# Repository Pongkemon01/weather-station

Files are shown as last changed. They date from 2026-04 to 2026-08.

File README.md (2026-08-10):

# Robin Weather Station

An STM32L476RG-based weather station with cellular data upload, field-O.T.A. firmware updates, a FastAPI ingest + administration server, and a USB-connected Qt desktop configuration utility.

Three distinct codebases live in this repository and share one data story:

1. **Firmware** — bare-metal-ish FreeRTOS application + a separate bootloader for the STM32L476RG.
2. **Server** — FastAPI service that ingests weather records over mTLS, serves firmware images over OTA, and hosts an HTMX admin UI.
3. **Host application** — "Robin WSC", a Qt 6 Widgets desktop tool for connecting to a station over USB CDC and configuring/reading it locally.

Documentation, implementation plans, and as-built test results are in the repo root (see [Documentation](#documentation)).

---

## Hardware & System Context

| Component | Part / Tool |
|---|---|
| MCU | STM32L476RG (Cortex-M4F, 1 MB Flash, 128 KB SRAM) |
| FRAM | CY15B116QN 2 MB (SPI1) — persistent sensor ring DB + OTA staging |
| Modem | SIMCom A7670E LTE (USART3, `AT+HTTP*` only — no CCH/CHTTPS) |
| Sensors | BMP390 (I2C2), SHT45 (I2C2); RS-485 Modbus light (0x01) + rain (0x02) via USART1 |
| UI | LCD + LEDs + buttons through MCP23017 I/O expander (I2C1) |
| Storage | SD card (SDMMC1, FatFs) beside FRAM |
| RTOS | FreeRTOS (CMSIS-RTOS V2) |
| Peripherals | USART1 RS-485 Modbus, USART2 debug console, USART3 A7670 AT, USB OTG FS TinyUSB CDC |

**Sensor → storage → upload pipeline:** `maintask` reads sensors every second, packs readings (Q9.7 fixed-point), stores them in the SPI FRAM ring database and on SD; `ssluploadtask` POSTs a snapshot to the server at noon and midnight over the A7670 LTE modem.

**OTA:** an 8-state OTA manager task downloads firmware images over the modem in 512-byte chunks, verifies SHA-256/CRC-32, and writes them to the FRAM image buffer; the bootloader applies the update to the application flash on next reset. OTA campaigns are controlled from the server admin UI and gated by rollout version strings (`W.<sec>`).

**Local access (USB):** the station enumerates as a USB CDC device (TinyUSB on OTG FS). This USB port serves two purposes: it carries the binary configuration/readout protocol that the Robin WSC desktop app uses to connect to a station (via `QSerialPort`), and it acts as a secondary debug/console channel alongside USART2.

### Internal Flash Layout

```
0x08000000  Bootloader  (32 KB, pages 0–15, Bank 1)   RDP1 + write-protected
0x08008000  Application (480 KB, pages 16–255, Bank 1) ldscript_app.ld
0x08080000  Bank 2      (512 KB — reserved)
```

### Memory Constraints

| Region | Limit |
|---|---|
| App code (`.text` + `.rodata`) | ≤ 480 KB (linker `ASSERT`) |
| App data (`.data` + `.bss`) | ≤ 96 KB (SRAM1) |
| Bootloader flash | 32 KB |
| OTA static chunk buffer | ≤ 512 B |

Current build budget: app ~9.3 % flash / ~22.7 % RAM; bootloader ~0.7 % / ~2.8 % (see `IMPLEMENTATION_STATUS.md`).

---

## Repository Layout

| Path | What it is |
|---|---|
| `Src/` | Application source (CubeMX-generated + `USER CODE` guards). `freertos.c` creates all tasks. |
| `Inc/` | Application headers |
| `lib/` | Libraries: `sensors/` (BMP390, SHT45, Modbus, rain/light), `A7670/` (AT channel, HTTPS upload, SSL OTA download), `SPI_FRAM/` (raw SPI + ring DB), `user_interface/` (MCP23017, LCD), `usart_subsystem/`, `time/`, `utils/` (weather_data, fixed-point), `tinyusb/` (vendored) |
| `shared/` | Compiled into **both** firmware and bootloader: `fram_addresses.h` (single FRAM source of truth), dual-copy `ota_control_block`, CRC-32, SHA-256 |
| `bootloader/` | Separate PlatformIO env, bare-metal (no FreeRTOS): image apply, OCB read/write, FRAM bounce |
| `html/` | FastAPI server (mTLS ingest, OTA endpoints, admin JWT + RBAC, HTMX UI, Prometheus metrics) |
| `server_deployment/`| One-shot shell setup scripts for the Debian host (DB, nginx, systemd, PKI, monitoring) |
| `server_test/` | Python black-box verifiers against the deployed server |
| `host/` | "Robin WSC" — Qt 6.8 Widgets + QSerialPort desktop app (C++17, CMake, ctest tests) |
| `test/` | Extra host-side suites (e.g. OTA size guard — `test_ota_size_guard/`) |
| `Altium Schematics/`| Hardware schematic source |

### FreeRTOS Tasks (firmware)

| Task | File | Period | Priority | Role |
|---|---|---|---|---|
| `UsbLoopTask`  | `freertos.c` | event | High | TinyUSB device loop |
| `cdc_task` | `Src/cdctask.c` | event | High | USB CDC binary protocol (used by the host app) |
| `maintask` | `Src/maintask.c` | 1 s | Normal | Sensor → FRAM + SD |
| `uitask` | `Src/uitask.c` | 20 ms | Normal | LCD refresh, LEDs, button debounce |
| `ucctask` | `Src/ucctask.c` | 100 ms| Normal | LCD menu |
| `ssluploadtask`| `Src/ssluploadtask.c`  | noon+midnight | Normal | HTTPS upload; notifies OTA manager |
| `OtaManagerTask`| `Src/ota_manager_task.c` | after upload | Normal | OTA state machine |
| `WatchdogTask` | `Src/watchdog_task.c`  | 500 ms| High | Per-task heartbeat + IWDG refresh |

---

## Building

Built with **PlatformIO** (`nucleo_l476rg` env, STM32Cube framework). On Windows use `platformio`; on Linux/macOS the WSL helpers below also target WSL2 gcc.

| Action | Command |
|---|---|
| Build application | `platformio run` |
| Build bootloader  | `pio run -e bootloader` |
| Flash application | `platformio run -t upload` |
| Flash bootloader  | `pio run -e bootloader -t upload` |
| Lint | `scripts/lint.sh` (clang-format + cpplint) |
| Unit tests (host, mocked HAL) | `wsl bash //scripts/run_native_tests.sh` |
| RAM usage report  | `scripts/monitor_ram.sh` (budget ≤ 96 KB) |
| Size check | `pio run -t size` |
| Serial monitor | `pio device monitor -b 115200` (USART2 console) |

**Host app (`host/`):** CMake + `ctest`; tests pass cleanly (frame parser, Q9.7 conversion, device controller). Portable Windows build via windeployqt is packaged under `host/packaging/`.

**Server:** deployed by `bash html/scripts/deploy.sh` (scp to the host; the server has no git repo). Environment setup is scripted in `server_deployment/` (`01_setup_server.sh` … `full_setup.sh`) for a Debian host with PostgreSQL 17 + TimescaleDB, nginx mTLS termination, and systemd unit.

---

## Documentation

| Doc | Covers |
|-----|---|
| `CLAUDE.md` | Project conventions, directory map, peripheral allocation, task map, coding standards, "must never do" rules. **Read this first.** |
| `IMPLEMENTATION_STATUS.md` | Single source of truth for phase completion and build budgets |
| `OTA_Firmware_Architecture.md` | Firmware OTA: FRAM layout, state machine, bootloader, A7670 modem flow |
| `Server_Architecture.md` | Server: mTLS ingest, OTA endpoints, slot algorithm, DB schema |
| `Server_Implementation_Plan.md` / `User_Management_Implementation_Plan.md` | Server phase plans |
| `Server_Test_Plan.md` / `User_Management_Test_Plan.md` | Black-box verifier coverage |
| `USART_Subsystem_Migration_Plan.md` | UART subsystem plan |
| `https_manual.md`, `ntp_manual.md` | A7670E AT command references (vendor) |
| `host/host_implementation_plan.md`, `host/CLAUDE.md` | Host app plan & conventions |

---

## Status (as of `IMPLEMENTATION_STATUS.md`)

- **Firmware:** OTA phases P0–P3.2 implemented; remaining work is hardware integration/field testing (P1/P2/P3/P4 items). Open risk **R-12**: verify embedded cert arrays in `*_der.c` are DER (not PEM) bytes before the next fleet build.
- **Server:** all phases complete (S0–S11), including mTLS ingestion, OTA campaigns, admin RBAC, and monitoring.
- **User management:** complete (UM1–UM5).
- **Host app:** complete (Ph0–Ph9), all ctest suites pass.

Security-sensitive components use mTLS (device ingest), JWT + RBAC (admin), RDP1 + write-protection on the bootloader, and Ed25519-signed firmware images.

---

## License

See `LICENSE` in the repository root.

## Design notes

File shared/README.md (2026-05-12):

# shared/ - Robin Weather Station wire protocol

This directory holds the **single source of truth** for the wire protocol
spoken between the Robin Weather Station (STM32L476RG + TinyUSB + FreeRTOS)
and the host configurator application (Qt 6 on Windows / Linux / macOS).

The same `.h` files compile cleanly under:

- `arm-none-eabi-gcc` (firmware target)
- MinGW-w64 GCC (Windows host)
- System GCC (Linux host)
- Apple Clang (macOS host)

## Files

| File | Purpose |
|---|---|
| `protocol_compat.h` | Portability shims: `PACKED`, `STATIC_ASSERT`, endianness guard |
| `protocol_version.h` | Protocol version macros (`ROBIN_PROTOCOL_VERSION_U16`, etc.) |
| `protocol.h` | Authoritative wire-format spec: framing constants, opcodes, error codes, wire structs |

## What's NOT here

- **No CRC.** The protocol relies on USB-CDC's own packet CRC and the
  magic/footer framing for integrity. The firmware's `cdctask.c` does not
  compute a payload CRC; the host must not either.
- **No length field on the wire.** Payload length is implied by the command
  opcode. The receiving side knows how many bytes to read.

## Frame format

```
+---------+---------+---------+----------------------------+---------+---------+
| MAGIC_H | MAGIC_L |   CMD   |         PAYLOAD            | FOOT_H  | FOOT_L  |
|  1 byte |  1 byte |  1 byte |     0..216 bytes           |  1 byte |  1 byte |
+---------+---------+---------+----------------------------+---------+---------+

Host -> Device:   MAGIC = 0xDC 0xB1   FOOTER = 0x23 0x4E   (~MAGIC byte-wise)
Device -> Host:   MAGIC = 0x55 0xAA   FOOTER = 0xAA 0x55
```

All multi-byte numeric fields are **little-endian** (matches STM32 native
order; no byte-swapping needed on x86_64 or ARM64 desktop hosts). The
`__BYTE_ORDER__` check in `protocol_compat.h` enforces this at compile time.

## Commands

| Code | Name | H->D payload | D->H response |
|---|---|---|---|
| `0x01` | `REQ_WEATHER` | (empty) | `Weather_Data_Packed_t` (18B) |
| `0x02` | `REQ_META` | (empty) | `Meta_Data_t` (216B) |
| `0x03` | `SET_META` | `Meta_Data_t` (216B) | ACK echoing `0x03` or NAK + err |
| `0x04` | `SET_RTC` | `RTC_DateTime_t` (6B) | ACK echoing `0x04` or NAK + err |
| `0x05` | `REQ_STATUS` | (empty) | `System_Ready_Status_t` (12B) |
| `0x06` | `DB_FLUSH` | (empty) | ACK echoing `0x06` or NAK + err |
| `0x07` | `SYS_RESET` | (empty) | ACK echoing `0x07`, link then drops |
| `0xFE` | `ACK` | (device only) | 1 byte echoed command code |
| `0xFF` | `NAK` | (device only) | 1 byte error code |

## NAK error codes

| Code | Name | Meaning |
|---|---|---|
| `0x01` | `UNKNOWN_CMD` | CMD byte was not a recognized opcode |
| `0x02` | `INVALID_FOOTER` | One or both footer bytes did not match `~MAGIC` |
| `0x03` | `WRITE_FAILED` | Device-side persistence failed (FRAM, RTC, etc.) |
| `0x04` | `INVALID_DATA` | Payload contents were rejected |

## Wire data types

| Type | Size | Notes |
|---|---|---|
| `RTC_DateTime_t` | 6 B | year/month/day/hours/minutes/seconds, all `uint8_t` |
| `Weather_Data_Packed_t` | 18 B | `time_stamp` is Y2K epoch; sensor fields are Q9.7 fixed-point (`int16_t` / 128.0) |
| `Meta_Data_t` | 216 B | Station configuration; treat as opaque round-trip from host |
| `System_Ready_Status_t` | 12 B | 12 × `uint8_t` boolean readiness flags |

The sizes above are enforced at compile time by `STATIC_ASSERT` in
`protocol.h`. **If any of those static asserts ever fires, the protocol
is broken and host and firmware will not interoperate.** Treat a failing
assert as a release blocker.

## Adding new commands or fields

- **MINOR version bump** is appropriate for: new opcode that older firmware/
  host can safely ignore; new field appended (never inserted) to an existing
  struct.
- **MAJOR version bump** is required for: field reorder, field removal,
  opcode renumbering, magic/footer change, type change.

Either way: update `protocol_version.h` and bump the appropriate macro.

## Why no CRC?

The firmware author chose to rely on the USB-CDC transport's own data
integrity (USB CRC on every bulk packet, automatic retransmission on
errors) plus the start/end magic framing. For a wired full-speed USB
link at 12 Mbit/s this is reasonable. If the protocol is ever extended
to run over a less-reliable transport (wireless, RS-485, etc.) a CRC
would need to be added in a MAJOR version bump.

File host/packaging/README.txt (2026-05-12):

Robin Weather Station Configurator
==================================

Version:      1.0.0
Manufacturer: RobinLab-KU

About
-----

This application is the configuration and monitoring utility for the
Robin Weather Station. It communicates with the device over USB.

Installation
------------

No installation is required.

   1. Extract this folder to any location you like (your Desktop, a USB
      stick, or a network share all work).
   2. Connect the Robin Weather Station to your computer via USB.
   3. Double-click "robin_wsc.exe".

To remove the application, simply delete this folder. No registry entries
or system files are created.

Supported operating systems
---------------------------

   * Windows 10 (build 1809 or later)
   * Windows 11

USB device identification
-------------------------

The Robin Weather Station identifies itself with the following USB IDs:

   Vendor ID:  0x1209  (pid.codes open hardware allocation)
   Product ID: 0xDCB1

The application searches for any connected device with this VID/PID pair.

Open source acknowledgements
----------------------------

This application is built with the Qt framework (https://www.qt.io/),
used under the terms of the GNU Lesser General Public License v3 (LGPLv3).
See COPYING.LGPLv3.txt in this folder for the full Qt license text.

Qt source code is available from https://www.qt.io/download-open-source

The Qt libraries distributed with this application (Qt6Core.dll,
Qt6Gui.dll, Qt6Widgets.dll, Qt6SerialPort.dll, and the qwindows.dll
platform plugin) are unmodified copies of the official Qt 6 release.

Support
-------

For support, please contact RobinLab-KU.

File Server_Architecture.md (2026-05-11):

# IoT Data Server — Architecture

Fleet: 300–1000 STM32L476RG + A7670E LTE devices · 2× daily sensor uploads + pull-model OTA.
Production host: `akp@robin-gpu.cpe.ku.ac.th` (Ubuntu, PG 17 + TimescaleDB 2.27.0-dev from source).
Phase status: `IMPLEMENTATION_STATUS.md`. Implementation plan: `Server_Implementation_Plan.md`. Test plan: `Server_Test_Plan.md`.

---

## 1. Stack

| Component | Choice | Why |
|---|---|-----|
| Language | Python 3.13 | Binary protocol parsing, async I/O |
| Web framework | FastAPI | Async, OpenAPI |
| Reverse proxy | Nginx | mTLS termination at scale |
| DB | PostgreSQL 17 + TimescaleDB | Hypertable + compression for `weather_records` |
| Admin UI | FastAPI + HTMX + Jinja2 | Server-rendered, no SPA build |
| Metrics / logs  | Prometheus + Loki + Promtail + Grafana | `/metrics` bound to 127.0.0.1 |

---

## 2. Authentication

Two distinct models. Devices use mTLS; admins use username/password → JWT. Never mix.

### 2.1 Devices (mTLS, private CA)

| Aspect | Setting |
|---|---|
| Trust anchor | Private intermediate CA (`{html_dir}/pki/private_ca_chain.pem`) |
| Cert scope | One shared **fleet** client cert (CN `iot-fleet`). No per-device CN. |
| Device identity | Payload `(region_id, station_id)` for ingest; `?id=rrrsss` query param for OTA |
| Modem cert format | **DER binary** (no PEM headers). Convert via `openssl x509/rsa -outform DER`. |
| TLS | 1.3 preferred; 1.2 fallback |
| CRL | `{html_dir}/pki/ca.crl`, refreshed weekly by `scripts/refresh_crl.sh`. **Must contain intermediate + root CRLs** (nginx `ssl_crl` validates every chain level). |
| Cert rotation | Fleet client cert: 365 days. Server TLS cert: 365 days. Intermediate CA: annual audit. Root CA: offline, 5-year rotation. |

Embedded cert arrays (`lib/A7670/*_der.c`) loaded onto the modem via `AT+CCERTDOWN` on each cold boot:

| File | Array | Contents |
|---|---|---|
| `server_der.c` | `server_der[]` | Intermediate CA DER (trust anchor for server TLS) |
| `client_der.c` | `client_der[]` | Fleet client cert DER |
| `client_key_der.c` | `client_key_der[]` | Fleet private key DER |

**Revocation = fleet-wide.** Revoking the fleet cert blocks every device. To rotate: re-issue cert, regenerate DER + C arrays, rebuild, reflash all units.

### 2.2 Admins (JWT)

| Aspect | Setting |
|---|---|
| Trust anchor | Let's Encrypt (server cert only — `ssl_verify_client off`) |
| Login | `POST /admin/login` → bcrypt verify → HS256 JWT (24 h) in `access_token` cookie (HttpOnly, SameSite=strict) |
| Auth header | UI: cookie. API: `Authorization: Bearer`. |
| RBAC | viewer (0) < operator (1) < admin (2). Enforced via `require_role` dependency. |
| CSRF | HMAC double-submit on every form mutation (`app/auth/csrf.py`). |
| Password reset | Out-of-band (admin updates DB row directly). |

---

## 3. Data Protocols

### 3.1 Ingest — binary packed struct

```
Header (5 B):  uint16 region_id, uint16 station_id, uint8 chunk_count
Body  (18 B × chunk_count):  Weather_Data_Packed_t
  - uint32 ts                (Y2K epoch — seconds since 2000-01-01 UTC)
  - int16  temperature       (S9.7 fixed-point — see lib/utils/fixedptc.h)
  - int16  humidity          (S9.7)
  - int16  pressure          (S9.7)
  - uint16 light_par         (µmol/s·m², 0–2500, no scaling)
  - int16  rainfall          (S9.7)
  - int16  dew_point         (S9.7)
  - int16  bus_value         (S9.7)
```

S9.7: sign bit + 9-bit whole + 7-bit fraction → float = `int_value / 128.0`.

**Idempotency key:** `"{region:03d}{station:03d}:{first_sample_ts.isoformat()}"` stored in `ingest_log`. Same payload twice → `{"status": "duplicate"}` returned, no second insert.

**Schema (full):**

```sql
CREATE TABLE devices (
  id          SERIAL       PRIMARY KEY,
  region_id   SMALLINT     NOT NULL,
  station_id  SMALLINT     NOT NULL,
  last_seen   TIMESTAMPTZ,
  created_at  TIMESTAMPTZ  DEFAULT now(),
  UNIQUE (region_id, station_id)
);

CREATE TABLE weather_records (
  time        TIMESTAMPTZ  NOT NULL,
  device_id   INT          NOT NULL REFERENCES devices(id),
  temperature REAL, humidity REAL, pressure REAL,
  light_par   SMALLINT,
  rainfall    REAL, dew_point REAL, bus_value REAL
);
SELECT create_hypertable('weather_records', 'time');
ALTER TABLE weather_records SET (
  timescaledb.compress,
  timescaledb.compress_segmentby = 'device_id'
);
SELECT add_compression_policy('weather_records', INTERVAL '7 days');

CREATE TABLE ingest_log (
  idempotency_key VARCHAR(320) PRIMARY KEY,
  recorded_at     TIMESTAMPTZ DEFAULT now()
);
```

### 3.2 OTA — three-phase pull model

Device builds URLs from `UPDATE_PATH + "/"`. All device traffic shares `/api/v1/weather/` (Q-S1 Option B): one Nginx location, one rate-limit zone.

| Phase | URL | Behavior |
|---|-----|---|
| 1. Version + size | `GET <update_path>/?id=rrrsss` | HTML body containing `V.#####:L.$$$$$$$:H.<sha256hex>:W.<seconds>`. `W.0` = download now; `W>0` = skip cycle. Missing `:W.` = `W.0` (back-compat). |
| 2. Chunk download | `GET <update_path>/get_firmware?offset=X&length=Y&id=rrrsss` | Returns `Y` bytes + 4-byte little-endian CRC-32/MPEG-2 trailer. Length clamped to `[1, 512]`; `offset + length > size` → 416. Out-of-slot device → `429 Retry-After: <sec>`. |
| 3. Install | (Device-side) | OCB written; reboot; bootloader programs Flash; `ota_confirm_success()` within 60 s or rollback. |

### 3.3 Rollout slot algorithm

Problem: 1000 devices × 512 KB unthrottled ≈ 4.5 Gbit burst, exceeds VPS cap. A7670E firmware does not follow HTTP 302 → no object-storage offload. Solution: deterministic 20-slot schedule over 10 days, flatten to ~90 KB/s peak.

```python
def compute_wait(device_id: str, campaign) -> int:
    """Returns seconds the device must wait. 0 = download now."""
    slot_len  = campaign.slot_len_sec           # frozen at creation; default 43200 = 12 h
    num_slots = campaign.rollout_window_days * 2  # default 20
    elapsed   = (now_utc - campaign.rollout_start).total_seconds()
    now_slot  = min(num_slots - 1, max(0, int(elapsed // slot_len)))
    dev_slot  = zlib.crc32(device_id.encode("ascii")) % num_slots
    return 0 if dev_slot <= now_slot else (dev_slot - now_slot) * slot_len
```

**Properties:**

- Monotone in time — once eligible, always eligible (failed devices retry next cycle).
- Even distribution — ~50 ± 10 devices/slot at N=1000.
- Stateless per request — no device-progress table needed for slot computation.
- Drift-tolerant — server time end-to-end; device RTC drift irrelevant.
- Slot gate re-checked on every `/get_firmware` request → 429 (defends against clients that ignore `W.`).

**`zlib.crc32` is CRC-32 IEEE (reflected, poly `0xEDB88320`)** — **different** from the CRC-32/MPEG-2 used for chunk trailers. The device does not hash its own id; it reads `W` from the token.

**Schema:**

```sql
CREATE TABLE ota_campaigns (
  id SERIAL PRIMARY KEY,
  version INT NOT NULL UNIQUE,
  description TEXT,
  firmware_sha256 VARCHAR(64) NOT NULL,
  firmware_size   INT          NOT NULL,
  firmware_file_path TEXT NOT NULL,           -- {FIRMWARE_DIR}/v{version}.bin
  rollout_start TIMESTAMPTZ,
  rollout_window_days INT DEFAULT 10,
  slot_len_sec INT NOT NULL DEFAULT 43200,    -- frozen at campaign creation
  target_cohort_ids TEXT[],                   -- NULL or empty = whole fleet (Q-S10)
  status VARCHAR(32) DEFAULT 'draft',
                                              -- draft | scheduled | in_progress | paused
                                              -- | completed | cancelled (Q-S8)
  success_rate NUMERIC,                       -- written on terminal transition (Q-S5)
  created_at TIMESTAMPTZ DEFAULT now(),
  updated_at TIMESTAMPTZ DEFAULT now()
);

CREATE TABLE download_completions (
  campaign_id INT          NOT NULL REFERENCES ota_campaigns(id),
  device_id   VARCHAR(6)   NOT NULL,          -- "{region:03d}{station:03d}"
  chunk_index INT          NOT NULL,          -- offset // 512
  recorded_at TIMESTAMPTZ  DEFAULT now(),
  PRIMARY KEY (campaign_id, device_id, chunk_index)
);

CREATE TABLE admin_users (
  id SERIAL PRIMARY KEY,
  username VARCHAR(64) NOT NULL UNIQUE,
  password_hash VARCHAR(128) NOT NULL,        -- bcrypt cost ≥ 12
  role VARCHAR(16) NOT NULL,                  -- viewer | operator | admin
  created_at TIMESTAMPTZ DEFAULT now()
);
```

**Active-campaign selection (per device):** highest `version` among rows where `status='in_progress'` and (`target_cohort_ids IS NULL OR cardinality(target_cohort_ids)=0 OR device_id = ANY(target_cohort_ids)`). Empty arrays normalised to `NULL` on insert.

**No per-device firmware version tracking on the server.** Device compares `V` vs `FW_VERSION` itself.

**Campaign workflow:** draft → start (sets `rollout_start`, freezes `slot_len_sec`) → in_progress → pause/resume (rollout_start preserved) or cancel/complete (terminal: `success_rate` computed). Field rollback = upload old binary as a new higher-version campaign.

**Live progress** during the rollout window: query `download_completions` for `(campaign_id, device_id)` with `count(chunk_index) >= (firmware_size + 511) // 512` (ceiling). Surfaced via `GET /admin/campaign/{id}` aggregates. **Terminal `success_rate`** is written once at transition.

**Egress envelope (1000 dev, 512 KB, 10 days, device-side 30 min jitter):** ~50 ± 10 dev/slot, ~26 MB/slot, peak ~90 KB/s, average ~14 KB/s, total ~512 MB.

### 3.4 Firmware storage

```
{FIRMWARE_DIR}/v{version}.bin     ← raw binary; filename is canonical key
```

- `FIRMWARE_DIR` must be **absolute** (resolved at startup; app refuses to start otherwise — Q-S11). Mode `0750`; owned by `iotsrv` in prod, `akp` in dev. Excluded from git.
- Atomic write: write `.tmp`, then `os.replace()` only after DB commit succeeds.
- Nginx denies `/firmware/` → 404. Files reach devices only via `/get_firmware`.

**Version assignment:** `new_version = MAX(ota_campaigns.version) + 1` (starts at 1). Admin uploads **only the binary**; size + SHA-256 computed by the server.

**Size ceiling:** `MAX_FIRMWARE_SIZE_BYTES = 480 * 1024` (matches STM32L476RG app Flash partition — `OTA_Firmware_Architecture.md §2`). Upload >480 KB → `413 Request Entity Too Large` **before** writing to disk.

**Integrity on start:** `POST /admin/campaign/{id}/start` recomputes SHA-256 from disk; mismatch with stored value → `409`.

**Retention (Q-S4):** `FIRMWARE_KEEP_N = 3` (configurable). Sweep runs after each upload and after any transition into a terminal state.

- Never delete `.bin` for draft / in_progress / paused campaigns.
- Among terminal (completed / cancelled) campaigns, keep the `N` most recent by `version DESC`; delete the older ones.

**Optional Ed25519 signing (S10-4):** when `SIGNING_PRIVATE_KEY_PATH` is set, the server writes `v{n}.sig` alongside the binary and returns `firmware_ed25519_sig` in the upload response. Bootloader verification is deferred.

---

## 4. Performance Envelope

| Metric | Estimate | Note |
|---|---|---|
| Ingest req/day | 2000 | 1000 dev × 2 uploads — trivial |
| Ingest payload | ~200 B / req  | Binary packed struct |
| TimescaleDB write rate | ~50 rows/s | Fits single vCPU |
| OTA peak egress | ~90 KB/s | With 20-slot rollout + device jitter |
| OTA total egress | ~512 MB / 10 d | 1000 dev × 512 KB |
| asyncpg pool | min 2 / max 20 | Handles 100 concurrent uploads |

---

## 5. Nginx (two listeners, two trust stores — Q-S9)

Devices and browsers terminate on separate `server{}` blocks, selected by SNI. Device vhost = private CA + mTLS required. Admin vhost = Let's Encrypt + no client cert. Eliminates any risk of provisioning the wrong trust anchor to the modem.

`limit_req_zone` keys on `$arg_id` (Q-S3) — `$ssl_client_s_dn` would collapse to a single fleet-wide key.

```nginx
# /etc/nginx/conf.d/iot_server.conf — included inside http{} so http-level directives are valid here
limit_req_zone $arg_id zone=device_api:10m rate=10r/s;

upstream fastapi_backend { server 127.0.0.1:8000; keepalive 32; }

# Device listener
server {
    listen 443 ssl; http2 on;
    server_name robin-gpu.cpe.ku.ac.th;

    ssl_certificate     /etc/ssl/certs/robin-gpu.cpe.ku.ac.th.crt;
    ssl_certificate_key /etc/ssl/private/robin-gpu.cpe.ku.ac.th.key;
    ssl_client_certificate {html_dir}/pki/private_ca_chain.pem;
    ssl_crl               {html_dir}/pki/ca.crl;
    ssl_verify_client     on;
    ssl_verify_depth      2;
    ssl_protocols         TLSv1.3 TLSv1.2;

    location /api/v1/weather/ {
        if ($ssl_client_verify != SUCCESS) { return 403; }
        proxy_set_header X-SSL-Client-Verify $ssl_client_verify;
        proxy_pass http://fastapi_backend;
        proxy_http_version 1.1;
        proxy_set_header Connection "";
        limit_req zone=device_api burst=20;
    }

    location /firmware/ { deny all; return 404; }
    location /          { return 404; }
}

# Admin listener
server {
    listen 443 ssl; http2 on;
    server_name adm.robinlab.cc;

    ssl_certificate     /etc/letsencrypt/live/adm.robinlab.cc/fullchain.pem;
    ssl_certificate_key /etc/letsencrypt/live/adm.robinlab.cc/privkey.pem;
    ssl_verify_client   off;
    ssl_protocols       TLSv1.3 TLSv1.2;

    location /admin/ {
        proxy_pass http://fastapi_backend;
        proxy_http_version 1.1;
        proxy_set_header Connection "";
    }
    location / { return 404; }
}
```

The admin vhost forwards **no** `X-SSL-Client-*` headers (verified by T4-8).

---

## 6. FastAPI Endpoint Map

### Device (mTLS via Nginx; FastAPI verifies `X-SSL-Client-Verify == SUCCESS`)

| Endpoint | Purpose |
|---|---|
| `POST /api/v1/weather/upload` | Ingest binary packed struct |
| `GET  /api/v1/weather/?id=<rrrsss>` | OTA version + wait token |
| `GET  /api/v1/weather/get_firmware?offset=&length=&id=`| OTA chunk + CRC trailer; inserts `download_completions` row |

### Admin (JWT; cookie-based for UI, Bearer for API)

| Endpoint | Min role | Purpose |
|---|---|---|
| `POST /admin/login`, `POST /admin/logout`, `GET /admin/me` | — / viewer | Auth |
| `GET /admin/users` | admin | List users (extended JSON) |
| `POST /admin/users`, `PUT /admin/users/{id}`, `PUT /admin/users/{id}/password`, `DELETE /admin/users/{id}` | (see User_Management_Implementation_Plan.md §UM2) | CRUD (with self-protection guards) |
| `POST /admin/firmware/upload` | admin | Binary upload — auto version + SHA-256 + size; 413 if > 480 KB; retention sweep |
| `POST /admin/campaign/{id}/start | admin | Set `in_progress`; freeze `slot_len_sec`; recompute SHA-256 from disk (409 mismatch) |
| `POST /admin/campaign/{id}/pause | resume | cancel` | operator+ | Lifecycle. `cancel` is terminal; computes `success_rate` and runs retention sweep |
| `GET /admin/campaign/{id}` | viewer+ | Full row + `completed_device_count`, `eligible_device_count`, `current_slot`, `num_slots` |
| UI routes under `/admin/*` | viewer+ | Login, dashboard, campaigns, sensor-data, users, profile |
| `GET /metrics` | — (loopback only) | Prometheus scrape; IP guard rejects non-127.0.0.1 |

---

## 7. Device-Side Requirements

| Requirement | Firmware component |
|---|---|
| TLS 1.2+ mTLS with fleet client cert | A7670E `AT+CSSLCFG` + `AT+CCERTDOWN` (DER format) |
| NTP sync before TLS | `at_channel_send_cntp(12000)` blocks until `+CNTP: 0` |
| Binary ingest | `maintask.c` packs → `ssluploadtask.c` POSTs |
| OTA metadata polling | `OtaManagerTask` GET `<update_path>/?id=rrrsss` |
| OTA rollout gate | On `W>0` return to IDLE (no download) |
| OTA chunk download | `a7670_ssl_downloader.c`; per-chunk CRC; 429 → back off & retry |
| Device identity bounds | `region_id`, `station_id` ∈ `0–999`; URL builder applies `% 1000` (Q-S7) |
| Size guard (defence-in-depth) | Reject `L > FLASH_APP_SIZE_MAX (480 KB)` in `POLLING_VERSION` |
| Whole-image SHA-256 verify | `OtaManagerTask` accumulates during download; bootloader re-verifies pre-program |
| 60 s confirm + IWDG rollback | `ota_confirm_success()`; bootloader retains old app on timeout / SP sanity fail |

See `OTA_Firmware_Architecture.md` for full device-side detail.

---

## 8. Deploy & Ops

**Deploy:** `bash html/scripts/deploy.sh` — scp + extract + `systemctl restart`. Server has **no** git repo. SSH key `~/.ssh/akrapong.key`.

**Blue/green (S10-2):** two units (`iot-server-blue` on :8000, `iot-server-green` on :8001). `scripts/blue_green_deploy.sh` health-checks the inactive slot, swaps `nginx/iot_upstream.conf`, reloads nginx, tracks active slot in `etc/active_slot`.

**Backups (S10-3):** daily `pg_dump → gzip → html/backups/` (14-day retention) via `backup-db.timer`; weekly `restore-test.timer` validates by restoring to a temp DB.

**Alerts (S9-5):**

- Ingest lag > 5 min → page ops
- Cert-verify error rate > 1/min → check CRL freshness
- OTA campaign `success_rate < 0.8` (post-rollout) on cohort ≥ 10 %

---

## 9. Decision Summary

All cross-document open questions are resolved. Body of this doc reflects accepted decisions.

| ID | Decision |
|----|---|
| Q-S1  | All device traffic mounted under `/api/v1/weather/`. One Nginx location, one rate-limit zone. |
| Q-S2  | Firmware sends `?id=` on every OTA request and parses `:W.<seconds>` (missing → `W.0`). |
| Q-S3  | `limit_req_zone` keys on `$arg_id` for per-device throttling (fleet shares one cert). |
| Q-S4  | `FIRMWARE_KEEP_N = 3` retention sweep; non-terminal campaigns never deleted. |
| Q-S5  | `success_rate` written once on terminal status transition; live progress derived from `download_completions`. |
| Q-S6  | Ceiling division `(firmware_size + 511) // 512` everywhere chunk totals matter. |
| Q-S7  | `region_id`, `station_id` ∈ `0–999`; firmware crops `% 1000` at URL-build time. |
| Q-S8  | Terminal abort = `cancelled` (was `rolled_back`). Field rollback = re-upload as new higher version. |
| Q-S9  | Two `server{}` blocks: device vhost (private CA + mTLS) and admin vhost (Let's Encrypt). |
| Q-S10 | `target_cohort_ids` NULL or empty array both mean "whole fleet"; admin write path normalises empty → NULL. |
| Q-S11 | `FIRMWARE_DIR` must be absolute (`Path.resolve()` at startup; refuse to start otherwise). |
| Q-S12 | PG 17 + TimescaleDB from source on production host. No `timescaledb` apt package. |
| Q-S13 | `download_completions` is the sole source for live progress AND terminal `success_rate`. No log-parsing. |

---

## 10. References

- Device firmware: `OTA_Firmware_Architecture.md`
- Binary schema: `lib/utils/weather_data.h`, `lib/utils/fixedptc.h`
- CRC-32/MPEG-2: `shared/crc32.c`
- OTA protocol: `shared/ota_control_block.h`, `lib/A7670/a7670_ssl_downloader.h`
- NTP: `ntp_manual.md`
- HTTPS AT commands: `https_manual.md` (Chapter 16)

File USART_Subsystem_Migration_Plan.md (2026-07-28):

# USART Subsystem Migration: DMA → Interrupt-Based

## Context

The current USART subsystem uses DMA for all RX (circular) and TX transfers. For a system with only two active USART consumers — USART1 at 4800 baud (Modbus RTU) and USART3 at 115200 baud (A7670 LTE modem) — DMA adds unnecessary complexity (circular buffer bookkeeping, ReceiveToIdle coordination, pool-block bookkeeping per half-transfer) that an 80 MHz MCU handles trivially via per-byte interrupts. The new subsystem must be API-compatible — same public functions, same `UART_Ctx_t` consumers, same consumer code unchanged.

**Scope**: Only USART1 (Modbus, 4800 baud) and USART3 (Modem, 115200 baud) are registered via the subsystem. USART2 is the debug console using blocking `HAL_UART_Transmit` — completely outside the subsystem.

---

## Files Modified

| File | Change |
|---|---|
| `lib/usart_subsystem/uart_subsystem.h` | Swap DMA-specific struct fields for interrupt equivalents |
| `lib/usart_subsystem/uart_subsystem.c` | Replace DMA API calls with interrupt equivalents |

**Not modified** (left exactly as-is):
- `Src/stm32l4xx_it.c` — DMA IRQ handlers stay (dormant but harmless)
- `Src/usart.c` — CubeMX DMA config stays (handles allocated but unused)
- `Src/dma.c` — DMA clocks and NVIC stay
- All consumer files (`modbus.c`, `a7670.c`, `a7670_at_channel.c`, etc.)

---

## Step 1: Backup

Copy `lib/usart_subsystem/` → `lib/usart_subsystem_dma_backup/`.

---

## Step 2: Header Changes (`uart_subsystem.h`)

**Only `UART_Ctx_t` struct fields change**. All constants (`MAX_UARTS`, `UART_DMA_BUF_SIZE`, `UART_BLOCK_SIZE`, `UART_POOL_BLOCKS`, `UART_RX_SIZE`), `UART_Packet_t`, and all public API signatures stay identical.

### Replace in `UART_Ctx_t`:

```c
// REMOVE these two fields:
uint8_t  dma_rx_buf[UART_DMA_BUF_SIZE];
uint16_t last_read_ptr;

// ADD these two fields:
uint8_t  rx_ring_buf[UART_DMA_BUF_SIZE];   // software ring buffer (same 256 B)
uint16_t rx_ring_wp;                         // next write position (0..255)
```

### Add TX tracking fields:

```c
const uint8_t *tx_buf_ptr;    // points into caller's buffer during TX
uint16_t       tx_remaining;  // bytes still to transmit
```

---

## Step 3: Source Changes (`uart_subsystem.c`)

### 3a. `UART_Sys_Register()` — replace DMA start with IT start

```c
// REPLACE:
if (HAL_UARTEx_ReceiveToIdle_DMA(huart, ctx->dma_rx_buf,
                                 UART_DMA_BUF_SIZE) != HAL_OK)
// WITH:
ctx->rx_ring_wp = 0;
ctx->tx_buf_ptr = NULL;
ctx->tx_remaining = 0;
if (HAL_UART_Receive_IT(huart, ctx->rx_ring_buf, 1u) != HAL_OK)
```

### 3b. `UART_Sys_Send()` — replace DMA TX with interrupt TX

```c
// REPLACE:
if (HAL_UART_Transmit_DMA(ctx->huart, pData, len) != HAL_OK)
// WITH:
ctx->tx_buf_ptr  = pData;       // const-cast: we only read from it
ctx->tx_remaining = len;
if (HAL_UART_Transmit_IT(ctx->huart, (uint8_t *)pData, 1u) != HAL_OK)
```

```c
// REPLACE timeout cleanup:
HAL_UART_DMAStop(ctx->huart);
// WITH:
HAL_UART_AbortTransmit(ctx->huart);
ctx->tx_remaining = 0;
```

### 3c. `UART_Sys_UnRegister()` — replace DMA stop with abort

```c
// REPLACE:
HAL_UART_DMAStop(ctx->huart);
// WITH:
HAL_UART_Abort(ctx->huart);
```

### 3d. ISR Callbacks

**`HAL_UART_TxCpltCallback`** — fires after each 1-byte TX chunk. Re-arms until all bytes sent, then signals semaphore:

```c
void HAL_UART_TxCpltCallback(UART_HandleTypeDef *huart)
{
    if (xFreeQueue == NULL)
        return;

    UART_Ctx_t *ctx = NULL;
    for (int i = 0; i < registered_count; i++)
    {
        if (uart_ctx_array[i].huart->Instance == huart->Instance)
        {
            ctx = &uart_ctx_array[i];
            break;
        }
    }
    if (!ctx)
        return;

    BaseType_t xWoken = pdFALSE;

    if (ctx->tx_remaining > 1u)          // more bytes to send
    {
        ctx->tx_remaining--;
        ctx->tx_buf_ptr++;
        HAL_UART_Transmit_IT(huart, (uint8_t *)ctx->tx_buf_ptr, 1u);
    }
    else                                  // last byte just completed
    {
        ctx->tx_remaining = 0u;
        xSemaphoreGiveFromISR(ctx->tx_done_sem, &xWoken);
    }

    portYIELD_FROM_ISR(xWoken);
}
```

**`HAL_UART_RxCpltCallback`** — fires on every single received byte. Ring-buffered, flushes when full:

```c
void HAL_UART_RxCpltCallback(UART_HandleTypeDef *huart)
{
    UART_Ctx_t *ctx = NULL;
    for (int i = 0; i < registered_count; i++)
    {
        if (uart_ctx_array[i].huart->Instance == huart->Instance)
        {
            ctx = &uart_ctx_array[i];
            break;
        }
    }
    if (!ctx || xFreeQueue == NULL)
        return;

    /* Store received byte into ring buffer */
    uint16_t wp = ctx->rx_ring_wp;
    ctx->rx_ring_buf[wp] = ctx->rx_ring_buf[0];  // HAL wrote byte to [0]
    wp = (wp + 1u) % UART_DMA_BUF_SIZE;
    ctx->rx_ring_wp = wp;

    /* Re-arm for next byte (HAL state is READY after callback) */
    HAL_UART_Receive_IT(huart, ctx->rx_ring_buf, 1u);

    /* If ring is full, flush now — can't wait for IDLE */
    if (ctx->rx_ring_wp == 0u)
        rx_ring_flush(ctx);
}
```

**`HAL_UARTEx_RxEventCallback`** — fires on IDLE line detection. Flushes accumulated ring data to the RX queue:

```c
void HAL_UARTEx_RxEventCallback(UART_HandleTypeDef *huart, uint16_t Size)
{
    UART_Ctx_t *ctx = NULL;
    for (int i = 0; i < registered_count; i++)
    {
        if (uart_ctx_array[i].huart->Instance == huart->Instance)
        {
            ctx = &uart_ctx_array[i];
            break;
        }
    }
    if (!ctx || xFreeQueue == NULL)
        return;

    (void)Size;  /* unused — we track position via rx_ring_wp */

    if (ctx->rx_ring_wp > 0u)
    {
        rx_ring_flush(ctx);
        ctx->rx_ring_wp = 0u;
    }

    /* Re-arm for next bytes */
    HAL_UART_Receive_IT(huart, ctx->rx_ring_buf, 1u);
}
```

**`rx_ring_flush`** — static helper replacing the inline memcpy logic:

```c
static void rx_ring_flush(UART_Ctx_t *ctx)
{
    uint16_t len = ctx->rx_ring_wp;
    if (len == 0u)
        return;

    /* BUG-2: clamp to UART_BLOCK_SIZE */
    if (len > UART_BLOCK_SIZE)
        len = UART_BLOCK_SIZE;

    BaseType_t xWoken = pdFALSE;
    uint8_t *pBuf = NULL;

    if (xQueueReceiveFromISR(xFreeQueue, &pBuf, &xWoken) != pdPASS)
    {
        /* Pool exhausted — drop data */
        portYIELD_FROM_ISR(xWoken);
        return;
    }

    memcpy(pBuf, ctx->rx_ring_buf, len);

    UART_Packet_t pkt = {.payload = pBuf, .length = len, .huart = ctx->huart};
    if (xQueueSendFromISR(ctx->rx_queue, &pkt, &xWoken) != pdPASS)
    {
        /* Queue full — return buffer to pool */
        xQueueSendFromISR(xFreeQueue, &pBuf, &xWoken);
    }

    portYIELD_FROM_ISR(xWoken);
}
```

**`HAL_UART_ErrorCallback`** — restart RX receive on error:

```c
void HAL_UART_ErrorCallback(UART_HandleTypeDef *huart)
{
    UART_Ctx_t *ctx = NULL;
    for (int i = 0; i < registered_count; i++)
    {
        if (uart_ctx_array[i].huart->Instance == huart->Instance)
        {
            ctx = &uart_ctx_array[i];
            break;
        }
    }
    if (!ctx || xFreeQueue == NULL)
        return;

    ctx->rx_ring_wp = 0u;
    HAL_UART_Receive_IT(ctx->huart, ctx->rx_ring_buf, 1u);
}
```

---

## Step 4: Verification

### Build
```bash
platformio run
```
Expected: 0 errors, 0 warnings.

### Functional test (flash + serial monitor)
1. `platformio run -t upload`
2. `pio device monitor -b 115200` — verify console output
3. Modbus reads succeed — light/rain sensor data appears in logs
4. Modem init succeeds — A7670 AT OK, NTP sync, cert injection
5. Sensor data written to FRAM
6. HTTPS upload succeeds at noon/midnight

### Memory
```bash
scripts/monitor_ram.sh
```
Expected: SRAM usage unchanged or slightly lower (DMA buffers dormant, ring buffers same size).

### Rollback
Copy `lib/usart_subsystem_dma_backup/` → `lib/usart_subsystem/`, rebuild.

---

## Design Decisions

1. **1-byte-at-a-time RX** (`HAL_UART_Receive_IT`, len=1): HAL state machine allows re-arm from `RxCpltCallback`. At 115200 baud, one interrupt every 87 μs — negligible on 80 MHz Cortex-M4.

2. **Software ring buffer** (256 B): Same capacity as old DMA buffer. Full-ring triggers immediate flush (matches old BUG-2 overflow behavior). IDLE detection triggers normal flush.

3. **1-byte-at-a-time TX** with re-arm from `TxCpltCallback`: Safe because `UART_Sys_Send` blocks on `tx_done_sem` — caller's buffer is alive for the entire transfer.

4. **CubeMX config untouched**: DMA handles allocated but no transfer is initiated. Rollback is a simple file copy.

5. **USART2 not in scope**: Debug console uses blocking `HAL_UART_Transmit` — never touches the subsystem.

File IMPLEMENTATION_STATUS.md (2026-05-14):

# Implementation Status

Single source of truth for phase completion. One line per phase.
Detail per phase lives in the relevant architecture / implementation-plan doc.

---

## Firmware (OTA)

Architecture: `OTA_Firmware_Architecture.md`

| Phase | Description | Code | Hardware test |
|---|---|---|---|
| P0 | Prerequisite hardening (mutex, snapshot DB, watchdog, FRAM layout) | ✓ 2026-04-16 | — |
| P1 | Bootloader (dual-copy OCB, boot_flash, boot_fram, cache mgmt) | ✓ 2026-04-16 | ⏳ P1-9..P1-12 pending |
| P2 | Download infra (CRC-32/MPEG-2, SSL downloader, image writer, SHA-256) | ✓ 2026-04-17 | ⏳ P2-5, P2-6 pending |
| P2.1  | Upload migration to `AT+HTTP*` (CCH eliminated; 512 B blob, 28 rec) | ✓ 2026-04-18 | ⏳ P2.1-10..12 pending |
| P3 | OTA manager task (8-state machine, version parse, NTP fix R-11) | ✓ 2026-04-19 | ⏳ P3-7, P3-8 pending |
| P3.1  | Rollout gate (`W.<sec>`) + device identity (`?id=rrrsss`) | ✓ 2026-04-21 | ⏳ P3.1-8..10 pending |
| P3.2  | Image size guard (`FLASH_APP_SIZE_MAX = 480 KB`) | ✓ 2026-05-11 (host 6/6) | ⏳ P3.2-6, P3.2-7 pending |
| P4 | Integration & field testing (end-to-end, power-loss, RDP1) | — | ⏳ P4-1..P4-7 pending |

Build budget (current): app 22.7 % RAM / 9.3 % Flash; bootloader 2.8 % RAM / 0.7 % Flash.

---

## Server

Plan: `Server_Implementation_Plan.md` · Test plan: `Server_Test_Plan.md` · Host: `akp@robin-gpu.cpe.ku.ac.th`

| Phase | Description | Status |
|---|---|---|
| S0  | Host provisioning (Debian 13, PG 17 + TimescaleDB 2.27.0-dev, UFW) | ✓ 2026-04-26 |
| S1  | FastAPI scaffold, gunicorn, systemd | ✓ 2026-04-26 |
| S2  | DB schema (devices, weather_records hypertable, ota_campaigns, download_completions, admin_users, ingest_log), migrations, asyncpg pool | ✓ 2026-04-26 |
| S3  | mTLS ingestion `/api/v1/weather/upload` | ✓ 2026-04-26 |
| S4  | Nginx mTLS termination, PKI (private CA + fleet client cert), CRL, Let's Encrypt admin vhost | ✓ 2026-05-06 |
| S5  | OTA device endpoints (`/`, `/get_firmware`) — slot algo, 429, CRC trailer | ✓ 2026-05-06 |
| S6  | Admin JWT auth + RBAC (admin / operator / viewer) | ✓ 2026-05-06 |
| S7  | Admin OTA campaign management REST API (upload, start, pause, cancel) | ✓ 2026-05-07 |
| S8  | Admin UI (HTMX + Jinja2 — login, dashboard, campaigns) | ✓ 2026-05-07 |
| S9  | Observability (Prometheus + Loki + Promtail + Grafana, custom metrics, alerts) | ✓ 2026-05-07 |
| S10 | CI/CD (GH Actions), blue/green deploy, daily PG backups, Ed25519 signing | ✓ 2026-05-07 |
| S11 | Sensor data browse UI (filters: region, station, date range, BUS) | ✓ 2026-05-07 |

---

## User Management

Plan: `User_Management_Implementation_Plan.md` · Test plan: `User_Management_Test_Plan.md`

| Phase | Description | Status |
|---|---|---|
| UM1 | DB query layer (7 functions in `html/app/db/queries.py`) | ✓ 2026-05-08 |
| UM2 | JSON API endpoints (4 new + list extension in `html/app/routers/admin.py`) | ✓ 2026-05-08 |
| UM3 | HTML UI routes (6 routes in `html/app/routers/ui.py`) | ✓ 2026-05-08 |
| UM4 | Templates (`users.html`, `profile.html`, partials, nav) | ✓ 2026-05-08 |
| UM5 | Modal routes (`new-modal`, `edit-modal` + `user_form_modal.html` partial)  | ✓ 2026-05-08 |

---

## Host Application (Robin WSC)

Constraints: `host/CLAUDE.md` · Stack: Qt 6.8 Widgets + QSerialPort, C++17, MinGW-w64

Backend (completed before new UI plan):

| Phase | Description | Status |
|---|---|---|
| H0 | Project scaffold (CMake, Qt, warning flags, app_info.h, resource file, smoke-test MainWindow) | ✓ 2026-05-13 |
| H1 | Wire protocol layer — `FrameParser` (6-state D→H state machine, opcode-length table, resync) + 13 Qt Test cases | ✓ 2026-05-14 |
| H2 | Device communication — `DeviceIO` (IO thread, `QSerialPort`, H→D frame build, parser feed) + `DeviceController` (UI-thread owner, `QThread` lifecycle, all cross-thread signals `Qt::QueuedConnection`) | ✓ 2026-05-14 |

UI plan phases:

| Phase | Description | Status |
|---|---|---|
| Ph0 | Shell rewrite — 5-tab `QTabWidget` (Status / Current Measurement / General Settings / Sensor Settings / About), Help menu (Debug Log… Ctrl+L, About), window icon, banner `QLabel` | ✓ 2026-05-14 |
| Ph1 | Connection lifecycle — device picker dialog, auto-connect (0/1/2+ device logic), protocol-mismatch banner, status-bar mirror | ✓ 2026-05-14 |
| Ph2 | DeviceController request/response API — typed slots per opcode, `m_metaCache`, 1500 ms per-request timeout | ✓ 2026-05-14 |
| Ph3 | Status tab — 11 subsystem indicators, RTC display, Update RTC, Clear Database, Re-connect, 2 s poll | ✓ 2026-05-14 |
| Ph4 | Current Measurement tab — 7-row sensor table, 1 s `REQ_WEATHER` poll, Q9.7 conversion | ✓ 2026-05-14 |
| Ph5 | General Settings tab — Region/Station ID, Sampling Interval, server URLs; load/Apply/Discard via `m_metaCache` | ✓ 2026-05-14 |
| Ph6 | Sensor Settings tab — 5 calibration adjusts; shares `m_metaCache` with Ph5 | ✓ 2026-05-14 |
| Ph7 | About tab — icon, product name, copyright, version string | ✓ 2026-05-14 |
| Ph8 | Debug Log dialog — `LogBuffer` viewer, live tail, Copy All, Ctrl+L wire-up | ✓ 2026-05-14 |
| Ph9 | Build & package — new sources in CMakeLists, ctest clean, windeployqt portable zip | ✓ 2026-05-14 |

Test coverage: `tests/frame_parser_test.cpp` (13/13) · `tests/q97_conversion_test.cpp` (12/12) · `tests/device_controller_test.cpp` (9/9) — all pass.

---

## Verification Suites

| Suite | Scope | Result |
|---|---|---|
| T0  | Harness bootstrap (parity: CRC-32/MPEG-2, fixed-point S9.7, packed struct) | ✓ |
| T1  | Ingest path | ✓ 9/9 |
| T2  | OTA download (incl. slot determinism, 429, resumable, completions tracking) | ✓ 18/18 |
| T3  | Admin campaign lifecycle | ✓ 25/25 |
| T4  | mTLS + Nginx controls | ✓ 6/6 (T4-3, T4-6 N/A) — 2026-05-07 |
| T5  | Soak + load + failure modes (`pytest -m slow`, 300 s soak) | ✓ 8/8 — 2026-05-07 |
| T6  | Sensor data browse UI | ✓ 10/10 — 2026-05-07 |
| T7 / TUM0–11 | User management black-box  | ✓ 75/75 — 2026-05-08 |
| S6 / S8 unit | Admin auth (7) + admin UI E2E (14) | ✓ — 2026-05-07 |
| P3.2 host | OTA size guard — `ovp_parse` + `FLASH_APP_SIZE_MAX` (native gcc / WSL) | ✓ 6/6 — 2026-05-11 |
| H1 host | `FrameParser` — all opcodes, resync, split feeds, payload integrity, reset | ✓ 13/13 — 2026-05-14 |
| H2 host | `DeviceController` frame routing — typed signals, cache, raw pass-through  | ✓ 9/9 — 2026-05-14 |
| H4 host | Q9.7 fixed-point — round-trip, saturation, typical sensor values | ✓ 12/12 — 2026-05-14 |

---

## Outstanding

**Host Application:** all phases complete (Ph0–Ph9). Portable zip: `host/packaging/RobinWSC-1.0.0-win64.zip` (12.4 MB).

**Firmware integration tests:** P1-9..P1-12, P2-5/6, P2.1-10..12, P3-7/8, P3.1-8..10, P3.2-6/7 and field/integration tests P4-1..P4-7. Server side: complete.

Open risk: **R-12** — cert format. Verify `*_der.c` arrays actually contain DER (not PEM) bytes before next field deployment.

---

## Deploy

`bash html/scripts/deploy.sh` (scp + extract + `systemctl restart`; server has no git repo). SSH key `~/.ssh/akrapong.key`.

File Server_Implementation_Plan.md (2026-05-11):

# Server Implementation Plan

> Phase summary for the IoT data server. All server phases (S0–S11) are complete.
> Architecture: `Server_Architecture.md` · Test plan: `Server_Test_Plan.md` · Status: `IMPLEMENTATION_STATUS.md`.
> Host: `akp@robin-gpu.cpe.ku.ac.th` · Deploy: `bash html/scripts/deploy.sh` (scp; server has no git repo).

---

## Directory Layout (inside `html/`)

```
html/
├── app/                       FastAPI package
│   ├── main.py                ; app factory, router mounts, lifespan, logging_config bootstrap
│   ├── config.py              ; Pydantic settings — DB_DSN, JWT_SECRET, FIRMWARE_DIR (must be absolute),
│   │                          ;   FIRMWARE_KEEP_N=3, SLOT_LEN_SEC=43200, MAX_FIRMWARE_SIZE_BYTES=491520
│   ├── deps.py
│   ├── metrics.py             ; custom Prometheus counters/histograms/gauges
│   ├── logging_config.py      ; RotatingFileHandler → html/logs/app.log (JSON)
│   ├── templating.py          ; Jinja2 singleton
│   ├── routers/
│   │   ├── weather.py         ; POST /api/v1/weather/upload          (mTLS)
│   │   ├── ota.py             ; GET / , GET /get_firmware            (mTLS)
│   │   ├── admin.py           ; JSON admin API (auth, campaigns, users)
│   │   └── ui.py              ; HTML routes (login, dashboard, campaigns, sensor-data, users, profile)
│   ├── db/
│   │   ├── pool.py            ; asyncpg.create_pool(min=2, max=20) in lifespan
│   │   ├── schema.sql
│   │   ├── migrations/        ; numbered .sql files; tracked in schema_migrations
│   │   └── queries.py         ; parameterised SQL (no ORM)
│   ├── auth/
│   │   ├── mtls.py            ; verifies X-SSL-Client-Verify == SUCCESS
│   │   ├── jwt.py             ; bcrypt + HS256 + require_role
│   │   └── csrf.py            ; HMAC-signed double-submit
│   ├── ota/
│   │   ├── parser.py          ; struct.unpack for packed binary ingest
│   │   ├── fixedpt.py         ; S9.7 → float (mirrors lib/utils/fixedptc.h)
│   │   ├── crc32.py           ; CRC-32/MPEG-2 (mirrors shared/crc32.c)
│   │   └── campaign.py        ; get_active_campaign_for_device, compute_wait
│   └── templates/             ; Jinja2 base + partials
├── firmware/                  ; binaries — mode 0750; NOT in git
├── logs/                      ; JSON app log — NOT in git
├── pki/                       ; CA chain + CRL — mode 0700 — NOT in git
├── backups/                   ; daily pg_dump output — NOT in git
├── etc/                       ; iot.env — NOT in git
├── nginx/                     ; iot_server.conf, iot_upstream*.conf
├── systemd/                   ; iot-server-{blue,green}.service, refresh-crl, backup-db, restore-test units
├── monitoring/                ; prometheus/, loki/, promtail/, grafana/{dashboards,provisioning}
├── scripts/                   ; deploy, migrate, provision_ca, issue_device_cert, refresh_crl,
│                              ;   backup_db, restore_test, blue_green_deploy, generate_signing_key
├── tests/                     ; html-side unit tests (pytest)
├── requirements.txt
└── pyproject.toml
```

---

## Phase Summary

All phases complete. Verification suites in `server_test/` documented in `Server_Test_Plan.md`.

| Phase | Description | Status (date) |
|---|---|---|
| S0  | Host provisioning — Debian 13, Python 3.13, PG 17 + TimescaleDB 2.27.0-dev from source, UFW (22 + 443 only), `weather` DB owned by `akp`, peer auth via Unix socket | ✓ 2026-04-26 |
| S1  | FastAPI scaffold, gunicorn + uvicorn worker, systemd unit, `/health`, `iot.env` loader | ✓ 2026-04-26 |
| S2  | Schema (`devices`, `weather_records` hypertable + 7-day compression policy, `ingest_log`, `ota_campaigns`, `download_completions`, `admin_users`, `schema_migrations`), asyncpg pool | ✓ 2026-04-26 |
| S3  | `POST /api/v1/weather/upload` — packed-struct parse, S9.7 → float, Y2K epoch → TIMESTAMPTZ, idempotency on `{rrr}{sss}:{first_ts.isoformat()}`, device upsert | ✓ 2026-04-26 |
| S4  | Two-listener Nginx (private CA device vhost, Let's Encrypt admin vhost), CRL refresh timer, fleet client cert issuance, DER conversion + C array generation for modem | ✓ 2026-05-06 |
| S5  | `GET /api/v1/weather/?id=` + `GET /api/v1/weather/get_firmware`, `compute_wait()` slot algo, 429 on out-of-slot, CRC-32/MPEG-2 trailer, `aiofiles` chunked read, `download_completions` insert on every served chunk | ✓ 2026-05-06 |
| S6  | JWT auth — `login`, `logout`, `me`, `users`. `require_role` factory with hierarchy viewer(0) < operator(1) < admin(2) | ✓ 2026-05-06 |
| S7  | Admin campaign API — upload (binary only, server assigns version, 413 over 480 KB, atomic `os.replace`, retention sweep), start (recompute SHA-256 from disk → 409 on mismatch, freeze `slot_len_sec`), pause/resume/cancel (rollout_start preserved across pause), success_rate on terminal transition | ✓ 2026-05-07 |
| S8  | Admin UI — login + CSRF, dashboard (device list HTMX-paginated), campaigns (upload form, detail with 15 s polling, lifecycle buttons). Cookie-based JWT (HttpOnly, SameSite=strict) | ✓ 2026-05-07 |
| S9  | Prometheus instrumentator on `/metrics` (loopback only, IP-guard middleware), custom metrics (`ingest_chunks_total`, `ingest_duplicates_total`, `ingest_lag_seconds`, `ota_chunks_served_total`, `cert_verify_failures_total{reason}`, `ota_campaign_success_rate`), JSON logging, Loki + Promtail, Grafana dashboard (8 panels), alert rules | ✓ 2026-05-07 |
| S10 | GH Actions CI (ruff + pytest) + deploy workflow; blue/green systemd units + swap script; daily pg_dump + weekly restore-test timers; Ed25519 firmware signing (server emits `v{n}.sig` when key set; bootloader verification deferred) | ✓ 2026-05-07 |
| S11 | Sensor data browse UI — `GET /admin/sensor-data` + `/admin/sensor-data/table` (HTMX partial). Filters: region_id, station_id, date range, BUS min/max. Default `date_from = today − 7 days`. `::date` cast in `_weather_filter()` for asyncpg type inference | ✓ 2026-05-07 |

User-management phases (UM1–UM5): see `User_Management_Implementation_Plan.md`.

---

## PKI Provisioning Runbook (one-time, condensed)

PKI artifacts live on an admin workstation, **not** the server. Generated via WSL Ubuntu (root path: `/home/akp/iot_pki/`).

1. `provision_ca.sh /home/akp/iot_pki` — root CA (4096-bit, mode 400), intermediate CA (2048-bit), `private_ca_chain.pem`, initial empty CRL.
2. **Move `root.key` to air-gapped USB**; `shred -u` on-disk copy.
3. `issue_device_cert.sh robin-gpu.cpe.ku.ac.th /home/akp/server_cert /home/akp/iot_pki` — server TLS cert for device vhost (uses `v3_device` extension; openssl warns but nginx serves correctly).
4. `issue_device_cert.sh iot-fleet /home/akp/fleet_cert /home/akp/iot_pki` — fleet client cert (365 days). Key **never copied to server**; stored on USB alongside root.key.
5. **Convert PEM → DER + C arrays** (`scripts/pem_to_c_array.sh`):

   | Source PEM | DER output | C array file | Symbol |
   |------------|-----------|--------------|--------|
   | `intermediate.crt` | `intermediate.der` (1132 B) | `lib/A7670/server_der.c` | `server_der[]` |
   | `iot-fleet.crt`    | `iot-fleet.der` (870 B)     | `lib/A7670/client_der.c` | `client_der[]` |
   | `iot-fleet.key`    | `iot-fleet-key.der` (1216 B)| `lib/A7670/client_key_der.c` | `client_key_der[]` |

6. Rebuild + flash firmware: `platformio run -t upload`. Modem calls `AT+CCERTDOWN` on cold boot; confirm with `AT+CCERTLIST`.
7. Copy `intermediate/`, `private_ca_chain.pem`, `ca.crl` (concatenated intermediate + root CRLs) to server `html/pki/`. Server TLS cert → `/etc/ssl/certs/`, key → `/etc/ssl/private/`.
8. Let's Encrypt admin vhost: `certbot certonly --nginx -d adm.robinlab.cc --agree-tos --non-interactive`.
9. Install `nginx/iot_server.conf` to `/etc/nginx/conf.d/`; `nginx -t && systemctl reload nginx`.
10. Install `refresh-crl.service` + `refresh-crl.timer` (weekly, `Persistent=true`, `RandomizedDelaySec=3600`).

**Renewal (annual).** Re-issue fleet cert with new output dir, regenerate DER + C arrays, rebuild, flash all units. Old cert can be revoked once all units update.
**Revocation = fleet-wide.** `openssl ca -revoke iot-fleet.crt -config /home/akp/iot_pki/intermediate/ca.conf` → `refresh_crl.sh` on server → reload nginx → all units blocked simultaneously. Issue new fleet cert and reflash.

---

## References

- `Server_Architecture.md` — full architecture spec
- `Server_Test_Plan.md` — verification harness (T0–T6)
- `IMPLEMENTATION_STATUS.md` — phase status
- `User_Management_Implementation_Plan.md` + `User_Management_Test_Plan.md` — UM phases & tests
- `lib/utils/weather_data.h`, `lib/utils/fixedptc.h` — binary schema source of truth
- `shared/crc32.c` — CRC-32/MPEG-2 firmware implementation
- `lib/A7670/a7670_ssl_downloader.h`, `Src/ota_manager_task.c` — device OTA path

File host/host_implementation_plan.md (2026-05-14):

# Robin Weather Station Configurator — Implementation Plan

## Context

The host application skeleton at `C:\Users\akrap\weather-station\host\` already has a fully working backend layer (USB CDC discovery + open, frame send/recv state machine, in-memory log ring, app constants) but only a placeholder `mainwindow.ui` containing a smoke-test "Rescan" button and list. The user has provided 5 tab screenshots that fix the visual contract: **Status**, **Current Measurement**, **General Settings**, **Sensor Settings**, **About**. Internal per-tab logic will be specified later — this plan is the structural skeleton-to-shipping path.

The wire protocol in `shared/protocol.h` already covers everything the screenshots demand: `REQ_STATUS / REQ_WEATHER / REQ_META / SET_META / REQ_RTC / SET_RTC / DB_FLUSH / SYS_RESET`. No firmware changes are needed.

User-confirmed contract:
- **Connect:** auto-open if exactly one device matches `0x1209:0xDCB1`; show picker dialog only when 2+ match; banner when zero.
- **Log surface:** hidden Debug-Log dialog reachable from a Help menu / shortcut. No permanent log panel.
- **Sampling interval:** `QComboBox` with fixed presets `1, 5, 10, 15, 30, 60` minutes; `uint8_t` value = literal minute count; default 10.
- **Polling:** Status tab `REQ_STATUS` every **2 s**; Current Measurement tab `REQ_WEATHER` every **1 s**. Pause when tab not visible.

---

## Existing assets to reuse (do NOT rewrite)

| Asset | Location | Role |
|---|---|---|
| `app_info.h` constants | `src/app_info.h` | VID/PID, version, baud, log capacity — all populated |
| `LogBuffer` ring + signals | `src/log_buffer.{h,cpp}` | `append/snapshot/clear`, thread-safe; bind directly to log dialog |
| `FrameParser` state machine | `src/frame_parser.{h,cpp}` | `payloadLen()` already covers Weather=18, Meta=216, Status=12, ACK/NAK=1 |
| `DeviceIO` worker | `src/device_io.{h,cpp}` | Serial open + frame send/recv on its own `QThread` — no changes needed |
| `DeviceController::findDevices()` | `src/device_controller.cpp:52` | VID/PID enumeration |
| Existing signal contract | `device_controller.h` | `connected/disconnectedSignal/errorOccurred/frameReceived/protocolMismatch/fatalIncompatibility` — keep as-is |
| Frame parser tests | `tests/frame_parser_test.cpp` | 25 cases; keep, extend pattern for new units |

---

## Phases

### Phase 0 — Shell rewrite & resources
**Goal:** replace skeleton `mainwindow.ui` stub with the real 5-tab shell + menu bar + icon, no per-tab logic yet.

- Rewrite `src/mainwindow.ui`: top-level `QTabWidget` with 5 empty `QWidget` pages named `Status / Current Measurement / General Settings / Sensor Settings / About`. Add `QMenuBar` with `Help` menu containing `Debug Log…` (Ctrl+L) and `About` actions.
- Add icon: place `screenshots/Icon.png` (or resized copy) under `resources/icons/robin_wsc.png`; register in `resources/robin_wsc.qrc`. Wire as window/app icon in `MainWindow` constructor and `main.cpp` `QApplication::setWindowIcon`.
- Add a slim non-modal "banner" `QLabel` (hidden by default, top of central widget) for protocol-mismatch / no-device / many-devices messages. Single helper `MainWindow::showBanner(QString, BannerKind)`.
- **Verify:** `cmake --build build/release` succeeds; `robin_wsc.exe` runs, shows 5 named tab headers + window icon + Help menu (entries do nothing yet).

### Phase 1 — Connection lifecycle
**Goal:** boot the user-confirmed auto-connect flow and surface state.

- New `src/dialogs/device_picker_dialog.{h,cpp,ui}` — modal, lists `QSerialPortInfo` rows by `serialNumber()`, double-click or OK selects.
- In `MainWindow::initialise()` (called after `show()`): call `DeviceController::findDevices()`; 1 → auto-`connectTo`; 0 → banner "No Robin Weather Station detected"; ≥2 → open picker, then `connectTo` chosen.
- Wire `Re-connect` button on Status tab (added in Phase 3) to repeat the same flow with `disconnect()` first.
- Hook existing `DeviceController::protocolMismatch` to non-modal banner; `fatalIncompatibility` to modal `QMessageBox::critical` then disable all tab content (keep only Status tab interactive).
- Status-bar text mirror of `connected/disconnectedSignal`.
- **Verify:** plug device → Status header turns green "Connected"; unplug → "Disconnected"; spoof second device via stub → picker appears.

### Phase 2 — DeviceController request/response API
**Goal:** turn the existing scaffold into a typed request layer the tabs can call.

- Extend `DeviceController` with one slot per logical command, each returning `void` and emitting a typed completion signal:
  - `requestStatus()` → `statusReceived(System_Ready_Status_t)` / `requestTimedOut(quint8 op)`
  - `requestWeather()` → `weatherReceived(Weather_Data_Packed_t)`
  - `requestMeta()` → `metaReceived(Meta_Data_t)`
  - `setMeta(Meta_Data_t)` → `metaWriteAck(bool ok, quint8 nakCode)`
  - `requestRtc()` → `rtcReceived(RTC_DateTime_t)` (already declared as slot — implement)
  - `setRtc(RTC_DateTime_t)` → `rtcWriteAck(bool ok)`
  - `clearDatabase()` → `dbFlushAck(bool ok)`
- Cache the most recent `Meta_Data_t` inside `DeviceController` (`m_metaCache`) — both settings tabs read/write through this cache so they share one round-trip on Discard. `metaCache()` getter; `invalidateMetaCache()` on disconnect.
- Add per-request timeout: a single `QTimer` keyed on outstanding opcode (max one in-flight; queue if multiple). 1500 ms default. Timeout emits `requestTimedOut(opcode)` and the originating slot's failure signal.
- Use the existing `frameReceived(quint8, QByteArray)` signal as input; route by opcode using `static_cast` + `STATIC_ASSERT(sizeof(...)==N)` (the structs already carry these asserts in `protocol.h`).
- **Verify:** add `tests/device_controller_test.cpp` driving `DeviceController` against a fake `QIODevice` that produces canned frames; assert each request emits its typed signal and timeouts fire.

### Phase 3 — Status tab
**Goal:** match `screenshots/Status_Tab.png`.

- New `src/tabs/status_tab.{h,cpp,ui}` (`QWidget` subclass).
- Layout: header row "Device status: <text>" + `Re-connect` button right-aligned; grid of 11 status rows (each = small colored `QLabel` swatch + name) in a 6×2 layout matching the screenshot order; horizontal separator; "Computer Date-Time" + "Device RTC Date-Time" rows; `Update RTC to the Computer Time` button right-aligned; separator; red `Clear Database` button bottom-left.
- `QTimer` 2 s polling `requestStatus()` while tab visible; pause on `tabBar::currentChanged` away.
- `Update RTC` builds `RTC_DateTime_t` from `QDateTime::currentDateTime()` and calls `setRtc()`. On ack, immediately `requestRtc()` to refresh display.
- `Clear Database` opens `QMessageBox::warning` with `Yes/No` confirmation; on confirm, `clearDatabase()`. On ack, briefly highlight the button.
- `Re-connect` calls into Phase-1 flow.
- **Verify:** all 11 indicators colour from a live `System_Ready_Status_t`; RTC clock visibly ticks (driven by Computer Date-Time `QTimer` 1 s); Update RTC pushes computer time to device and re-reads it.

### Phase 4 — Current Measurement tab
**Goal:** match `screenshots/Measurement_Tab.png`.

- New `src/tabs/measurement_tab.{h,cpp,ui}`.
- `QTableWidget` 3 columns × 7 rows (Sensor / Value / Unit), header non-editable, alternating row tint, no selection. Rows pre-seeded with sensor names + units (Temperature/Celsius, Humidity/%Rh, Pressure/kPa, Light/uMol/m2s, Rain Guage/mm/Hr, Dew Point/Celsius, BUS Value/-).
- `QTimer` 1 s `requestWeather()` while visible.
- Convert `Weather_Data_Packed_t` Q9.7 fixed-point fields using `lib/utils/fixedptc.h` semantics — host-side helper `qint16_to_float(value) = value / 128.0`. `light_par` is `uint16_t` linear; `bus_value` is also Q9.7 displayed integer (per screenshot showing `0`).
- **Verify:** values update once per second; reading a captured sample frame produces the expected decimal values; Q9.7 conversion unit-tested.

### Phase 5 — General Settings tab
**Goal:** match `screenshots/General_Settings_Tab.png`; uses shared `m_metaCache`.

- New `src/tabs/general_settings_tab.{h,cpp,ui}`.
- Widgets: `QSpinBox` Region ID (0..65535), `QSpinBox` Station ID (0..65535), `QComboBox` Sampling Interval with items `[1,5,10,15,30,60]` minutes (display "N minutes", `userData = uint8_t`), `QLineEdit` Server DNS (max 63 chars, `setMaxLength(63)`), `QLineEdit` Sensor Upload Path (max 63), `QLineEdit` Firmware Path (max 63). Bottom right: `Discard` and `Apply` buttons.
- On tab show OR explicit Discard: call `requestMeta()`; populate widgets from received `Meta_Data_t` (these 6 fields only — leave calibration alone).
- `Apply`: copy widgets into a working `Meta_Data_t` cloned from `m_metaCache` (preserving calibration set by Phase 6), call `setMeta()`. Show non-modal toast on ack/nak.
- Dirty tracking: change-signal on each widget toggles Apply enabled state; closing/leaving tab while dirty → `QMessageBox::question` "Discard unsaved changes?".
- **Verify:** load → edit fields → Apply → reconnect → values persist; Discard restores from device.

### Phase 6 — Sensor Settings tab
**Goal:** match `screenshots/Sensor_Settings_Tab.png`; shares `m_metaCache` with Phase 5.

- New `src/tabs/sensor_settings_tab.{h,cpp,ui}`.
- Widgets (all QDoubleSpinBox 2 decimals except Light): Temp Adjust (-50.00..50.00 °C), Humidity Adjust (-50.00..50.00 %Rh), Pressure Adjust (-20.00..20.00 kPa), **Light Adjust QSpinBox** (-32768..32767, integer — protocol type is `int16_t`), Rain-Gauge Adjust (-20.00..20.00 mm/Hr). Bottom right: `Discard` / `Apply`.
- Same load-from-`requestMeta()`, save-via-`setMeta()` pattern as Phase 5; `Apply` clones `m_metaCache` and overwrites only the 5 calibration fields so it doesn't stomp Phase-5 settings.
- Same dirty tracking + leave-prompt as Phase 5.
- **Verify:** edit calibration on this tab while General Settings tab is also dirty → each Apply preserves the other tab's edits (manual test); round-trip via reconnect persists values.

### Phase 7 — About tab
**Goal:** match `screenshots/About_Tab.png`. Trivial.

- New `src/tabs/about_tab.{h,cpp,ui}`.
- Centered: icon (left) + "Weather Station Control Center" header, "Copyright (c) 2026 by RobinLab", "This program should be used with the weather-station device connected through USB", and version line `"Version " + QString(ROBIN_WSC_VERSION_STRING)` from `app_info.h`.
- **Verify:** version string matches CMake-injected value.

### Phase 8 — Debug Log dialog
**Goal:** surface the existing `LogBuffer` from the Help menu.

- New `src/dialogs/log_viewer_dialog.{h,cpp,ui}`: non-modal, `QPlainTextEdit` (read-only, monospace), `Clear` button, `Copy All` button, "Auto-scroll" checkbox.
- On open: prime with `LogBuffer::snapshot()`; subscribe to `entryAdded(Entry)` via `Qt::QueuedConnection` for live tail. Disconnect on close.
- Wire Help → Debug Log… (Ctrl+L) action from Phase 0.
- Add log calls in `DeviceController` (connect / disconnect / opcode sent / opcode received / timeout / nak code) and in connection lifecycle (Phase 1).
- **Verify:** Ctrl+L opens dialog; performing any action causes a new line; Copy All puts text on clipboard.

### Phase 9 — Build, package, polish
**Goal:** clean delivery.

- Update root `CMakeLists.txt` to add new sources (5 tab classes, 2 dialog classes) and the qrc icon.
- Extend `tests/CMakeLists.txt` for `device_controller_test.cpp` and any small `q97_conversion_test.cpp`.
- Run `cmake --build build/release` then `cmake --install build/release --prefix dist/RobinWSC-1.0.0-win64`; sanity-check the relocatable folder runs on a clean profile.
- Confirm `-Wall -Wextra -Wpedantic -Wshadow -Wconversion -Wsign-conversion -Wnon-virtual-dtor -Wold-style-cast -Wcast-align -Wnull-dereference -Wdouble-promotion` clean (the project already enforces this).

---

## Files added / modified summary

| Path | Action |
|---|---|
| `src/mainwindow.{h,cpp,ui}` | Heavy rewrite (Phase 0) |
| `src/main.cpp` | Set window icon (Phase 0) |
| `src/device_controller.{h,cpp}` | Extend API + meta cache + timeout (Phase 2) |
| `src/tabs/status_tab.{h,cpp,ui}` | NEW (Phase 3) |
| `src/tabs/measurement_tab.{h,cpp,ui}` | NEW (Phase 4) |
| `src/tabs/general_settings_tab.{h,cpp,ui}` | NEW (Phase 5) |
| `src/tabs/sensor_settings_tab.{h,cpp,ui}` | NEW (Phase 6) |
| `src/tabs/about_tab.{h,cpp,ui}` | NEW (Phase 7) |
| `src/dialogs/device_picker_dialog.{h,cpp,ui}` | NEW (Phase 1) |
| `src/dialogs/log_viewer_dialog.{h,cpp,ui}` | NEW (Phase 8) |
| `resources/robin_wsc.qrc` | Add icon entry (Phase 0) |
| `resources/icons/robin_wsc.png` | NEW from `screenshots/Icon.png` (Phase 0) |
| `tests/device_controller_test.cpp` | NEW (Phase 2) |
| `tests/q97_conversion_test.cpp` | NEW (Phase 4) |
| `CMakeLists.txt` (root) | Add new sources (Phase 9) |
| `tests/CMakeLists.txt` | Register new tests (Phases 2, 4) |

Untouched: `frame_parser.*`, `device_io.*`, `log_buffer.*`, `app_info.h`, `tests/frame_parser_test.cpp`.

---

## End-to-end verification

1. `wsl bash //scripts/run_native_tests.sh` for firmware-side mocked tests still green (we didn't touch firmware).
2. From `host/`: `cmake --build build/release` clean.
3. `ctest --test-dir build/release` — frame parser, device controller, Q9.7 conversion all pass.
4. Plug a real Robin Weather Station via USB, launch `robin_wsc.exe`:
   - Status tab shows green for present subsystems, RTC ticks, Update RTC writes computer time, Clear Database confirms then succeeds.
   - Current Measurement values update every 1 s with sane numbers.
   - General Settings: load values, change Region ID, Apply, power-cycle device, reload — value persists.
   - Sensor Settings: change Temp Adjust, Apply; verify Current Measurement Temperature shifts by that offset.
   - About tab shows version string matching CMake.
   - Help → Debug Log shows live trace of every request/response.
5. Unplug device while running → banner appears, tabs gracefully stop polling, no crash.
6. Plug a second device → next Re-connect opens picker dialog.

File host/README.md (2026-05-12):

# Robin Weather Station Configurator — Host

Cross-platform GUI utility for configuring and monitoring the Robin Weather
Station over USB CDC-ACM.

## Quick start (Windows 11, MinGW-w64 from Qt 6.8 LTS)

```cmd
cd C:\Users\akrap\weather-station\host

REM Configure a Release build
cmake -S . -B build/release -G Ninja -DCMAKE_BUILD_TYPE=Release

REM Build
cmake --build build/release

REM Run from the build tree (Qt DLLs picked up via PATH set in Qt Creator)
build\release\robin_wsc.exe

REM Or build a portable distribution folder
cmake --install build/release --prefix dist/RobinWSC-1.0.0-win64
```

The contents of `dist/RobinWSC-1.0.0-win64/` form the portable distribution —
zip the folder and ship the zip. Users extract and double-click `robin_wsc.exe`.
No installer, no admin rights, no registry entries.

## Project structure

See `CLAUDE.md` for the full project specification.

```
host/
├── CMakeLists.txt              Build configuration
├── CLAUDE.md                   Project spec (read this first)
├── README.md                   This file
├── src/                        Application sources
├── resources/                  Icons, .qrc, Windows .rc, udev rules
├── packaging/                  README.txt + LGPLv3 license for distribution
├── tests/                      Unit tests (off by default)
└── build/                      CMake out-of-source build dirs (gitignored)
```

The `../shared/` directory at the repo root holds protocol headers shared
with the firmware project.

## Toolchain

- Qt 6.8 LTS (Open Source / LGPLv3) with the Serial Port module
- MinGW-w64 GCC 13.x (64-bit, bundled with Qt)
- CMake 3.21+, Ninja
- Qt Creator (recommended IDE)

Install Qt via the Qt Online Installer from <https://www.qt.io/download-qt-installer>
and tick:
- Qt 6.8.x → MinGW 13.1.0 64-bit
- Qt 6.8.x → Additional Libraries → Qt Serial Port
- Developer and Designer Tools → Qt Creator, CMake, Ninja, MinGW 13.1.0 64-bit

## License

This application is the property of RobinLab-KU.

It uses the Qt framework under the terms of LGPLv3. See
`packaging/COPYING.LGPLv3.txt` for the full Qt license text.

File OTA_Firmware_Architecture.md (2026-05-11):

# OTA Firmware Update Architecture

STM32L476RG + CY15B116QN FRAM + A7670E LTE modem · FreeRTOS · PlatformIO + STM32CubeMX.
As-built reference. Phase status in `IMPLEMENTATION_STATUS.md`. Server side in `Server_Architecture.md`.

---

## 1. System Overview

### 1.1 Hardware

| Component | Part | Interface | Notes |
|---|---|---|---|
| MCU | STM32L476RG | — | Cortex-M4F, 1 MB Flash, 128 KB SRAM (SRAM1 96 KB + SRAM2 32 KB) |
| FRAM | CY15B116QN  | SPI1 | 2 MB, byte-addressable, unlimited endurance |
| Modem | A7670E | USART3 | TLS 1.2, `AT+HTTP*` (no `AT+CCH*` / no `AT+CHTTPS*` on this variant) |

### 1.2 Size budget

| Region | Limit | Enforcement |
|---|---|---|
| App code (`.text` + `.rodata`) | ≤ 480 KB (Flash partition) | Linker `ASSERT`, `scripts/monitor_ram.sh` |
| App data (`.data` + `.bss`) | ≤ 96 KB (SRAM1) | Linker `ASSERT`, `scripts/monitor_ram.sh` |
| SRAM2 (32 KB) | OTA state flags only | Not counted in 96 KB |
| Bootloader Flash | 32 KB | `bootloader/ldscript_boot.ld` |
| OTA static download buffer | 740 B | `s_chunk_read_buf[516]` + `s_cmd_buf[224]` |

### 1.3 End-to-end OTA flow

```
RTC alarm (noon / midnight)
  → ssluploadtask: POST batched FRAM records via AT+HTTP* (HTTPS POST)
  → xTaskNotify → OtaManagerTask
       │
       ▼
   GET <UPDATE_PATH>/?id=rrrsss
       → "V.#####:L.$$$$$$$:H.<sha256>:W.<sec>"
       │
       │  V > FW_VERSION  AND  W == 0  AND  L ≤ FLASH_APP_SIZE_MAX (480 KB)
       ▼
   GET <UPDATE_PATH>/get_firmware?offset=&length=&id=rrrsss  (loop, 512 B chunks)
       → write FRAM staging, update download bitmap, accumulate SHA-256
       │
       ▼ SHA-256 match
   ocb_write({ota_pending=1, image_size, image_sha256, fw_version})  (dual-copy)
       │
       ▼ HAL_NVIC_SystemReset
   Bootloader: validate OCB, size guard, SHA-256, erase+program pages 16–255, verify, jump 0x08008000
       │
       ▼ new app boots
   ota_confirm_success() within 60 s, else IWDG → bootloader retains old app
```

---

## 2. Internal Flash Layout

```
0x08000000  Bootloader  (32 KB, pages 0–15, Bank 1)   RDP1 + write-protected
0x08008000  Application (480 KB, pages 16–255, Bank 1) ldscript_app.ld origin
0x08080000  Bank 2      (512 KB — reserved for future dual-bank)
```

Linker `MEMORY` (application):

```
FLASH (rx)  : ORIGIN = 0x08008000, LENGTH = 480K
RAM   (xrw) : ORIGIN = 0x20000000, LENGTH = 96K   /* SRAM1 — hard limit */
RAM2  (xrw) : ORIGIN = 0x10000000, LENGTH = 32K   /* SRAM2 — OTA flags only */
```

---

## 3. FRAM Layout

Single source of truth: `shared/fram_addresses.h`. Do not hardcode addresses.

### 3.1 DB Region (first 1 MB, 0x000000 – 0x0FFFFF)

| Sub-region | Start | Size | Description |
|---|---|---|---|
| DB ring buffer | 0x000000 | ~1,016 KB | Sensor records, ring buffer (`nv_database.c`) |
| Config sector  | 0x0FE000 | 4 KB | System config + OTA Control Block (dual-copy) |
| Reserved | 0x0FF000 | 4 KB | Future use |

### 3.2 Config sector @ 0x0FE000 (4 KB)

| Offset | Size | Field |
|---|---|---|
| +0x0000 | 128 B | System config (baud rates, server URL, `Meta_Data_t`) |
| +0x0080 | 64 B  | OTA Control Block — primary |
| +0x00C0 | 64 B  | OTA Control Block — mirror |
| +0x0100 | — | Reserved |

### 3.3 OTA Staging Region (second 1 MB, 0x100000 – 0x1FFFFF)

| Sub-region | Start | Size | Description |
|---|---|---|---|
| Staging header | 0x100000 | 256 B | Mirrors OCB + in-progress URL/size |
| Image data | 0x100100 | ≤ 480 KB | Raw `.bin`. Hard cap = app Flash partition; bootloader cannot program past page 255. |
| Download bitmap  | 0x17F000 | 1 KB | 1 bit per 512-byte chunk; set = received |

Bitmap capacity: 8,192 chunks × 512 B = 4 MB (overcommitted vs 480 KB cap). On reconnect, scan bitmap and request only missing chunks.

### 3.4 OtaControlBlock_t

```c
/* shared/ota_control_block.h — compiled into both app and bootloader */
typedef struct __attribute__((packed)) {
    uint32_t magic;              /* 0x0AC0FFEE */
    uint8_t  ota_pending;        /* 0x01 = image ready, 0x00 = idle */
    uint8_t  ota_tried;          /* incremented each boot attempt; max 3 */
    uint8_t  ota_confirmed;      /* 0x01 = new app called ota_confirm_success() */
    uint8_t  pad0;
    uint32_t image_size;
    uint8_t  image_sha256[32];   /* sole whole-image integrity check */
    uint32_t fw_version;
    uint8_t  reserved[8];
    uint32_t download_timestamp; /* Y2K epoch */
    uint32_t block_crc32;        /* CRC-32/MPEG-2 over bytes [0..59] */
} OtaControlBlock_t;             /* 64 B */
```

Dual-copy procedure: write primary → verify CRC → write mirror → verify CRC. On read, accept the copy whose `block_crc32` validates; if neither, treat as no pending OTA.

---

## 4. OTA State Machine

State persisted in `OtaControlBlock_t`. Survives power loss.

```
IDLE
  │ RTC alarm (after upload, via xTaskNotify)
  ▼
POLLING_VERSION  ── server V ≤ FW_VERSION ──▶ IDLE
  │                ── L > FLASH_APP_SIZE_MAX ─▶ IDLE  (no retry)
  │                ── W > 0                  ─▶ IDLE  (retry next cycle)
  ▼
DOWNLOADING  ◀── resume on power loss (scan download bitmap)
  │ bitmap full
  ▼
DOWNLOAD_COMPLETE
  │ per-chunk CRC ✓  AND  SHA-256 ✓
  ▼
VERIFIED   → ocb_write(ota_pending=1) → graceful shutdown → flush DB
  │
  ▼
REBOOT_PENDING → HAL_NVIC_SystemReset()
  │ bootloader programs + jumps
  ▼
CONFIRMING (new app)
  │ ota_confirm_success() within 60 s   else IWDG → bootloader rollback
  ▼
IDLE  (ota_confirmed=1, ota_pending=0)

Integrity FAIL          → staging invalidated, old FW retained
ota_tried >= 3          → bootloader boots old Flash unchanged
HTTP 429 (out of slot)  → treated as network error; retry next cycle
```

---

## 5. Bootloader

Bare-metal (no FreeRTOS). SPI1 (polling), IWDG, Flash HAL only. Linked at `0x08000000` / 32 KB. IWDG set to ≈ 4 s, refreshed each page.

### 5.1 Boot decision

1. Read OCB primary + mirror; accept the copy with valid CRC.
2. If `ota_pending == 0x01` and `ota_tried < 3`:
   - Increment `ota_tried`; rewrite both copies.
   - Reject `image_size == 0` or `image_size > FLASH_APP_SIZE_MAX` (480 KB) → jump to old app.
   - Validate SHA-256 over `image_size` bytes of FRAM staging against `image_sha256`. **No whole-image CRC**; SHA-256 is sole integrity check.
   - Program pages 16–255 (erase → 64-bit write → read-back `memcmp`).
   - All pages verified: clear `ota_pending`, set `ota_confirmed = 0`, jump.
   - Any failure: clear `ota_pending`, set error, jump to old app.
3. Else: jump directly to `0x08008000`.

Stack-pointer sanity check before jump: SP must be in `[0x20000000, 0x20018000)`.

### 5.2 Cache management (critical)

STM32L476 ART Accelerator has read-only Flash I-cache + D-cache (`FLASH_ACR` `ICEN`/`DCEN`). Both enabled by default. Two failure modes:

| Failure | Cause | Fix |
|---|---|-----|
| Stale `memcmp` after page program | D-cache holds pre-erase data | Reset D-cache before each `memcmp` |
| Old instructions execute after jump | I-cache holds previous app code | Reset I-cache after all pages programmed |

Required HAL sequence per page (after `HAL_FLASH_Lock`, before `memcmp`):

```c
__HAL_FLASH_DATA_CACHE_DISABLE();
__HAL_FLASH_DATA_CACHE_RESET();
__HAL_FLASH_DATA_CACHE_ENABLE();
```

After all pages programmed (before return):

```c
__HAL_FLASH_INSTRUCTION_CACHE_DISABLE();
__HAL_FLASH_INSTRUCTION_CACHE_RESET();
__HAL_FLASH_INSTRUCTION_CACHE_ENABLE();
```

`HAL_FLASHEx_Erase` does **not** invalidate D-cache on all HAL versions — always do it explicitly.

### 5.3 Security

- RDP Level 1 + WRP on pages 0–15 (after production programming).
- Ed25519 image signing: deferred to a future phase. Server-side signing is wired (S10-4 — `v{n}.sig` produced); bootloader verification not yet implemented.

---

## 6. OTA Protocol

### 6.1 Base URL

`UPDATE_PATH` is stored in `Meta_Data_t.update_path` (64 B, Config Sector). Set via CDC `set config`. Server mounts all device traffic under the same base path (Q-S1 Option B): `update_path = "/api/v1/weather"`. Concrete URLs:

- `POST <server>/api/v1/weather/upload` — ingest
- `GET  <server>/api/v1/weather/?id=rrrsss` — OTA version + wait token
- `GET  <server>/api/v1/weather/get_firmware?offset=X&length=512&id=rrrsss` — OTA chunk

### 6.2 Device identity

`?id=` is a 6-char decimal `{region:03d}{station:03d}` built from `Meta_Data_t.region_id`/`.station_id`. Both fields constrained to 0–999; firmware applies `% 1000` before formatting `%03u%03u` (Q-S7).

### 6.3 Endpoint 1 — Version + size

```
GET <UPDATE_PATH>/?id=rrrsss
```

Response: HTML body containing a plain-text token (locate via regex, not byte 0):

```
V.\d+:L.\d+:H.[0-9a-f]{64}(?::W\.\d+)?
```

- `V` — uint32 server firmware version
- `L` — image size, bytes
- `H` — SHA-256, 64 lowercase hex chars
- `W` — optional rollout wait (seconds). Missing or `W.0` = download permitted. `W>0` = skip this cycle, retry next poll.

Parser action:
- No match → "no update", silent skip, no retry.
- `V ≤ FW_VERSION` → no update.
- `L > FLASH_APP_SIZE_MAX (480 KB)` → reject, return to IDLE (no retry).
- `W > 0` → return to IDLE.
- Retries: up to 3 on modem/network errors; 0 on parseable non-matching body.

### 6.4 Endpoint 2 — Chunk download

```
GET <UPDATE_PATH>/get_firmware?offset=N&length=512&id=rrrsss
```

Response body = `<length>` bytes of image + 4-byte little-endian CRC-32/MPEG-2 trailer. Total = `length + 4`. Device reads via `AT+HTTPREAD=0,516`.

| Server response | Device action |
|---|---|
| `200` + chunk + CRC | Validate CRC, write to FRAM staging, set bitmap bit, update SHA-256 |
| `429 Too Many Requests` | Server re-evaluated rollout slot; treat as network error; back off, retry |
| Other / CRC mismatch | Retry up to 3× per chunk |

### 6.5 Download loop (current `ota_manager_task.c`)

```c
/* Phase 1 — fetch metadata */
snprintf(version_url, sizeof version_url, "%s/?id=%03u%03u",
         update_path, region_id % 1000, station_id % 1000);
if (parse_response(buf, &v, &l, sha_expected, &wait_sec) != OK) return IDLE;
if (v <= FW_VERSION) return IDLE;
if (l > FLASH_APP_SIZE_MAX) return IDLE;
if (wait_sec > 0) return IDLE;

/* Phase 2 — chunked download with resume */
uint32_t off = oiw_resume_info(&next_chunk) ? next_chunk * CHUNK_SIZE : 0;
sha256_init(&ctx);  /* re-hash already-received chunks from FRAM if resuming */
while (off < l) {
    uint32_t req = MIN(CHUNK_SIZE, l - off);
    snprintf(url, sizeof url, "%s/get_firmware?offset=%lu&length=%lu&id=%03u%03u",
             update_path, off, req, region_id % 1000, station_id % 1000);
    if (ssl_downloader_get_chunk(url, buf, CHUNK_SIZE, &got) != OK) {
        if (++retries >= 3) abort;
        continue;
    }
    oiw_write_chunk(off / CHUNK_SIZE, buf, got);
    sha256_update(&ctx, buf, got);
    off += got;
    HAL_IWDG_Refresh(&hiwdg);
}
sha256_final(&ctx, digest);
if (memcmp(digest, sha_expected, 32) != 0) { invalidate(); return IDLE; }
ocb_write(...);  /* dual-copy; ota_pending = 1 */
```

---

## 7. A7670E Modem Service

All TLS crypto runs on the modem. STM32 pays zero crypto cost.

**Service:** A7670E exposes only `AT+HTTP*` (no `AT+CCH*`, no `AT+CHTTPS*`). One HTTP session at a time. Both upload (POST) and OTA download (GET) use the same flow.

### 7.1 Upload POST (`a7670_https_uploader.c`)

```
AT+HTTPINIT
AT+HTTPPARA="URL",...
AT+HTTPPARA="CONTENT","application/octet-stream"
AT+HTTPPARA="SSLCFG",0
AT+HTTPDATA=<size>,30
  ← DOWNLOAD       (prompt — not '>')
  → <binary body>
  ← OK
AT+HTTPACTION=1
  ← +HTTPACTION: 1,<status>,<datalen>   (URC)
AT+HTTPTERM
```

### 7.2 Download GET (`a7670_ssl_downloader.c`)

```
AT+HTTPINIT
AT+HTTPPARA="SSLCFG",0
AT+HTTPPARA="URL",".../get_firmware?offset=X&length=512&id=rrrsss"
AT+HTTPACTION=0
  ← +HTTPACTION: 0,<status>,<datalen>   (URC)
AT+HTTPREAD=0,516
  ← <chunk bytes + 4-byte CRC>
AT+HTTPTERM
```

### 7.3 Modem init (`Modem_Module_Init` in `a7670.c`)

1. AT alive ping
2. `AT+CTZU=1` — NITZ time-zone update
3. `AT+CNTP="server",28` then `at_channel_send_cntp(12000)` — suppresses immediate OK; AT_OK only on `+CNTP: 0` URC, AT_ERROR on non-zero err (12 s timeout)
4. `AT+CCERTDOWN` × 3 — upload CA cert, fleet client cert, fleet private key (see R-12)
5. `AT+CSSLCFG="sslversion",0,3` — TLS 1.2 on SSL context 0
6. `AT+CSSLCFG="authmode",0,2` — mutual TLS on SSL context 0
7. `AT+CSSLCFG="cacert/clientcert/clientkey/sni",0,…` — bind certs
8. `at_channel_wait_ready()` — network registration

**Cert format (R-12).** `AT+CCERTDOWN` expects **DER binary** on this variant — no `-----BEGIN` headers. Convert from PEM with `openssl x509 -outform DER` (certs) and `openssl rsa -outform DER` (keys), then embed as C byte arrays. `*_der.c` filenames are accurate; verify the array contents are DER before each fleet deployment.

---

## 8. Integrity

| Layer | Algorithm | Implementation | Purpose |
|---|---|---|---|
| Per-chunk | CRC-32/MPEG-2 (poly `0x04C11DB7`, init `0xFFFFFFFF`, no reflection, no XOR) | `shared/crc32.c` (1 KB lookup table, Flash) | Catches UART bit-flips; mismatch → `SSL_DL_ERR_CRC` → retry chunk |
| Whole-image | SHA-256 (FIPS 180-4) | `shared/sha256.c` (standalone, no mbedTLS) | Accumulated during download. App verifies vs `H.` from metadata before OCB commit. Bootloader re-verifies before Flash program. |

HW CRC unit on the STM32L476 is **not used** — `modbus_init()` configures it for CRC-16/Modbus and it cannot be shared. CRC-32/MPEG-2 is software-only.

There is no whole-image CRC. SHA-256 is the sole whole-image check.

RAM cost: `s_chunk_read_buf[516]` static (downloader) + 108 B SHA context on stack + 32 B digest = under 1 KB total.

---

## 9. FreeRTOS Tasks

All tasks created in `Src/freertos.c → MX_FREERTOS_Init()`. Every task must call the heartbeat API within 500 ms.

| Task | File | Period / wake | Priority | Role |
|---|---|---|---|---|
| `UsbLoopTask` | `freertos.c` | event | High | TinyUSB device loop (`tud_task`) |
| `cdc_task` | `cdctask.c` | event | High | USB CDC binary protocol |
| `maintask` | `maintask.c` | 1 s | Normal | Sensor read → FRAM + SD |
| `uitask` | `uitask.c` | 20 ms | Normal | LCD refresh, LEDs, button debounce |
| `ucctask` | `ucctask.c` | 100 ms | Normal | LCD menu / user interaction |
| `ssluploadtask` | `ssluploadtask.c` | noon + midnight | Normal | Batched HTTPS upload; `xTaskNotify` to OtaManagerTask |
| `OtaManagerTask`  | `ota_manager_task.c` | after upload | Normal | OTA state machine |
| `WatchdogTask` | `watchdog_task.c` | 500 ms | High | Per-task heartbeat + IWDG refresh |

**Mutex order (deadlock guard):** `g_fram_spi_mutex` always taken before `g_ota_state_mutex`. Never reverse.

---

## 10. Repository Structure

```
project_root/
├── platformio.ini              ; two envs: application + bootloader
├── Src/                        ; app source (CubeMX + USER CODE guards)
│   ├── freertos.c              ; task creation
│   ├── maintask.c              ; sensor 1 s loop → FRAM + SD
│   ├── ssluploadtask.c         ; HTTPS upload via AT+HTTP*
│   ├── ota_manager_task.{c,h}  ; OTA state machine
│   ├── ota_image_writer.{c,h}  ; chunked FRAM write + bitmap
│   ├── watchdog_task.{c,h}     ; heartbeat + IWDG
│   ├── ui/cdc/uart tasks
│   └── *.c (CubeMX peripherals — gpio/i2c/spi/usart/rtc/sdmmc/usb_otg/dma)
├── Inc/                        ; app headers
├── lib/
│   ├── sensors/                ; bmp390, sht45 (I2C), modbus, rain_light (RS-485)
│   ├── A7670/                  ; a7670.c, a7670_at_channel.c, a7670_https_uploader.c, a7670_ssl_downloader.c, a7670_ssl_cert_manager.c
│   ├── SPI_FRAM/               ; cy15b116qn.c (raw SPI), nv_database.c (ring DB)
│   ├── user_interface/         ; mcp23017.c, ui.c
│   ├── usart_subsystem/        ; uart_subsystem.c (shared interrupt-driven UART)
│   ├── time/                   ; datetime.c, y2k_time.c
│   ├── tinyusb/                ; vendored TinyUSB
│   └── utils/                  ; weather_data.h, fixedptc.h
├── shared/                     ; compiled into BOTH app and bootloader
│   ├── fram_addresses.h        ; single source for all FRAM addresses + FLASH_APP_SIZE_MAX
│   ├── ota_control_block.{c,h} ; dual-copy OCB read/write/validate
│   ├── crc32.{c,h}             ; CRC-32/MPEG-2
│   └── sha256.{c,h}            ; FIPS 180-4
└── bootloader/                 ; separate PIO env, bare-metal
    ├── ldscript_boot.ld        ; 0x08000000 / 32 KB
    ├── Inc/                    ; main.h, stm32l4xx_hal_conf.h (SPI1+IWDG+Flash only)
    └── src/                    ; main.c, boot_flash.{c,h}, boot_fram.{c,h}
```

---

## 11. Design Decisions

| # | Decision |
|---|---|
| Q-1 | Copy-in-place: bootloader programs FRAM staging → Bank 1 pages 16–255. Dual-bank atomic swap deferred. |
| Q-2 | Per-chunk CRC-32/MPEG-2 + whole-image SHA-256. Ed25519 signing deferred (server S10-4 emits `v{n}.sig` already). |
| Q-3 | Background download: `OtaManagerTask` yields `g_fram_spi_mutex` between chunks; sensor + upload continue uninterrupted. |
| Q-4 | 60 s confirm window: new app calls `ota_confirm_success()`; otherwise IWDG → bootloader rollback. |
| Q-5 | Private-CA mTLS (Server_Architecture.md §2.1). Cert pinning deferred. |
| Q-6 | Plain-text protocol `V.#####:L.$$$$$$$:H.<sha256>:W.<seconds>`. No JSON parser. |
| Q-7 | Standalone `shared/sha256.c`. mbedTLS not present on STM32; TLS lives on modem. |
| Q-8 | Twice daily: `OtaManagerTask` notified by `ssluploadtask` after each upload session. |

---

## 12. Risk Register

Only open risks listed. All resolved risks (R-1..R-11, R-13..R-15) removed.

| ID | Risk | Probability | Impact | Mitigation |
|----|---|---|---|---|
| R-12 | Cert arrays compiled as DER but `*_der.c` may contain PEM bytes — silent FS corruption | Medium | Critical | Verify each `*_der.c` array has no `-----BEGIN` header before next fleet build; regenerate via `openssl x509/rsa -outform DER` if needed |

---

## 13. References

- STM32L476xx Reference Manual RM0351 — Sections 3.3 (Flash), 3.4 (Flash protection), 14 (CRC unit).
- STM32L476RG Datasheet DS10199.
- CY15B116QN Datasheet (Doc 001-99272, Infineon).
- A7670 Series AT Command Manual V1.09 — Chapter 16 (HTTP). Local: `https_manual.md`.
- NTP usage: local `ntp_manual.md`.
- FreeRTOS Reference Manual — Task Notifications, Mutexes with Priority Inheritance.
- ARM Cortex-M4 Devices Generic User Guide.
- PlatformIO — STM32Cube framework.

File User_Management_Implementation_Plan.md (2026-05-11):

# User Management Implementation Plan

> All UM phases complete (2026-05-08). 75/75 TUM tests pass on `robin-gpu.cpe.ku.ac.th`.
> Test plan: `User_Management_Test_Plan.md`. Status: `IMPLEMENTATION_STATUS.md`.

---

## Scope

All roles — **admin**, **operator**, **viewer** — have identical access to every IoT page (dashboard, campaigns, devices, sensor data). Roles differ **only** for user management:

| Actor | User management capability |
|---|---|
| **admin** | List all users; create user (any role); edit any user's username/role; change any user's password; delete other users; edit own profile |
| **operator / viewer** | View and edit own username; change own password (requires current password); cannot change own role |

**Hard rules** (enforced at every layer):

- Admin cannot delete themselves (lockout prevention).
- Admin cannot demote their own role via any form.
- Username globally unique (DB `UNIQUE` + application 409).
- Password ≥ 8 chars; bcrypt cost ≥ 12 (matches existing `auth/jwt.py`).
- CSRF token required on every form mutation (HMAC double-submit).
- All HTML pages redirect to login on missing/expired JWT cookie.

---

## Phase Summary

| Phase | Files changed | Description |
|---|---|---|
| UM1 | `app/db/queries.py` | 7 new async functions: `list_admin_users` (ORDER BY role then created_at), `get_admin_user_by_id`, `username_exists(exclude_id=None)`, `create_admin_user` (returns id or None on conflict), `update_admin_user_info` (returns id or None on conflict), `update_admin_user_password`, `delete_admin_user`. 15/15 unit tests pass. |
| UM2 | `app/routers/admin.py` | 4 new JSON endpoints + extend list: `POST /admin/users`, `PUT /admin/users/{id}`, `PUT /admin/users/{id}/password`, `DELETE /admin/users/{id}`. Self-demote / self-delete guards. Operator-on-other / role-field-on-self return 403. 9/9 verifications. |
| UM3 | `app/routers/ui.py` | 6 HTML routes: `GET /admin/users.html` (admin), `GET /admin/profile.html` (viewer+), `POST /admin/users/create-ui`, `POST /admin/users/{id}/update-info-ui`, `POST /admin/users/{id}/password-ui`, `POST /admin/users/{id}/delete-ui`. All form mutations CSRF-checked. HTMX-driven row/table swaps. 36/36 (TUM5–TUM11) tests pass. |
| UM4 | `app/templates/base.html`, `users.html`, `profile.html`, `partials/user_table.html` | Admin-only "Users" nav item; footer pill links to `/admin/profile.html`; admin's own row has no delete button; role dropdown absent for non-admin users; `confirm_password` mismatch inline error (no page reload). Verified by TUM5/6/7/11. |
| UM5 | `app/routers/ui.py`, `partials/user_form_modal.html` | Modal fragment routes: `GET /admin/users/new-modal` (create mode), `GET /admin/users/{id}/edit-modal` (edit mode). Single template with `create` boolean. Modal closes via HTMX `hx-on::after-request`. |

---

## API Contract

### `POST /admin/users` — admin only

```
Body: {username, password, role}
Validate: role ∈ {viewer,operator,admin}; password ≥ 8; username 1–64, [A-Za-z0-9_.-]
On conflict: 409 {detail: "Username already exists"}
Return: 201 {id, username, role, created_at}
```

### `PUT /admin/users/{user_id}` — viewer+ (self) or admin (any)

```
Body: {username?, role?}
Guards (in order):
  - non-admin caller targeting other user → 403
  - admin caller targeting self with role != admin → 403 "Admin cannot demote themselves"
  - non-admin caller sending role field → 403 "Cannot change own role"
On username conflict: 409   |   Not found: 404   |   Return: 200 {id, username, role}
```

### `PUT /admin/users/{user_id}/password` — viewer+ (self) or admin (any)

```
Body: {current_password?, new_password}
Guards:
  - non-admin caller targeting other user → 403
  - self (any role): current_password REQUIRED; bcrypt-verify; wrong → 422
  - admin targeting other: current_password NOT required
  - new_password < 8 → 422
Return: 204
```

### `DELETE /admin/users/{user_id}` — admin only

```
Guard: user_id == caller.sub_id → 403 "Cannot delete yourself"
Not found: 404   |   Return: 204
```

### `GET /admin/users` — extended (admin only)

Now returns `id`, `username`, `role`, `created_at` (previously usernames only).

---

## Form Routes (HTMX)

All `POST` form routes:

- Validate CSRF token (HMAC double-submit via `app/auth/csrf.py`).
- Mirror the JSON API guards above.
- Return either an HTMX partial fragment (table row, error inline) or a 303 redirect with `?created=1` / `?updated=1`.

Specific HTMX behaviors:

- **Create user** (`POST /admin/users/create-ui`): success → swap `#user-table`; conflict / validation error → inline error fragment.
- **Update info** (`POST /admin/users/{id}/update-info-ui`): admin on users page → `partials/user_table.html` swap; self on profile → redirect `profile.html?updated=1`. Error → `hx-swap-oob` error message.
- **Change password** (`POST /admin/users/{id}/password-ui`): success → 200 + `HX-Trigger: passwordChanged` header; error → inline error fragment.
- **Delete user** (`POST /admin/users/{id}/delete-ui`): success → `hx-target="closest tr" hx-swap="outerHTML"` returning empty string.

---

## Templates

```
app/templates/
├── base.html                         ; admin-only Users nav item; footer pill → profile
├── users.html                        ; admin-only; table + "New User" button → /admin/users/new-modal
├── profile.html                      ; viewer+; info form + password form (current_password shown on self)
└── partials/
    ├── user_table.html               ; row per user; no delete button on caller's own row
    └── user_form_modal.html          ; single template, mode toggled by `create` boolean
```

`base.html` snippet:

```html
{% if user and user.role == 'admin' %}
<li class="nav-item">
  <a class="nav-link {% if active == 'users' %}active{% endif %}"
     href="/admin/users.html">Users</a>
</li>
{% endif %}
```

`profile.html` admin-only role dropdown:

```html
{% if user.role == 'admin' %}
<select name="role">...</select>
{% else %}
<p>Role: {{ profile.role }}</p>
{% endif %}
```

---

## Deployment

`bash html/scripts/deploy.sh` → `journalctl -u iot-server -n 50` (verify no startup errors) → manual smoke: login as admin, create test user, edit, delete; login as operator, verify Users page blocked, profile page works.

---

## Files Changed / Added Summary

| File | Status |
|---|---|
| `html/app/db/queries.py` | Modified — 7 new functions |
| `html/app/routers/admin.py` | Modified — 4 new API endpoints + extended list |
| `html/app/routers/ui.py` | Modified — 6 new HTML routes + 2 modal routes |
| `html/app/templates/base.html` | Modified — Users nav + profile pill |
| `html/app/templates/users.html` | New |
| `html/app/templates/profile.html` | New |
| `html/app/templates/partials/user_table.html` | New |
| `html/app/templates/partials/user_form_modal.html` | New |

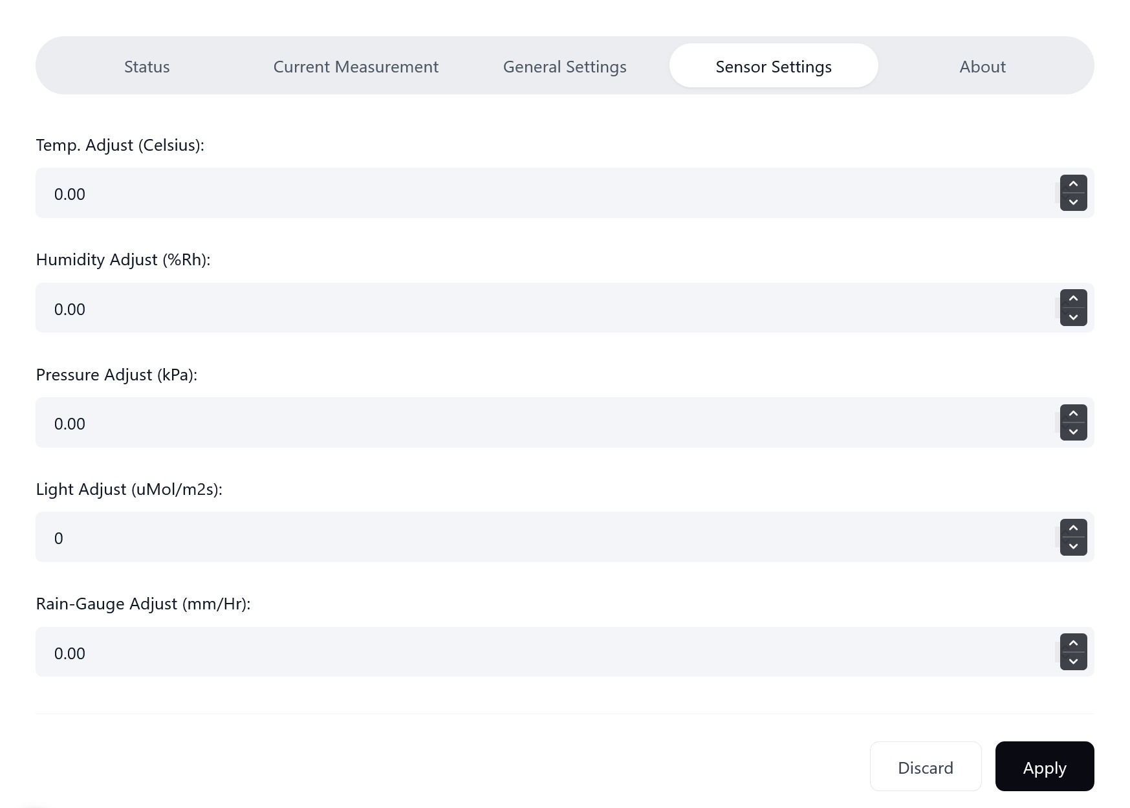
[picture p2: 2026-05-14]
host/screenshots/Sensor_Settings_Tab.png

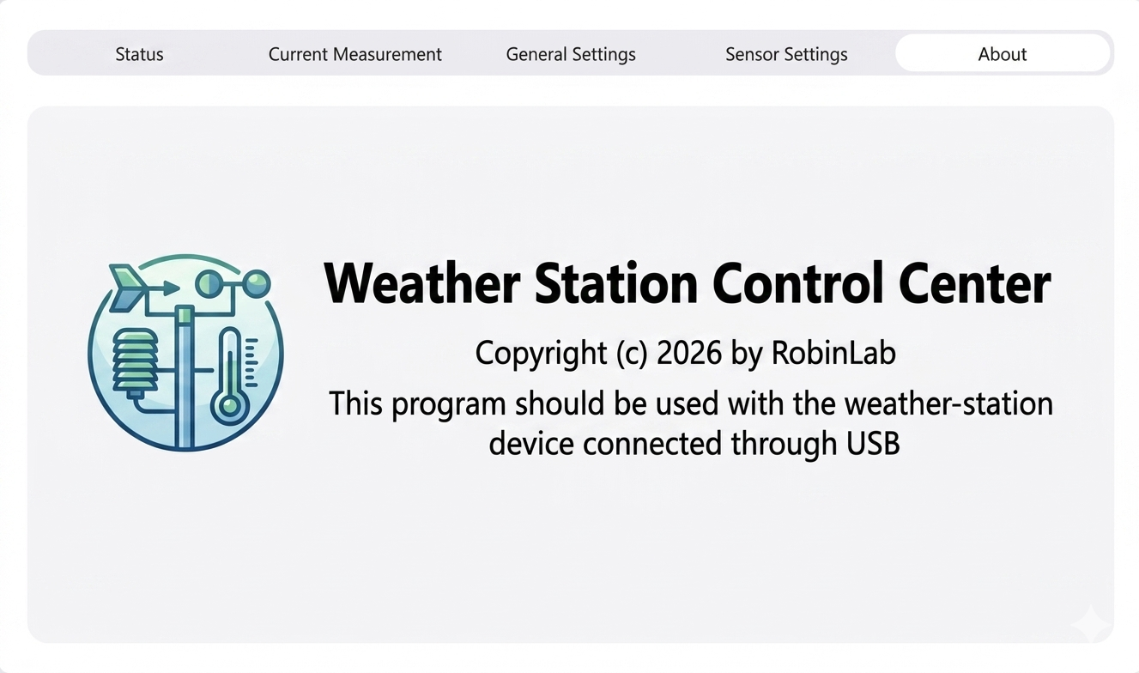
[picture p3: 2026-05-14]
host/screenshots/About_Tab.png

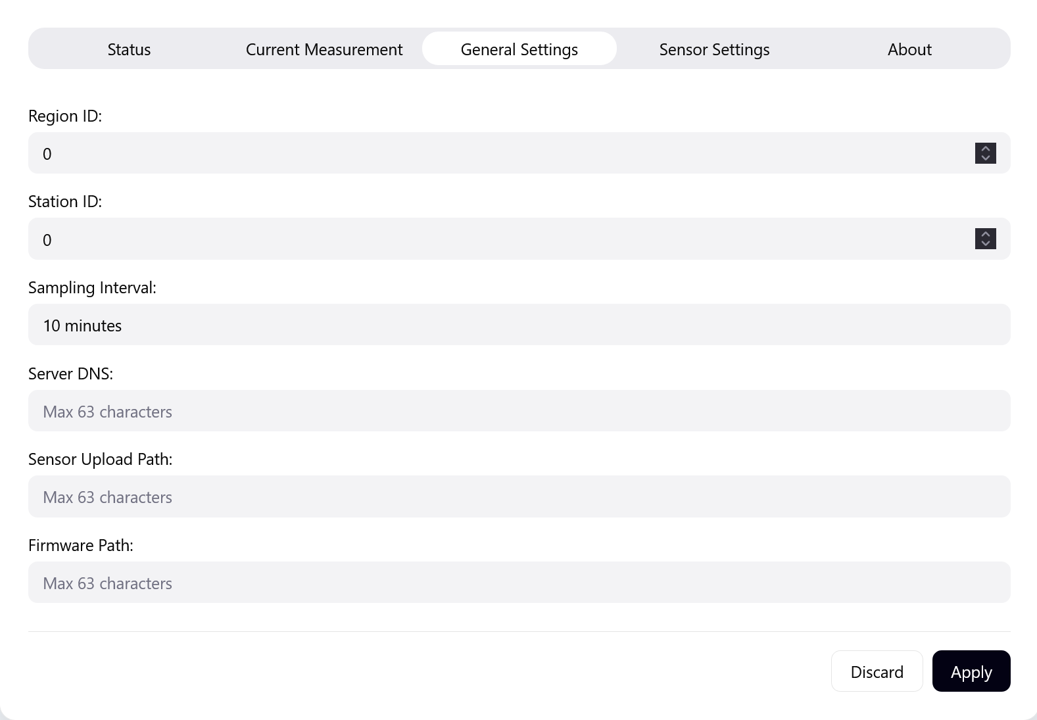
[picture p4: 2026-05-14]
host/screenshots/General_Settings_Tab.png

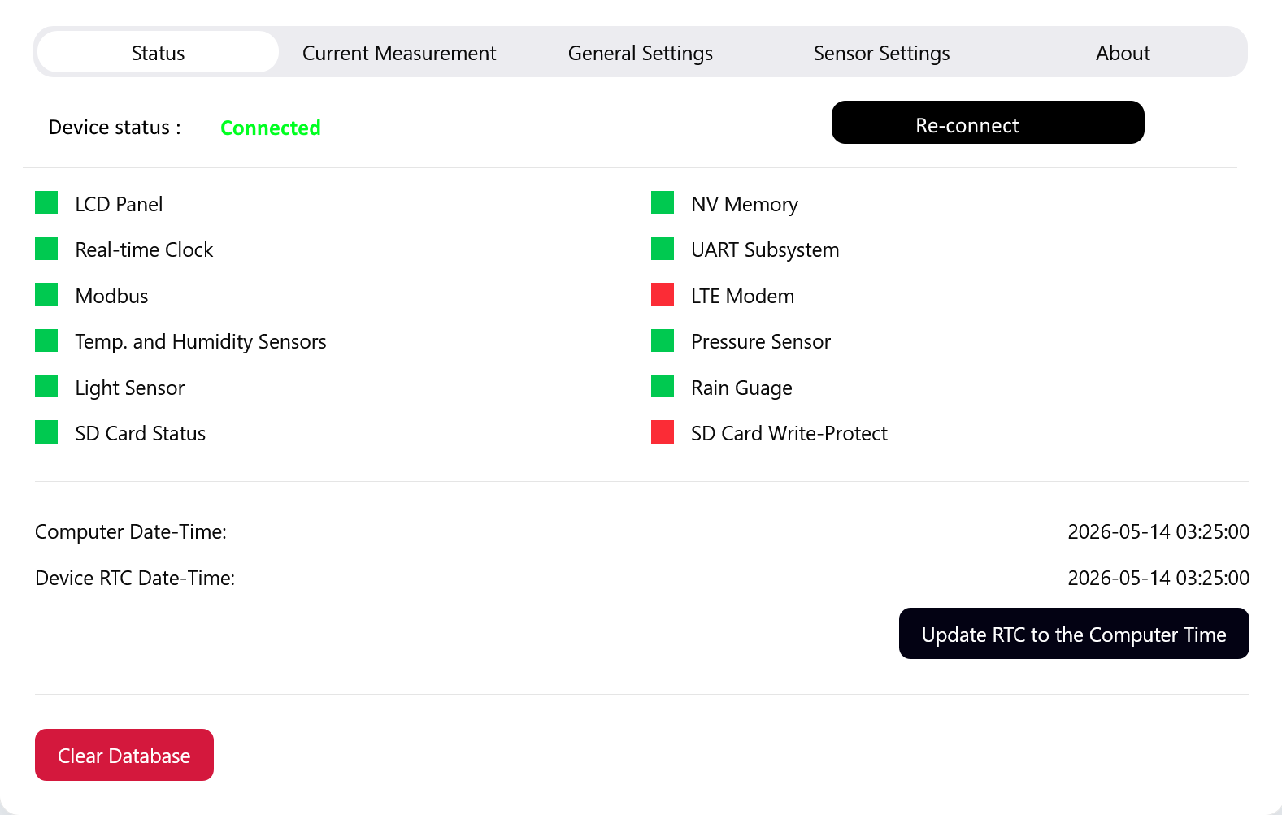
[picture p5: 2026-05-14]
host/screenshots/Status_Tab.png

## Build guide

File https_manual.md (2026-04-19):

# 16 AT Commands for HTTP(S)

> A76XX Series — AT Command Manual V1.09

---

## 16.1 Overview of AT Commands for HTTP(S)

| Command | Description |
|---|---|
| AT+HTTPINIT | Start HTTP service |
| AT+HTTPTERM | Stop HTTP Service |
| AT+HTTPPARA | Set HTTP Parameters value |
| AT+HTTPACTION | HTTP Method Action |
| AT+HTTPHEAD | Read the HTTP Header Information of Server Response |
| AT+HTTPREAD | Read the response information of HTTP Server |
| AT+HTTPDATA | Input HTTP Data |
| AT+HTTPPOSTFILE | Send HTTP Request to HTTP(S)server by File |
| AT+HTTPREADFILE | Receive HTTP Response Content to a file |

---

## 16.2 Detailed Description of AT Commands for HTTP(S)

### 16.2.1 AT+HTTPINIT — Start HTTP Service

AT+HTTPINIT is used to start HTTP service by activating PDP context. You must execute AT+HTTPINIT before any other HTTP related operations.

| AT+HTTPINIT — Start HTTP Service | |
|---|---|
| Test Command: `AT+HTTPINIT=?` | Response: `OK` |
| Execute Command: `AT+HTTPINIT` | Response:<br>1) If start HTTP service successfully: `OK`<br>2) If failed: `ERROR` |
| Parameter Saving Mode | - |
| Max Response Time | 120000ms |
| Reference | - |

**Defined Values**

| Parameter | Description |
|---|---|
| `<err>` | The type of error — please refer to Section 16.4 |

**Examples**
```
AT+HTTPINIT
OK
```

---

### 16.2.2 AT+HTTPTERM — Stop HTTP Service

AT+HTTPTERM is used to stop HTTP service.

| AT+HTTPTERM — Stop HTTP Service | |
|---|---|
| Test Command: `AT+HTTPTERM=?` | Response: `OK` |
| Execute Command: `AT+HTTPTERM` | Response:<br>1) If stop HTTP service successfully: `OK`<br>2) If failed: `ERROR` |
| Parameter Saving Mode | - |
| Max Response Time | 120000ms |
| Reference | - |

**Examples**
```
AT+HTTPTERM
OK
```

---

### 16.2.3 AT+HTTPPARA — Set HTTP Parameters value

AT+HTTPPARA is used to set HTTP parameters value. When you want to access a HTTP server, you should input `<value>` like `http://'server'/'path':'tcpPort'`. In addition, `https://'server'/'path':'tcpPort'` is used to access a HTTPS server.

| AT+HTTPPARA — Set HTTP Parameters value | |
|---|---|
| Test Command: `AT+HTTPPARA=?` | Response: `OK` |
| Write Command: `AT+HTTPPARA="URL",<url>` | Response:<br>1) If parameter format is right: `OK`<br>2) If parameter format is not right or other errors occur: `ERROR` |
| Write Command: `AT+HTTPPARA="CONNECTTO",<conn_timeout>` | Response:<br>1) If parameter format is right: `OK`<br>2) If parameter format is not right or other errors occur: `ERROR` |
| Write Command: `AT+HTTPPARA="RECVTO",<recv_timeout>` | Response:<br>1) If parameter format is right: `OK`<br>2) If parameter format is not right or other errors occur: `ERROR` |
| Write Command: `AT+HTTPPARA="CONTENT",<content_type>` | Response:<br>1) If parameter format is right: `OK`<br>2) If parameter format is not right or other errors occur: `ERROR` |
| Write Command: `AT+HTTPPARA="ACCEPT",<accept-type>` | Response:<br>1) If parameter format is right: `OK`<br>2) If parameter format is not right or other errors occur: `ERROR` |
| Write Command: `AT+HTTPPARA="SSLCFG",<sslcfg_id>` | Response:<br>1) If parameter format is right: `OK`<br>2) If parameter format is not right or other errors occur: `ERROR` |
| Write Command: `AT+HTTPPARA="USERDATA",<user_data>` | Response:<br>1) If parameter format is right: `OK`<br>2) If parameter format is not right or other errors occur: `ERROR` |
| Write Command: `AT+HTTPPARA="READMODE",<readmode>` | Response:<br>1) If parameter format is right: `OK`<br>2) If parameter format is not right or other errors occur: `ERROR` |
| Parameter Saving Mode | - |
| Max Response Time | 120000ms |
| Reference | - |

**Defined Values**

| Parameter | Description |
|---|---|
| `<url>` | URL of network resource. String, start with `"http://"` or `"https://"`<br>a) `http://'server':'tcpPort'/'path'`<br>b) `https://'server':'tcpPort'/'path'`<br>`"server"` — DNS domain name or IP address<br>`"path"` — path to a file or directory of a server<br>`"tcpPort"` — HTTP default value is 80, HTTPS default value is 443 (can be omitted) |
| `<conn_timeout>` | Timeout for accessing server. Numeric type, range is 20–120s, default is 120s. |
| `<recv_timeout>` | Timeout for receiving data from server. Numeric type, range is 2s–120s, default is 20s. |
| `<content_type>` | This is for HTTP "Content-Type" tag. String type, max length is 256, default is `"text/plain"`. |
| `<accept-type>` | This is for HTTP "Accept-type" tag. String type, max length is 256, default is `"*/*"`. |
| `<sslcfg_id>` | This is setting SSL context id. Numeric type, range is 0–9. Default is 0. Please refer to Chapter 19 of this document. |
| `<user_data>` | The customized HTTP header information. String type, max length is 256. |
| `<readmode>` | For HTTPREAD. Numeric type, can be set to 0 or 1. If set to 1, you can read the response content data from the same position repeatedly. The limit is that the size of HTTP server response content should be shorter than 1M. Default is 0. |

> **NOTE:** When you want to use content-type `multipart/form-data` to transfer data, you should set `AT+HTTPPARA="CONTENT","multipart/form-data"`. The boundary header will be constructed automatically.

**Examples**
```
AT+HTTPPARA="URL","http://www.baidu.com"
OK
```

---

### 16.2.4 AT+HTTPACTION — HTTP Method Action

AT+HTTPACTION is used to perform a HTTP Method. You can use HTTPACTION to send a GET/POST request to a HTTP/HTTPS server.

| AT+HTTPACTION — HTTP Method Action | |
|---|---|
| Test Command: `AT+HTTPACTION=?` | Response: `+HTTPACTION: (0-4)`<br>`OK` |
| Write Command: `AT+HTTPACTION=<method>` | Response:<br>1) If parameter format is right: `OK`<br>`+HTTPACTION: <method>,<statuscode>,<datalen>`<br>2) If parameter format is right but server connected unsuccessfully: `OK`<br>`+HTTPACTION: <method>,<errcode>,<datalen>`<br>3) If parameter format is not right or other errors occur: `ERROR` |
| Parameter Saving Mode | - |
| Max Response Time | 120000ms |
| Reference | - |

**Defined Values**

| Parameter | Description |
|---|---|
| `<method>` | HTTP method specification:<br>`0` — GET<br>`1` — POST<br>`2` — HEAD<br>`3` — DELETE<br>`4` — PUT |
| `<statuscode>` | Please refer to the end of this chapter |
| `<datalen>` | The length of data received |

**Examples**
```
AT+HTTPACTION=?
+HTTPACTION: (0-4)
OK

AT+HTTPACTION=0
OK
+HTTPACTION: 0,200,104220
```

---

### 16.2.5 AT+HTTPHEAD — Read the HTTP Header Information of Server Response

AT+HTTPHEAD is used to read the HTTP header information of server response when the module receives the response data from server.

| AT+HTTPHEAD — Read the HTTP Header Information of Server Response | |
|---|---|
| Test Command: `AT+HTTPHEAD=?` | Response: `OK` |
| Execute Command: `AT+HTTPHEAD` | Response:<br>1) If read the header information successfully:<br>`+HTTPHEAD: <data_len>`<br>`<data>`<br>`OK`<br>2) If read failed: `ERROR` |
| Parameter Saving Mode | - |
| Max Response Time | 120000ms |
| Reference | - |

**Defined Values**

| Parameter | Description |
|---|---|
| `<data_len>` | The length of HTTP header |
| `<data>` | The header information of HTTP response |

**Examples**
```
AT+HTTPHEAD
+HTTPHEAD: 653
HTTP/1.1 200 OK
Content-Type: text/html
Connection: keep-alive
...
OK
```

---

### 16.2.6 AT+HTTPREAD — Read the response information of HTTP Server

After sending HTTP(S) GET/POST requests, you can retrieve HTTP(S) response information from the server via UART/USB port using AT+HTTPREAD. When the `<datalen>` of `+HTTPACTION: <method>,<statuscode>,<datalen>` is not equal to 0, you can execute `AT+HTTPREAD=<start_offset>,<byte_size>` to read data to port. If `<byte_size>` is set greater than the size of data saved in buffer, all data in cache will be output to port.

| AT+HTTPREAD — Read the response information of HTTP Server | |
|---|---|
| Test Command: `AT+HTTPREAD=?` | Response: `OK` |
| Read Command: `AT+HTTPREAD?` | Response:<br>1) If check successfully: `+HTTPREAD: LEN,<len>`<br>`OK`<br>2) If failed: `ERROR` |
| Write Command: `AT+HTTPREAD=[<start_offset>,]<byte_size>` | Response:<br>1) If read the response info successfully:<br>`OK`<br>`+HTTPREAD: <data_len>`<br>`<data>`<br>`+HTTPREAD: 0`<br>(If `<byte_size>` is bigger than data received, only actual data size is returned)<br>2) If read failed: `ERROR` |
| Parameter Saving Mode | - |
| Max Response Time | 120000ms |
| Reference | - |

**Defined Values**

| Parameter | Description |
|---|---|
| `<start_offset>` | The start position of reading |
| `<byte_size>` | The length of data to read |
| `<data_len>` | The actual length of read data |
| `<data>` | Response content from HTTP server |
| `<len>` | Total size of data saved in buffer |

**Examples**
```
AT+HTTPREAD?
+HTTPREAD: LEN,22505
OK

AT+HTTPREAD=0,500
OK
+HTTPREAD: 500
...
+HTTPREAD: 0
```

> **NOTE:** The response content received from server will be saved in cache, and would not be cleaned up by AT+HTTPREAD. Due to the max size of protocol stack being 64K bytes (CAT4 module is 10K bytes), when the total size of the data from server is bigger than that and `READMODE` is 0, you should read the data quickly, or you will fail to read it.

---

### 16.2.7 AT+HTTPDATA — Input HTTP Data

You can use AT+HTTPDATA to input data to post when sending a HTTP/HTTPS POST request.

| AT+HTTPDATA — Input HTTP Data | |
|---|---|
| Test Command: `AT+HTTPDATA=?` | Response: `OK` |
| Write Command: `AT+HTTPDATA=<size>,<time>` | Response:<br>1) If parameter format is right:<br>`DOWNLOAD`<br>`<input data here>`<br>When the total size of inputted data reaches `<size>`, TA will report: `OK`<br>Otherwise the serial port will be blocked.<br>2) If parameter format is wrong or other errors occur: `ERROR` |
| Parameter Saving Mode | - |
| Max Response Time | - |
| Reference | - |

**Defined Values**

| Parameter | Description |
|---|---|
| `<size>` | Size in bytes of the data to post. Range is 1–153600 bytes. |
| `<time>` | Maximum time in seconds to input data. Range is 10–65535. |

**Examples**
```
AT+HTTPDATA=18,1000
DOWNLOAD
Message=helloworld
OK
```

---

### 16.2.8 AT+HTTPPOSTFILE — Send HTTP Request to HTTP(S) server by File

You can also send an HTTP request from a file via AT+HTTPPOSTFILE. The URL must be set by AT+HTTPPARA before executing AT+HTTPPOSTFILE. The parameter `<path>` sets the file directory. When the modem has received a response from the HTTP server, it will report the following URC:
`+HTTPPOSTFILE: <statuscode>,<datalen>`

| AT+HTTPPOSTFILE — Send HTTP Request to HTTP(S) server by File | |
|---|---|
| Test Command: `AT+HTTPPOSTFILE=?` | Response: `+HTTPPOSTFILE: <filename>[,(1-2)[,(0-4)[,(0-1)]]]`<br>`OK` |
| Write Command: `AT+HTTPPOSTFILE=<filename>[,<path>[,<method>[,<send_header>]]]` | Response:<br>1) If format right and server connected successfully:<br>a) If `<method>` is valid: `OK`<br>`+HTTPPOSTFILE: <method>,<statuscode>,<datalen>`<br>b) If `<method>` is ignored: `OK`<br>`+HTTPPOSTFILE: <statuscode>,<datalen>`<br>2) If format right but server connected unsuccessfully:<br>a) If `<method>` is valid: `OK`<br>`+HTTPPOSTFILE: <method>,<errcode>,0`<br>b) If `<method>` is ignored: `OK`<br>`+HTTPPOSTFILE: <errcode>,0`<br>3) If format is not right or any other error: `ERROR` |
| Parameter Saving Mode | - |
| Max Response Time | - |
| Reference | - |

**Defined Values**

| Parameter | Description |
|---|---|
| `<filename>` | String type, filename, max length is 112 bytes. |
| `<path>` | Directory where the sent file is saved. Numeric type, range 1–2.<br>`1` — C:/ (local storage)<br>`2` — D:/ (SD card) |
| `<method>` | HTTP method specification:<br>`0` — GET<br>`1` — POST<br>`2` — HEAD<br>`3` — DELETE<br>`4` — PUT<br>If not provided, value is taken from the post file. |
| `<send_header>` | Send file as HTTP header and Body or only as Body. Numeric type, range 0–1, default 0.<br>`0` — Send file as Body<br>`1` — Send file as HTTP header and body |
| `<statuscode>` | Please refer to the end of this chapter |
| `<datalen>` | The length of data received |

**Examples**
```
AT+HTTPPOSTFILE=?
+HTTPPOSTFILE: <filename>[,(1-2)[,(0-4)[,(0-1)]]]
OK

AT+HTTPPOSTFILE="getbaidu.txt",1
OK
+HTTPPOSTFILE: 200,14615

AT+HTTPPOSTFILE="getbaidu.txt",1,1,1
OK
+HTTPPOSTFILE: 1,200,14615
```

---

### 16.2.9 AT+HTTPREADFILE — Receive HTTP Response Content to a file

After executing AT+HTTPACTION or AT+HTTPPOSTFILE, you can receive the HTTP server response content to a file via AT+HTTPREADFILE. Before executing AT+HTTPREADFILE, either `+HTTPACTION: <method>,<statuscode>,<datalen>` or `+HTTPPOSTFILE: <statuscode>,<datalen>` must have been received. The parameter `<path>` sets the directory to save the file. If `<path>` is omitted, the file will be saved to local storage.

| AT+HTTPREADFILE — Receive HTTP Response Content to a File | |
|---|---|
| Test Command: `AT+HTTPREADFILE=?` | Response: `+HTTPREADFILE: <filename>[,(1-2)]`<br>`OK` |
| Write Command: `AT+HTTPREADFILE=<filename>[,<path>]` | Response:<br>1) If parameter format is right: `OK`<br>`+HTTPREADFILE: <errcode>`<br>2) If failed: `OK`<br>`+HTTPREADFILE: <errcode>`<br>3) If parameter format is not right or any other error: `ERROR` |
| Parameter Saving Mode | - |
| Max Response Time | - |
| Reference | - |

**Defined Values**

| Parameter | Description |
|---|---|
| `<filename>` | String type, filename, max length is 112 bytes. |
| `<path>` | Directory where the read file is saved. Numeric type, range 1–2.<br>`1` — C:/ (local storage)<br>`2` — D:/ (SD card) |

**Examples**
```
AT+HTTPREADFILE=?
+HTTPREADFILE: <filename>[,(1-2)]
OK

AT+HTTPREADFILE="readbaidu.dat"
OK
+HTTPREADFILE: 0
```

---

## 16.3 Command Result Codes

### 16.3.1 Description of `<statuscode>`

| `<statuscode>` | Description |
|---|---|
| 100 | Continue |
| 101 | Switching Protocols |
| 200 | OK |
| 201 | Created |
| 202 | Accepted |
| 203 | Non-Authoritative Information |
| 204 | No Content |
| 205 | Reset Content |
| 206 | Partial Content |
| 300 | Multiple Choices |
| 301 | Moved Permanently |
| 302 | Found |
| 303 | See Other |
| 304 | Not Modified |
| 305 | Use Proxy |
| 307 | Temporary Redirect |
| 400 | Bad Request |
| 401 | Unauthorized |
| 402 | Payment Required |
| 403 | Forbidden |
| 404 | Not Found |
| 405 | Method Not Allowed |
| 406 | Not Acceptable |
| 407 | Proxy Authentication Required |
| 408 | Request Timeout |
| 409 | Conflict |
| 410 | Gone |
| 411 | Length Required |
| 412 | Precondition Failed |
| 413 | Request Entity Too Large |
| 414 | Request-URI Too Large |
| 415 | Unsupported Media Type |
| 416 | Requested range not satisfiable |
| 417 | Expectation Failed |
| 500 | Internal Server Error |
| 501 | Not Implemented |
| 502 | Bad Gateway |
| 503 | Service Unavailable |
| 504 | Gateway timeout |
| 505 | HTTP Version not supported |
| 600 | Not HTTP PDU |
| 601 | Network Error |
| 602 | No memory |
| 603 | DNS Error |
| 604 | Stack Busy |

---

### 16.3.2 Description of `<errcode>`

| `<errcode>` | Meaning |
|---|---|
| 0 | Success |
| 701 | Alert state |
| 702 | Unknown error |
| 703 | Busy |
| 704 | Connection closed error |
| 705 | Timeout |
| 706 | Receive/send socket data failed |
| 707 | File not exists or other memory error |
| 708 | Invalid parameter |
| 709 | Network error |
| 710 | Start a new SSL session failed |
| 711 | Wrong state |
| 712 | Failed to create socket |
| 713 | Get DNS failed |
| 714 | Connect socket failed |
| 715 | Handshake failed |
| 716 | Close socket failed |
| 717 | No network error |
| 718 | Send data timeout |
| 719 | CA missed |

---

## 16.4 Unsolicited Result Codes

| URC | Description |
|---|---|
| `+HTTP_PEER_CLOSED` | Notification message. While received, it means the connection has been closed by server. |
| `+HTTP_NONET_EVENT` | Notification message. While received, it means the network is now unavailable. |

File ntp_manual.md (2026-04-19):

# A76XX Series — AT Command Manual V1.09

---

## 14.2.3 AT+CNTP — Update system time

This command is used to update system time with NTP server.

### AT+CNTP — Update system time

**Test Command**

```
AT+CNTP=?
```

**Response**

```
+CNTP: "HOST",(-96~96)

OK
```

---

**Read Command**

```
AT+CNTP?
```

**Response**

```
+CNTP: <host>,<timezone>

OK
```

---

**Write Command**

```
AT+CNTP=<host>[,<timezone>]
```

**Response**

1. If successfully:

```
OK
```

2. If failed:

```
ERROR
```

---

**Execute Command**

```
AT+CNTP
```

**Response**

1. If successfully:

```
OK

+CNTP: <err>
```

2. If failed:

```
ERROR
```

| Parameter Saving Mode | — |
|---|---|
| Max Response Time | — |
| Reference | |

### Defined Values

| Parameter | Description |
|---|---|
| `<host>` | NTP server address, length is 0–255. |
| `<timezone>` | Local time zone, the range is (−96 to 96), default value is 32. |

### Examples

```
AT+CNTP="120.25.115.20",32
OK

AT+CNTP
OK

+CNTP: 0
```

---

## 14.3 Command Result Codes

### 14.3.2 Description of `<err>` of NTP

| `<err>` | Description |
|---|---|
| 0 | Operation succeeded |
| 1 | Unknown error |
| 2 | Wrong parameter |
| 3 | Wrong date and time calculated |
| 4 | Network error |
| 5 | Time zone error |
| 6 | Time out error |

---

*Source: SIMCom A76XX Series AT Command Manual V1.09, pages 311–313*

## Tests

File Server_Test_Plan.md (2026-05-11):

# Server Verification Plan

> Python black-box verifiers exercising the deployed server from a dev machine.
> Source tree: `server_test/`. Target: `https://robin-gpu.cpe.ku.ac.th/` (or `STAGING_URL` override).
> Companion to `Server_Implementation_Plan.md`. Status: all suites green (see `IMPLEMENTATION_STATUS.md`).
>
> **Scope:** wire contract regressions. Server internals tested by `html/tests/` (pytest).

---

## Design Principles

- **Mock device = real TLS client.** `httpx` + fleet client cert/key for mTLS, rate-limit, slot tests.
- **No server imports.** Tests never `from app import …`. Target = HTTP contract.
- **Bit-pattern fixtures.** Binary payloads constructed via `struct.pack` matching `lib/utils/weather_data.h`. CRC fixtures cross-checked against `shared/crc32.c`.
- **Reserved test space.** Region 999 + version ≥ 900,000,000. `db_cleanup` purges pre/post.
- **Configurable target.** `.env` (gitignored): `STAGING_URL`, `ADMIN_USER`, `ADMIN_PASS`, `CA_BUNDLE`, `DEVICE_CERT_DIR`.

---

## Directory Layout (`server_test/`)

```
server_test/
├── conftest.py                ; fixtures: base_url, dev / dev_mtls / dev_no_cert clients, db, db_cleanup, admin_session, campaign_cleanup, sensor_data_seed
├── pyproject.toml             ; ruff + pytest config (markers: slow)
├── requirements.txt           ; httpx[http2], pytest, pytest-asyncio, cryptography, python-dotenv
├── .env.example
├── lib/
│   ├── packed.py              ; encode/decode Weather_Data_Packed_t (parity-tested vs firmware)
│   ├── fixedpt.py             ; S9.7 codec (parity-tested)
│   ├── crc32.py               ; CRC-32/MPEG-2 (parity-tested; check `"123456789"` → 0x0376E6E7)
│   ├── mock_device.py         ; MockDevice: upload(), ota_poll(), ota_download_all()
│   ├── admin.py               ; AdminClient: login, upload_firmware, start/pause/cancel
│   └── test_parity.py         ; CRC + fixedpt + packed self-checks (no network)
├── tests/
│   ├── test_ingest.py         ; T1 (Phase 3)
│   ├── test_ota_device.py     ; T2 (Phase 5)
│   ├── test_admin_auth.py     ; 7 admin auth/RBAC integration tests (S6)
│   ├── test_admin_campaign.py ; T3 (Phase 7) — 25 tests
│   ├── test_admin_ui.py       ; 14 admin UI E2E tests (S8)
│   ├── test_mtls.py           ; T4 (Phase 4)
│   ├── test_load.py           ; T5 — soak/load (pytest -m slow)
│   ├── test_sensor_data.py    ; T6 (Phase 11) — 10 tests
│   └── test_user_management.py; TUM0–TUM11 — 75 tests (see User_Management_Test_Plan.md)
├── fixtures/                  ; firmware_small.bin, firmware_large.bin, packed_samples.json
└── scripts/
    ├── provision_test_certs.sh
    └── cleanup_test_rows.py
```

---

## Suite Summary

All suites currently green on `robin-gpu.cpe.ku.ac.th`.

| Suite | Mirrors | Tests | Notes |
|---|---|---|---|
| **T0** Harness bootstrap | — | 5 | Parity self-checks: CRC, fixedpt (6 vectors + round-trip), packed struct (lengths, header, temp encoding). Fleet shares one cert (no per-device CN). |
| **T1** Ingest | S3 | 9 | Happy / max-batch / idempotency / boundary values (`-256.0` to `+255.992`) / count mismatch 400 / first-seen device upsert / idempotency key format (`{rrr}{sss}:{iso}`) / no-cert 403 / Y2K epoch 0 stored as `2000-01-01T00:00:00+00:00`. |
| **T2** OTA download | S5 | 18 | No-campaign HTML body / metadata regex match (with + without `W.`) / malformed-id 400 / missing-id 400 / slot determinism over 20 ids / chunked download SHA-256 reassembly / out-of-slot 429 + `Retry-After` / per-chunk CRC validation / resumable random offsets / `offset+length > size` 416 / `length=0` or `1024` clamped or rejected / no-campaign chunk 404 / monotone retry across cycles / `download_completions` chunk rows == ceil(size/512), idempotent re-download. |
| **T3** Admin campaign | S7 | 25 | Auth/RBAC; firmware upload response + DB + disk; auto version increment; oversize 413 (491,521 B = 480 KB + 1); start sets `rollout_start`; `rollout_window_days` Pydantic ge=1 le=30 (422); pause/resume preserves `rollout_start`; cancel writes `success_rate`; cohort filter (NULL = all, empty → NULL, restricted excludes); re-start 409; SHA-256 disk-tamper 409; detail aggregates. |
| **S6** Admin auth | S6 | 7 unit + 7 integration | Wrong password 401; role-restricted endpoints; `require_role` factory levels. |
| **T4** mTLS + Nginx | S4 | 6 active (T4-3, T4-6 N/A) | No-cert 403 device path (Nginx 400 also valid — `ssl_verify_client on` blocks at SSL layer); wrong-CA 403 (self-signed via `cryptography`); admin path no-cert → 200/401 (not 403); rate limit (10 conc × 5 cycles → ≥ 1 × 503); TLS 1.2 accept / 1.1 reject; admin vhost header isolation (spoofed `X-SSL-Client-Verify` + `X-Client-DN` ignored). T4-3 (revoked-cert + CRL) deferred — fleet has one shared cert; T4-6 (per-CN throttle) deferred — no second CN exists. |
| **S8** Admin UI | S8 | 14 E2E | Login flow, dashboard pagination, campaign upload/start/pause/cancel via HTMX. Two bugs found + fixed during testing: `POST /admin/logout` route shadowed by admin router (renamed to `/logout-ui`); `delete_cookie` missing `httponly + samesite` to match `set_cookie`. |
| **T5** Soak + load | (post-rollout) | 8 (pytest -m slow) | Soak 100 dev × 1 upload/min × 300 s — no 5xx, p95 < 500 ms. OTA at scale (1000 mock devices, slot-0 cohort 29–71, all see campaign). Slot advancement (~50 more devices become eligible per slot). Jitter smoothing across 5 buckets. Duplicate flood (50 conc → 1 row). Network chaos (resume after disconnect). Power-loss sim (resume from saved offset). 10 % chunk fault injection (all retry to completion). Notes: `SOAK_DURATION_SEC=300`, startup jitter, `Semaphore(50)`. |
| **T6** Sensor data UI | S11 | 10 | Unauth redirect; no-filter default; per-filter (region / station / date-range / BUS); combined; empty-set message; pagination disjoint sets. Prereq fixture seeds 60 rows across 3 days. Fix found: `::date` cast in `_weather_filter` for asyncpg type inference. |
| **TUM0–TUM11** User management | UM1–UM5 | 75 | See `User_Management_Test_Plan.md`. |

---

## Mock Device Contract (`lib/mock_device.py`)

```python
class MockDevice:
    def __init__(self, region: int, station: int, shared_cert: Path, shared_key: Path,
                 base_url: str, ca_bundle: Path): ...
    # device_id = f"{region:03d}{station:03d}"
    async def upload(self, samples: list[Sample]) -> dict: ...
    async def ota_poll(self) -> OtaMetadata | None: ...
    async def ota_download_all(self, expected_size: int, expected_sha256: str,
                               apply_jitter: bool = False) -> bytes: ...
    async def close(self) -> None: ...

@dataclass
class OtaMetadata:
    version: int
    size: int
    sha256: str
    wait_seconds: int = 0   # mirrors W. token (0 if absent)
```

- All mocks share one client cert (Arch §2.1); identity = `?id=` query param.
- `ota_download_all` skips when `wait_seconds > 0`; tests assert `wait_seconds == 0` before calling.
- Per-chunk CRC verified; `AssertionError` on mismatch.
- `apply_jitter=True` sleeps `crc32_mpeg2(id) % OTA_JITTER_MAX_SEC` before first chunk (T5-2b only).

---

## Execution

| Scope | Command |
|---|---|
| Parity (no network) | `pytest server_test/lib/` |
| Per-suite (live server) | `pytest server_test/tests/test_<name>.py` |
| Fast subset on every push | `pytest server_test/ -m "not slow"` |
| Full soak + load (nightly) | `pytest server_test/ -m slow` |
| Teardown | `python server_test/scripts/cleanup_test_rows.py` |

---

## Notes & Open Items

- **DB read access for assertions.** Prefer a read-only test role for fast deterministic assertions; admin HTTP endpoints used otherwise.
- **Staging vs prod.** Reserve `region=999` and `version >= 900_000_000`. Add `FORCE_PROD=1` guard before any test that mutates campaigns.
- **Clock advancement for slot tests** (T2-10 / T3-7b / T5-2a). Currently runs nightly; a staging-only `X-Fake-Now` header would let these run on every push.
- **Slot hash parity.** Server uses `zlib.crc32` (IEEE 802.3, reflected). Firmware uses CRC-32/MPEG-2 (non-reflected). **Different algorithms.** T3-7a asserts slot assignment against `zlib.crc32` only. Devices never hash their own id — they read `W` from the token.
- **Test cert lifecycle.** Single fleet test cert issued via `scripts/issue_device_cert.sh weather-test` is sufficient (Arch §2.1). T4-3 / T4-6 would need additional certs; deferred.

---

## References

- `Server_Implementation_Plan.md`
- `Server_Architecture.md`
- `lib/utils/weather_data.h` — binary schema
- `shared/crc32.c` — firmware CRC implementation
- `Src/ota_manager_task.c` — device OTA state machine

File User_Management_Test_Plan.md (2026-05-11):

# User Management Verification Plan

> Black-box verifiers for the user management feature.
> Test file: `server_test/tests/test_user_management.py`. Implementation: `User_Management_Implementation_Plan.md`.
> Target: `https://robin-gpu.cpe.ku.ac.th/` (or `STAGING_URL` override).
> **Status: 75/75 pass in 81 s** on `robin-gpu.cpe.ku.ac.th` (Python 3.13, pytest 9.0.3, 2026-05-08).

---

## Design

- No server imports. HTTP contract only.
- Isolated test users — username prefix `test_um_`; teardown deletes all `test_um_*`.
- Role matrix coverage from `admin`, `operator`, `viewer`, and unauthenticated.
- CSRF coverage — every mutating form route tested with + without valid token.
- **TUM0 invariant:** all three roles reach every IoT page (dashboard, campaigns, devices, sensor data). Role differentiation is user-management only.

---

## Fixtures (`conftest.py` additions)

```python
@pytest_asyncio.fixture
async def admin_session(base_url, admin_credentials):
    """httpx.AsyncClient with admin JWT cookie."""

@pytest_asyncio.fixture
async def operator_session(base_url, admin_session):
    """Creates test_um_operator; yields session; deletes on teardown."""

@pytest_asyncio.fixture
async def viewer_session(base_url, admin_session):
    """Creates test_um_viewer; yields session; deletes on teardown."""

@pytest_asyncio.fixture
async def test_user_id(admin_session):
    """Creates test_um_target (viewer); yields id; deletes on teardown."""

@pytest_asyncio.fixture(autouse=True)
async def cleanup_um_users(admin_session):
    yield
    users = (await admin_session.get("/admin/users")).json()
    for u in users:
        if u["username"].startswith("test_um_"):
            await admin_session.delete(f"/admin/users/{u['id']}")
```

All sessions are `httpx.AsyncClient` with `access_token` cookie set via login.

---

## Coverage Summary (75/75 pass)

| Group | Scope | Planned | Implemented | Status |
|---|---|---|---|---|
| **TUM0** IoT data parity (all roles) | dashboard/campaigns/sensor reach + unauth redirect | 7  | 6  | ✓ pass |
| **TUM1** API create (`POST /admin/users`) | valid (viewer/admin/op); duplicate 409; short pw 422; invalid role 422; illegal chars 422; missing field 422; op forbidden 403; unauth 401 | 9  | 9  | ✓ pass |
| **TUM2** API update info (`PUT /admin/users/{id}`)  | admin updates other; admin changes own username (no role sent); admin self-demote 403; operator self; operator sends role 403; operator on other 403; viewer on other 403; duplicate 409; not-found 404 | 10 | 10 | ✓ pass |
| **TUM3** API change password (`PUT /admin/users/{id}/password`) | admin own correct/wrong/missing current; admin on other no current; admin on other any current; operator own correct/wrong; operator on other 403; new pw <8 422; deleted-user post-login | 10 | 9  | ✓ pass |
| **TUM4** API delete (`DELETE /admin/users/{id}`) | admin deletes other 204; admin self 403; operator any 403; not-found 404; deleted cannot login 401 | 5  | 5  | ✓ pass |
| **TUM5** UI users page (`GET /admin/users.html`) | admin 200 + table; operator blocked; viewer blocked; unauth → login; admin's own row has no delete; other rows have delete | 6  | 5  | ✓ pass |
| **TUM6** UI profile page (`GET /admin/profile.html`)| admin (role dropdown present); operator (no dropdown); viewer; unauth; profile link in nav | 5  | 5  | ✓ pass |
| **TUM7** UI form create (`POST /admin/users/create-ui`) | valid; missing CSRF 403; wrong CSRF 403; pw mismatch inline (no DB write); short pw inline; duplicate inline; operator 403 | 7  | 7  | ✓ pass |
| **TUM8** UI form update info | admin updates other; admin self-demote inline/403; operator updates self; operator sends role 403; missing CSRF 403 | 6  | 5  | ✓ pass |
| **TUM9** UI form change password | self correct; mismatch confirm inline; wrong current inline; admin on other (no current); missing CSRF 403; new pw login | 6  | 6  | ✓ pass |
| **TUM10** UI form delete | admin deletes other (HTMX row remove); admin self 403; missing CSRF 403; operator 403; deleted row absent from table refresh | 5  | 5  | ✓ pass |
| **TUM11** Navigation | admin sees Users link; operator does not; profile link present | 3  | 3  | ✓ pass |
| **Total** | | **79** | **75** | **75/75 pass** |

> 4 plan-level scenarios consolidated during implementation (TUM0-4, TUM3-2/3, TUM5-2, TUM8-5 merged into related tests).

---

## Helpers

CSRF extraction:

```python
async def get_csrf_token(session: httpx.AsyncClient, page_url: str) -> str:
    """Loads page; extracts csrf_token from <input> or meta tag (regex; no html lib)."""
```

Teardown (autouse fixture): list all users via `/admin/users`, delete those with `username.startswith("test_um_")`.

---

## Execution

```bash
# From project root
cd server_test
pytest tests/test_user_management.py -v

# Staging override
STAGING_URL=https://staging.example.com pytest tests/test_user_management.py -v

# Single group
pytest tests/test_user_management.py::TestCreateUser -v
```

Required env vars (`server_test/.env`):

```
STAGING_URL=https://robin-gpu.cpe.ku.ac.th
ADMIN_USER=admin
ADMIN_PASS=<from iot.env>
```

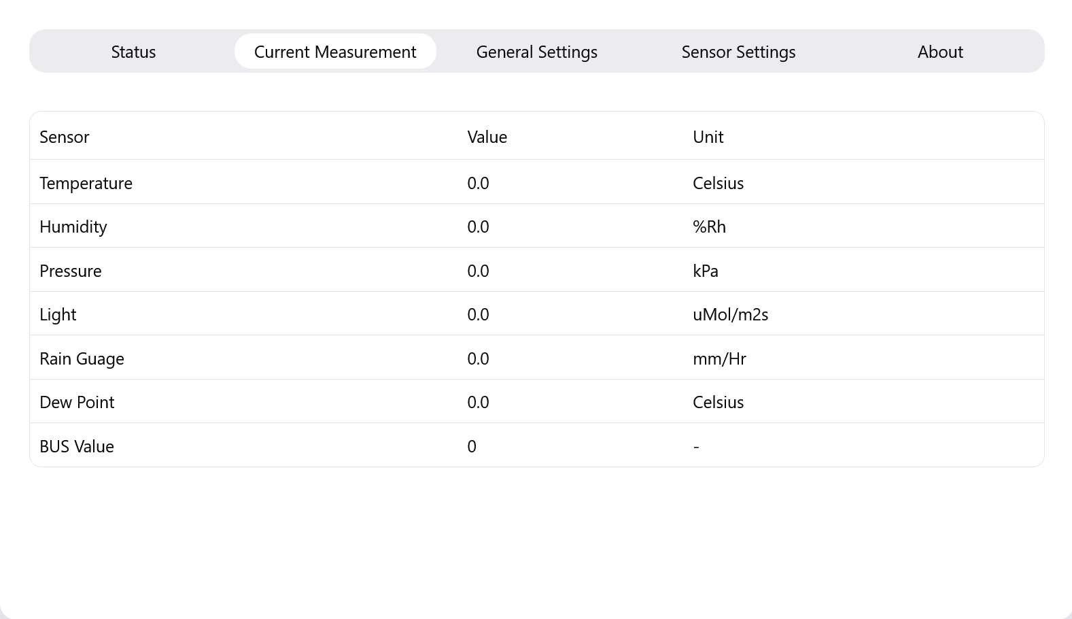
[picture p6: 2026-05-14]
host/screenshots/Measurement_Tab.png

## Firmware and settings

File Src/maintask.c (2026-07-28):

/*
 * Peripheral allocation:
 * - USART1 : RS485 Modbus RTU (Light addr = 0x01, Rain addr = 0x02)
 * - USART2 : Console port
 * - USART3 : A7670E LTE Modem
 * - I2C1   : MCP23017 (UI Interface) (addr = 0x20)
 * - I2C2   : Sensor bus (BMP390(addr=0x76) and SHT45(addr=0x44))
 * - SPI1   : FRAM (2M x 8bit)
 */
/* USER CODE END Header */

/* Includes ------------------------------------------------------------------*/
#include <math.h>
#include <stdio.h>

#include "FreeRTOS.h"
#include "task.h"
#include "main.h"
#include "cmsis_os.h"

#include "fatfs.h"
#include "i2c.h"
#include "rtc.h"
#include "sdmmc.h"
#include "usb_otg.h"
#include "usart.h"
#include "spi.h"

#include "tusb.h"
#include "uart_subsystem.h"
#include "modbus.h"
#include "bmp390.h"
#include "ms5611.h"
#include "sht45.h"
#include "a7670.h"
#include "ui.h"
#include "nv_database.h"
#include "weather_data.h"
#include "datetime.h"
#include "rain_light.h"
#include "weather_data.h"
#include "fixedptc.h"
#include "watchdog_task.h"

#define SENSOR_ALPHA 0.5f
#define SENSOR_BETA (1.0f - SENSOR_ALPHA)

extern osThreadId_t MainTaskHandle;      // MainTaskHandle was casted from TaskHandle_t to osThreadId_t
extern osThreadId_t SslUploadTaskHandle; // SslUploadTaskHandle was casted from TaskHandle_t to osThreadId_t
extern int8_t g_wdt_id_maintask;         // Watchdog slot ID for maintask

/* Current weather data */
Meta_Data_t db_meta_data;
Weather_Data_t weather_data = {0};
float accum_rainfall = 0.0f;
struct
{
    bool (*pt_init)(I2C_HandleTypeDef *hi2c);
    bool (*pt_soft_reset)(void);
    bool (*pt_get_sensor_data)(float *temperature, float *pressure);
    bool (*pt_ping)(I2C_HandleTypeDef *hi2c);
} pressure_temperature_sensor = {NULL, NULL, NULL, NULL};

/* ------------------------------------------------------------------------ */
static inline bool SaveRecordToSD(FIL *file, Weather_Data_Packed_t *data)
{
    /*
     * Line structure:
     * dd-mmm-yyyy hh:mm:ss,-ttt.tt,hhh.hh,ppp.pp,llll,rrr.rr,eee.ee,bb.bb
     * Total length = 67 characters + "\r\n" = 69 characters
     */
    const char *month_str[] = {"Jan", "Feb", "Mar", "Apr", "May", "Jun", "Jul", "Aug", "Sep", "Oct", "Nov", "Dec"};
    static char line[80], *pos;
    static RTC_DateTime_t dt;
    unsigned int len, written;

    if (file == NULL || data == NULL)
        return false;

    get_datetime_from_epoch(data->time_stamp, &dt);

    pos = line;
    pos += sprintf(pos, "%02d-%s-20%02d %02d:%02d:%02d,", dt.day, month_str[dt.month - 1], dt.year, dt.hours, dt.minutes, dt.seconds);
    pos += fixedpt_str(data->temperature, pos, 2);
    *pos++ = ',';
    pos += fixedpt_str(data->humidity, pos, 2);
    *pos++ = ',';
    pos += fixedpt_str(data->pressure, pos, 2);
    *pos++ = ',';
    pos += sprintf(pos, "%u,", data->light_par);

    // CHeck pos is likely to overflow here if strlen(line) >= 60
    *pos = '\0'; // Temporary null-termination for strlen() check
    if (strlen(line) >= 60)
        return false;

    pos += fixedpt_str(data->rainfall, pos, 2);
    *pos++ = ',';
    pos += fixedpt_str(data->dew_point, pos, 2);
    *pos++ = ',';
    pos += fixedpt_str(data->bus_value, pos, 2);
    *pos++ = '\r';
    *pos++ = '\n';
    *pos = '\0';

    // Write the line to SD card
    len = strlen(line);
    if (f_write(file, line, len, &written) != FR_OK || written != len)
        return false;

    f_sync(file);
    return true;
}

/* ------------------------------------------------------------------------ */
// #if __STDC_VERSION__ >= 201112L || __cplusplus >= 201103L
// #define U16_LITERAL(x) u##x
// #else
// // Fallback for older compilers - may not be strictly UTF-16
// #define U16_LITERAL(x) L##x
// #endif
static void SaveToSD(void)
{
    static const char *header = "Date Time,Temperature (C),Humidity (%Rh),Pressure (kPa),Light PAR (umol/s*m^2),Rainfall (mm/hr),Dew Point (C),BUS\r\n";
    static const char *filename = "weather_data.csv";
    FIL file;
    Weather_Data_Packed_t data;
    uint16_t total_to_sd, i;

    FRESULT res;
    FATFS fatfs;

    if (!(system_ready_status.sd_detected) || system_ready_status.sd_write_protected)
        return;

    res = f_mount(&fatfs, "", 1);
    if (res != FR_OK)
    {
        printf("Failed to mount SD card: %d\r\n", res);
        return;
    }

    if (f_open(&file, filename, FA_OPEN_EXISTING | FA_WRITE | FA_READ) != FR_OK)
    {
        printf("Failed to open file for appending, trying to create a new file...\r\n");
        if (f_open(&file, filename, FA_CREATE_ALWAYS | FA_WRITE) != FR_OK) // Try to create a new file if failed to open existing file
        {
            printf("Failed to create file\r\n");
            return;
        }

        // Write header line for new file
        f_write(&file, header, strlen(header), NULL);
        f_sync(&file);
    }
    else
    {
        f_lseek(&file, f_size(&file)); // Seek to the end of the file
    }

    total_to_sd = DB_GetTotalToSD();
    if (total_to_sd == 0u)
        return;

    for (i = 0; i < total_to_sd; i++)
    {
        if (!(system_ready_status.fram_ready = DB_ToSDwithOffset(i, &data)))
            break; // Failed to read data from FRAM, stop the process

        if (!SaveRecordToSD(&file, &data))
            break; // Failed to write data to SD card, stop the process
    }
    f_close(&file);

    res = f_mount(NULL, "", 0); // Unmount the SD card
    if (res != FR_OK)
    {
        printf("Failed to unmount SD card: %d\r\n", res);
        return;
    }

    printf("Saved %u records to SD card, %u records remaining in FRAM\r\n", i, total_to_sd - i);
    if (i > 0)
        system_ready_status.fram_ready = DB_IncSDTail(i); // Update SD tail in database after successfully saving "i" records to SD card
}

/* ------------------------------------------------------------------------ */
static inline float ema(float old, float new)
{
    return (SENSOR_ALPHA * new) + (SENSOR_BETA * old);
}

/* ------------------------------------------------------------------------ */
static inline void Reinitalize(void)
{
    if (!system_ready_status.usart_ready)
    {
        if ((system_ready_status.usart_ready = UART_Sys_Init()))
        {
            // A7670E Modem
            if ((system_ready_status.a7670_ready = modem_init(&huart3)))
                LED_DEBUG_BLUE_ON();
            else
                LED_DEBUG_BLUE_OFF();

            // Modbus
            system_ready_status.modbus_ready = modbus_init(&huart1);
        }
    }
    else
    {
        // A7670E Modem
        if (!system_ready_status.a7670_ready)
        {
            if ((system_ready_status.a7670_ready = modem_init(&huart3)))
                LED_DEBUG_BLUE_ON();
            else
                LED_DEBUG_BLUE_OFF();
        }

        // Modbus
        if (!system_ready_status.modbus_ready)
            system_ready_status.modbus_ready = modbus_init(&huart1);
    }

    if (!system_ready_status.bmp390_ready)
        system_ready_status.bmp390_ready = pressure_temperature_sensor.pt_init(&hi2c2);
    if (!system_ready_status.sht45_ready)
        system_ready_status.sht45_ready = sht45_init(&hi2c2);
    if (!system_ready_status.fram_ready)
        system_ready_status.fram_ready = DB_Init(&hspi1);

    /* -------------------------------------------------------- */
    /* If some devices are still not ready. blink the red led   */
    if (!(system_ready_status.modbus_ready && system_ready_status.bmp390_ready &&
          system_ready_status.sht45_ready && system_ready_status.fram_ready))
        ui_interface.led_red = LED_BLINK;
    else
        ui_interface.led_red = LED_OFF;
}

/* ------------------------------------------------------------------------ */
static inline void SensorUpdate(void)
{
    float sht45_temperature, sht45_humidity;
    float bmp390_temperature, bmp390_pressure;
    float rainfall;
    uint16_t light_par;
    static bool first_run = true;

    if (system_ready_status.bmp390_ready)
    {
        system_ready_status.bmp390_ready = pressure_temperature_sensor.pt_get_sensor_data(&bmp390_temperature, &bmp390_pressure);
        bmp390_pressure /= 1000.0f; // Convert PA to kPA
    }
    else
    {
        bmp390_temperature = 0.0f;
        bmp390_pressure = 0.0f;
    }

    if (system_ready_status.sht45_ready)
        system_ready_status.sht45_ready = sht45_get_sensor_data(&sht45_temperature, &sht45_humidity);
    else
    {
        sht45_temperature = 0.0f;
        sht45_humidity = 0.0f;
    }

    system_ready_status.light_ok = get_light(&light_par);
    my_delay(4); /* Wait for modbus to be settled */
    system_ready_status.rainfall_ok = get_rain(&rainfall);

    /* Processing sensors data */

    // Adjust data
    sht45_temperature += db_meta_data.temperature_adj;
    sht45_humidity += db_meta_data.humidity_adj;
    bmp390_temperature += db_meta_data.temperature_adj;
    bmp390_pressure += db_meta_data.pressure_adj;
    {
        /* saturating signed add for uint16_t + int16_t */
        int32_t lp = (int32_t)light_par + (int32_t)db_meta_data.light_adj;
        light_par = (lp < 0) ? 0u : (lp > 65535) ? 65535u
                                                 : (uint16_t)lp;
    }

    // EMA fusion
    if (first_run)
    {
        weather_data.temperature = sht45_temperature;
        weather_data.humidity = sht45_humidity;
        weather_data.pressure = bmp390_pressure;
        weather_data.light_par = light_par;
        first_run = false;
    }
    else
    {
        weather_data.temperature = ema(weather_data.temperature, (sht45_temperature + bmp390_temperature) / 2.0f);
        weather_data.humidity = ema(weather_data.humidity, sht45_humidity);
        weather_data.pressure = ema(weather_data.pressure, bmp390_pressure);

        // EMA simulation for uint16_t from light sensor
        if (light_par & 1)
            light_par = (light_par >> 1) + 1u; // div by 2 and round-up
        else
            light_par >>= 1;

        if (weather_data.light_par & 1)
            weather_data.light_par = (weather_data.light_par >> 1) + 1u; // div by 2 and round-up
        else
            weather_data.light_par >>= 1;

        weather_data.light_par += light_par;
    }

    // Process rain fall. Accumulate for 1 hour
    accum_rainfall += rainfall;
    if (weather_data.sampletime.minutes == 0 && weather_data.sampletime.seconds == 0)
    {
        weather_data.rainfall = accum_rainfall + db_meta_data.rainfall_adj;
        accum_rainfall = 0.0f;
    }
}

/* ------------------------------------------------------------------------ */
static inline float DewPointCalc(float RH, float T) // RH in %, T in C (such as 30 %Rh and 35 C)
{
    // For these b and c constants, (err = 0.35C for -45 < T < 60)
    //
    // Some calculations may use different b and c such as
    // b = 17.123, c = 234.95 (err = 0.15C for 0 < T < 100)

    static const float b = 17.62f;
    static const float c = 243.12f;

    float H, Dp;

    H = ((log10f(RH) - 2.0f) / 0.4343f) + ((b * T) / (c + T));
    Dp = c * H / (b - H); // this is the dew point in Celsius
    return Dp;
}

/* ------------------------------------------------------------------------ */
/*
 * The calculation is per daily basis. The required parameters are:
 *  - Mean air temperaure (Tavg)
 *  - Hours of leaf wetness (Temp < Temp(dew)) (Lw)
 *  - Hours of relative humidity > 90% (Rh)
 *
 * The calculation are in sequential steps as:
 *  1. If Tavg is outside the range of 15 to 38C, then return BUS = 0
 *  2. If Lw < 9 hours, then return BUS = 0
 *  3. Set initial BUS = Lw / 4.0
 *  4. If Rh > 16 hours, then BUS = BUS(from 3) + (Rh - 12.0) / 6.0
 *  5. If Tavg < 23C or Tavg > 26C, then BUS = BUS(from 4) - 2.0
 *  6. If Tavg < 19C or Tavg > 29C, then BUS = BUS(from 5) - 2.0
 *  7. If BUS < 0, then BUS = 0
 *
 */
#define SECONDS_IN_DAY 86400UL
static inline bool BUSCalc(float *BUS)
{
    Weather_Data_Packed_t db_data;
    uint32_t current_epoch, start_epoch;
    uint16_t db_index, total_data, total_data_per_hr, total_valid_data = 0;
    float Tavg;
    uint8_t Lw, Rh;

    *BUS = 0.0f;

    if (!(system_ready_status.fram_ready))
        return false; // Database errors

    // Calculate total records for 1 day
    total_data = 24u * (60u / (uint16_t)(db_meta_data.sampling_interval)); // Estimate total data for 24 hours.
    if (DB_GetTotalData() < total_data)
        return false; // Not enough data for calculation

    // Calculate the starting record number of data
    db_index = (DB_GetHead() - total_data) & 0x7FFF;

    // Verify that the database timestamp is correct.
    current_epoch = get_epoch_from_datetime(&weather_data.sampletime);
    start_epoch = current_epoch - SECONDS_IN_DAY;
    if (!(system_ready_status.fram_ready = DB_GetData(db_index, &db_data)))
        return false; // Failed to read database
    if (db_data.time_stamp != current_epoch - SECONDS_IN_DAY)
        return false; // Database timestamp is incorrect

    // Calculate parameters
    Tavg = 0.0f;
    Lw = 0;
    Rh = 0;
    for (uint16_t i = 0; i < total_data; i++)
    {
        if (!(system_ready_status.fram_ready = DB_GetData(db_index, &db_data)))
            return false; // Failed to read database

        db_index = (db_index + 1) & 0x7FFF; /* advance regardless — was bug: skipped records re-read same slot */

        if (db_data.time_stamp < start_epoch)
            continue; // Skip old data that is outside the 24-hour window

        total_valid_data++;
        Tavg += fixedpt_tofloat(db_data.temperature);
        if (db_data.humidity > fixedpt_rconst(90.0))
            Rh++;
        if (db_data.dew_point < db_data.temperature)
            Lw++;
    }
    if (total_valid_data == 0u)
        return false; // No valid data — avoid divide-by-zero
    Tavg /= (float)total_valid_data;
    total_data_per_hr = total_valid_data / 24u; // Count in the unit of hour (not per sampling)
    if (total_data_per_hr == 0u)
        return false;        // Too few records to form even 1 sample/hour — avoid divide-by-zero
    Rh /= total_data_per_hr; // Count in the unit of hour (not per sampling)
    Lw /= total_data_per_hr;

    // Calculate BUS. BUS is already initialized to 0.0f
    //  1. If Tavg is outside the range of 15 to 38C, then return BUS = 0
    if (Tavg < 15.0f || Tavg > 38.0f)
        return true;

    //  2. If Lw < 9 hours, then return BUS = 0
    if (Lw < 9)
        return true;

    //  3. Set initial BUS = Lw / 4.0
    *BUS = (float)Lw / 4.0f;

    //  4. If Rh > 16 hours, then BUS = BUS(from 3) + (Rh - 12.0) / 6.0
    if (Rh > 16)
        *BUS += ((float)Rh - 12.0f) / 6.0f;

    //  5. If Tavg < 23C or Tavg > 26C, then BUS = BUS(from 4) - 2.0
    if (Tavg < 23.0f || Tavg > 26.0f)
        *BUS -= 2.0f;

    //  6. If Tavg < 19C or Tavg > 29C, then BUS = BUS(from 5) - 2.0
    if (Tavg < 19.0f || Tavg > 29.0f)
        *BUS -= 2.0f;

    //  7. If BUS < 0, then BUS = 0
    if (*BUS < 0.0f)
        *BUS = 0.0f;

    return true;
}

/* ------------------------------------------------------------------------ */
// STM32 HAL RTC wakeup callback (called from RTC_WKUP_IRQHandler)
void HAL_RTCEx_WakeUpTimerEventCallback(RTC_HandleTypeDef *hrtc)
{
    BaseType_t xHigherPriorityTaskWoken = pdFALSE;

    // Direct-to-task notification: zero-copy, no semaphore overhead
    vTaskNotifyGiveFromISR(MainTaskHandle, &xHigherPriorityTaskWoken);

    // Yield to the notified task immediately if it has higher priority
    portYIELD_FROM_ISR(xHigherPriorityTaskWoken);
}
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

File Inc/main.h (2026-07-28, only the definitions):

#define LED_RED_Pin GPIO_PIN_0
#define LED_RED_GPIO_Port GPIOC
#define LED_YELLOW_Pin GPIO_PIN_1
#define LED_YELLOW_GPIO_Port GPIOC
#define LED_GREEN_Pin GPIO_PIN_2
#define LED_GREEN_GPIO_Port GPIOC
#define LED_BLUE_Pin GPIO_PIN_3
#define LED_BLUE_GPIO_Port GPIOC
#define CONSOLE_TX_Pin GPIO_PIN_2
#define CONSOLE_TX_GPIO_Port GPIOA
#define CONSOLE_RX_Pin GPIO_PIN_3
#define CONSOLE_RX_GPIO_Port GPIOA
#define FRAM_CS_Pin GPIO_PIN_4
#define FRAM_CS_GPIO_Port GPIOA
#define FRAM_SCK_Pin GPIO_PIN_5
#define FRAM_SCK_GPIO_Port GPIOA
#define FRAM_MSIO_Pin GPIO_PIN_6
#define FRAM_MSIO_GPIO_Port GPIOA
#define FRAM_MOSI_Pin GPIO_PIN_7
#define FRAM_MOSI_GPIO_Port GPIOA
#define USR_SW1_Pin GPIO_PIN_5
#define USR_SW1_GPIO_Port GPIOC
#define USR_SW2_Pin GPIO_PIN_4
#define USR_SW2_GPIO_Port GPIOC
#define LTE_TX_Pin GPIO_PIN_10
#define LTE_TX_GPIO_Port GPIOB
#define LTE_RX_Pin GPIO_PIN_11
#define LTE_RX_GPIO_Port GPIOB
#define EXT_SCL_Pin GPIO_PIN_13
#define EXT_SCL_GPIO_Port GPIOB
#define EXT_SDA_Pin GPIO_PIN_14
#define EXT_SDA_GPIO_Port GPIOB
#define SD_CD_Pin GPIO_PIN_6
#define SD_CD_GPIO_Port GPIOC
#define SD_WP_Pin GPIO_PIN_7
#define SD_WP_GPIO_Port GPIOC
#define RS485_RX_Pin GPIO_PIN_10
#define RS485_RX_GPIO_Port GPIOA
#define RS485_DE_Pin GPIO_PIN_3
#define RS485_DE_GPIO_Port GPIOB
#define RS485_TX_Pin GPIO_PIN_6
#define RS485_TX_GPIO_Port GPIOB
#define UI_SDA_Pin GPIO_PIN_7
#define UI_SDA_GPIO_Port GPIOB
#define UI_SCL_Pin GPIO_PIN_8
#define UI_SCL_GPIO_Port GPIOB

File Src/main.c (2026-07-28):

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
/* Includes ------------------------------------------------------------------*/
#include "main.h"
#include "cmsis_os.h"
#include "crc.h"
#include "dma.h"
#include "fatfs.h"
#include "i2c.h"
#include "rtc.h"
#include "sdmmc.h"
#include "spi.h"
#include "usart.h"
#include "usb_otg.h"
#include "gpio.h"

/* USER CODE BEGIN Includes */
#include <stdio.h>
/* USER CODE END Includes */


/* USER CODE BEGIN PV */
static IWDG_HandleTypeDef hiwdg_boot;  /* feed bootloader's IWDG during init */
/* USER CODE END PV */

void SystemClock_Config(void);
void PeriphCommonClock_Config(void);
void MX_FREERTOS_Init(void);
/**
  * @brief  The application entry point.
  * @retval int
  */
int main(void)
{

  /* USER CODE BEGIN 1 */

  /* Relocate vector table to the application offset (skip boot loader) */
  SCB->VTOR = 0x8000ul; // Change 0x8000ul to match your offset

  /* Re-initialise IWDG with same config as bootloader (4s timeout).
   * This gives the app time to complete init before WatchdogTask takes over.
   * Note: HAL_IWDG_Init() reconfigures PR/RLR but does NOT reload the
   * down-counter — must call HAL_IWDG_Refresh() right after to reload it. */
  // hiwdg_boot.Instance             = IWDG;
  // hiwdg_boot.Init.Prescaler       = IWDG_PRESCALER_64;
  // hiwdg_boot.Init.Reload          = 2000u;
  // hiwdg_boot.Init.Window          = IWDG_WINDOW_DISABLE;
  // HAL_IWDG_Init(&hiwdg_boot);
  // HAL_IWDG_Refresh(&hiwdg_boot);
  /* USER CODE END 1 */

  /* MCU Configuration--------------------------------------------------------*/

  /* Reset of all peripherals, Initializes the Flash interface and the Systick. */
  HAL_Init();

  /* USER CODE BEGIN Init */
  __enable_irq();                 /* Enable interrupts so TIM17 timebase ticks */
  //HAL_IWDG_Refresh(&hiwdg_boot);
  /* USER CODE END Init */

  /* Configure the system clock */
  SystemClock_Config();

  /* Configure the peripherals common clocks */
  PeriphCommonClock_Config();

  /* USER CODE BEGIN SysInit */
  __HAL_FLASH_PREFETCH_BUFFER_ENABLE();
  /* USER CODE END SysInit */

  /* Initialize all configured peripherals */
  MX_GPIO_Init();
  MX_DMA_Init();
  MX_RTC_Init();
  MX_I2C1_Init();
  MX_I2C2_Init();
  MX_SDMMC1_SD_Init();
  MX_USART1_UART_Init();
  MX_USART2_UART_Init();
  MX_FATFS_Init();
  MX_SPI1_Init();
  MX_USART3_UART_Init();
  MX_USB_OTG_FS_PCD_Init();
  MX_CRC_Init();
  /* USER CODE BEGIN 2 */
  HAL_IWDG_Refresh(&hiwdg_boot);
  LED_DEBUG_GREEN_ON();  /* green LED = app reached main() */
  /* USER CODE END 2 */

  /* Init scheduler */
  osKernelInitialize();  /* Call init function for freertos objects (in cmsis_os2.c) */
  MX_FREERTOS_Init();

  /* Start scheduler */
  osKernelStart();

  /* We should never get here as control is now taken by the scheduler */

  /* Infinite loop */
  /* USER CODE BEGIN WHILE */
    while (1)
    {
    /* USER CODE END WHILE */

    /* USER CODE BEGIN 3 */
    }
  /* USER CODE END 3 */
}

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
/**
  * @brief  Period elapsed callback in non blocking mode
  * @note   This function is called  when TIM17 interrupt took place, inside
  * HAL_TIM_IRQHandler(). It makes a direct call to HAL_IncTick() to increment
  * a global variable "uwTick" used as application time base.
  * @param  htim : TIM handle
  * @retval None
  */
void HAL_TIM_PeriodElapsedCallback(TIM_HandleTypeDef *htim)
{
  if (htim->Instance == TIM17)
  {
    HAL_IncTick();
  }
}

/**
  * @brief  This function is executed in case of error occurrence.
  * @retval None
  */
void Error_Handler(void)
{
  /* USER CODE BEGIN Error_Handler_Debug */
    /* User can add his own implementation to report the HAL error return state */
    __disable_irq();
    while (1)
    {
    }
  /* USER CODE END Error_Handler_Debug */
}
#ifdef USE_FULL_ASSERT
/**
  * @brief  Reports the name of the source file and the source line number
  *         where the assert_param error has occurred.
  * @param  file: pointer to the source file name
  * @param  line: assert_param error line source number
  * @retval None
  */
void assert_failed(uint8_t *file, uint32_t line)
{
  /* USER CODE BEGIN 6 */
    /* User can add his own implementation to report the file name and line number,
       ex: printf("Wrong parameters value: file %s on line %d\r\n", file, line) */
  /* USER CODE END 6 */
}
#endif /* USE_FULL_ASSERT */

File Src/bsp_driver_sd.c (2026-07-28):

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

#ifdef OLD_API
/* kept to avoid issue when migrating old projects. */
#else
/* USER CODE BEGIN FirstSection */
/* can be used to modify / undefine following code or add new definitions */
/* USER CODE END FirstSection */
/* Includes ------------------------------------------------------------------*/
#include "bsp_driver_sd.h"

/* Extern variables ---------------------------------------------------------*/

extern SD_HandleTypeDef hsd1;

/* USER CODE BEGIN BeforeInitSection */
/* can be used to modify / undefine following code or add code */
static HAL_StatusTypeDef SD_DMAConfigRx(SD_HandleTypeDef *hsd);
static HAL_StatusTypeDef SD_DMAConfigTx(SD_HandleTypeDef *hsd);
/* USER CODE END BeforeInitSection */
/**
 * @brief  Initializes the SD card device.
 * @retval SD status
 */
__weak uint8_t BSP_SD_Init(void)
{
    uint8_t sd_state = MSD_OK;
    /* Check if the SD card is plugged in the slot */
    if (BSP_SD_IsDetected() != SD_PRESENT)
    {
        return MSD_ERROR_SD_NOT_PRESENT;
    }
    /* HAL SD initialization */
    sd_state = HAL_SD_Init(&hsd1);
    /* Configure SD Bus width (4 bits mode selected) */
    if (sd_state == MSD_OK)
    {
        /* Enable wide operation */
        if (HAL_SD_ConfigWideBusOperation(&hsd1, SDMMC_BUS_WIDE_4B) != HAL_OK)
        {
            sd_state = MSD_ERROR;
        }
    }

    return sd_state;
}
/* USER CODE BEGIN AfterInitSection */
/* can be used to modify previous code / undefine following code / add code */
/* USER CODE END AfterInitSection */

/* USER CODE BEGIN InterruptMode */
/**
 * @brief  Configures Interrupt mode for SD detection pin.
 * @retval Returns 0
 */
__weak uint8_t BSP_SD_ITConfig(void)
{
    /* Code to be updated by the user or replaced by one from the FW pack (in a stmxxxx_sd.c file) */

    return (uint8_t)0;
}

/* USER CODE END InterruptMode */

/* USER CODE BEGIN BeforeReadBlocksSection */
/* can be used to modify previous code / undefine following code / add code */
/* USER CODE END BeforeReadBlocksSection */
/**
 * @brief  Reads block(s) from a specified address in an SD card, in polling mode.
 * @param  pData: Pointer to the buffer that will contain the data to transmit
 * @param  ReadAddr: Address from where data is to be read
 * @param  NumOfBlocks: Number of SD blocks to read
 * @param  Timeout: Timeout for read operation
 * @retval SD status
 */
__weak uint8_t BSP_SD_ReadBlocks(uint32_t *pData, uint32_t ReadAddr, uint32_t NumOfBlocks, uint32_t Timeout)
{
    uint8_t sd_state = MSD_OK;

    if (HAL_SD_ReadBlocks(&hsd1, (uint8_t *)pData, ReadAddr, NumOfBlocks, Timeout) != HAL_OK)
    {
        sd_state = MSD_ERROR;
    }

    return sd_state;
}

/* USER CODE BEGIN BeforeWriteBlocksSection */
/* can be used to modify previous code / undefine following code / add code */
/* USER CODE END BeforeWriteBlocksSection */
/**
 * @brief  Writes block(s) to a specified address in an SD card, in polling mode.
 * @param  pData: Pointer to the buffer that will contain the data to transmit
 * @param  WriteAddr: Address from where data is to be written
 * @param  NumOfBlocks: Number of SD blocks to write
 * @param  Timeout: Timeout for write operation
 * @retval SD status
 */
__weak uint8_t BSP_SD_WriteBlocks(uint32_t *pData, uint32_t WriteAddr, uint32_t NumOfBlocks, uint32_t Timeout)
{
    uint8_t sd_state = MSD_OK;

    if (HAL_SD_WriteBlocks(&hsd1, (uint8_t *)pData, WriteAddr, NumOfBlocks, Timeout) != HAL_OK)
    {
        sd_state = MSD_ERROR;
    }

    return sd_state;
}

/* USER CODE BEGIN BeforeReadDMABlocksSection */
/* can be used to modify previous code / undefine following code / add code */
uint8_t BSP_SD_ReadBlocks_DMA(uint32_t *pData, uint32_t ReadAddr, uint32_t NumOfBlocks)
{
	uint8_t sd_state = MSD_OK;
	/* Invalidate the dma tx handle*/
	hsd1.hdmatx = NULL;

	/* Prepare the dma channel for a read operation */
	sd_state = SD_DMAConfigRx(&hsd1);

	if(sd_state == HAL_OK)
	{
		/* Read block(s) in DMA transfer mode */
		sd_state = HAL_SD_ReadBlocks_DMA(&hsd1, (uint8_t *)pData, ReadAddr, NumOfBlocks);
	}

	if( sd_state == HAL_OK)
	{
		return MSD_OK;
	}
	else
	{
		return MSD_ERROR;
	}
}
#if(false)
/* USER CODE END BeforeReadDMABlocksSection */
/**
 * @brief  Reads block(s) from a specified address in an SD card, in DMA mode.
 * @param  pData: Pointer to the buffer that will contain the data to transmit
 * @param  ReadAddr: Address from where data is to be read
 * @param  NumOfBlocks: Number of SD blocks to read
 * @retval SD status
 */
__weak uint8_t BSP_SD_ReadBlocks_DMA(uint32_t *pData, uint32_t ReadAddr, uint32_t NumOfBlocks)
{
    uint8_t sd_state = MSD_OK;

    /* Read block(s) in DMA transfer mode */
    if (HAL_SD_ReadBlocks_DMA(&hsd1, (uint8_t *)pData, ReadAddr, NumOfBlocks) != HAL_OK)
    {
        sd_state = MSD_ERROR;
    }

    return sd_state;
}

/* USER CODE BEGIN BeforeWriteDMABlocksSection */
/* can be used to modify previous code / undefine following code / add code */
#endif

uint8_t BSP_SD_WriteBlocks_DMA(uint32_t *pData, uint32_t WriteAddr, uint32_t NumOfBlocks)
{
	uint8_t sd_state = MSD_OK;

	// Invalidate the dma rx handle
	hsd1.hdmarx = NULL;

	// Prepare the dma channel for a read operation
	sd_state = SD_DMAConfigTx(&hsd1);

	if(sd_state == HAL_OK)
	{
		/* Write block(s) in DMA transfer mode */
		sd_state = HAL_SD_WriteBlocks_DMA(&hsd1, (uint8_t *)pData, WriteAddr, NumOfBlocks);
	}

	if( sd_state == HAL_OK)
	{
		return MSD_OK;
	}
	else
	{
		return MSD_ERROR;
	}

	return sd_state;
}

#if(false)

/* USER CODE END BeforeWriteDMABlocksSection */
/**
 * @brief  Writes block(s) to a specified address in an SD card, in DMA mode.
 * @param  pData: Pointer to the buffer that will contain the data to transmit
 * @param  WriteAddr: Address from where data is to be written
 * @param  NumOfBlocks: Number of SD blocks to write
 * @retval SD status
 */
__weak uint8_t BSP_SD_WriteBlocks_DMA(uint32_t *pData, uint32_t WriteAddr, uint32_t NumOfBlocks)
{
    uint8_t sd_state = MSD_OK;

    /* Write block(s) in DMA transfer mode */
    if (HAL_SD_WriteBlocks_DMA(&hsd1, (uint8_t *)pData, WriteAddr, NumOfBlocks) != HAL_OK)
    {
        sd_state = MSD_ERROR;
    }

    return sd_state;
}

/* USER CODE BEGIN BeforeEraseSection */
/* can be used to modify previous code / undefine following code / add code */
#endif
/* USER CODE END BeforeEraseSection */
/**
 * @brief  Erases the specified memory area of the given SD card.
 * @param  StartAddr: Start byte address
 * @param  EndAddr: End byte address
 * @retval SD status
 */
__weak uint8_t BSP_SD_Erase(uint32_t StartAddr, uint32_t EndAddr)
{
    uint8_t sd_state = MSD_OK;

    if (HAL_SD_Erase(&hsd1, StartAddr, EndAddr) != HAL_OK)
    {
        sd_state = MSD_ERROR;
    }

    return sd_state;
}

/* USER CODE BEGIN BeforeGetCardStateSection */
/* can be used to modify previous code / undefine following code / add code */
/* USER CODE END BeforeGetCardStateSection */
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

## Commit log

2026-04-10 Refactor uitask.c for improved key debounce logic and LCD handling
    - Fixed key debounce logic to only latch pressed state when stable.
    - Ensured lcd_need_updated flag is consistently checked under mutex.
    - Optimized LED control logic to reduce code duplication.
    - Added new ui_lcd_printline function for printing strings to specific LCD lines.
    - Updated metadata structures in nv_database.h for clarity and consistency.
    - Removed unnecessary includes and improved code formatting across multiple files.
    [main.h, maintask.c, uitask.c]
2026-04-19 Add CRC-32 implementation and OTA control block for firmware updates
    - Introduced a fast table-based CRC-32 implementation in crc32.h and crc32.c for efficient OTA image verification.
    - Created fram_addresses.h to define constants for CY15B116QN FRAM memory addresses, ensuring a single source of truth for address management.
    - Implemented ota_control_block.c and ota_control_block.h to manage the OTA Control Block with dual-copy storage in FRAM, including read/write protocols and CRC validation.
    - Added a standalone SHA-256 implementation in sha256.c and sha256.h for image integrity verification during OTA updates.
    - Updated project configuration to enable multi-threading and ensure thread sa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
2026-04-21 Add server verification plan and enhance OTA manager for firmware updates
    - Introduced `Server_Test_Plan.md` detailing the black-box testing strategy for the server, including design principles, directory layout, and phases of testing.
    - Updated `ota_manager_task.c` to support optional `:W.<seconds>` suffix in version response parsing, allowing for rollout wait times.
    - Modified URL construction in `ota_manager_task.c` to ensure proper formatting of device IDs.
    - Adjusted `claude.md` to include references to the new server test plan and server architecture documentation.
    - Updated `a7670_ssl_downloader.h` comments for clarity on firmware chunk downloading.
    - Changed server name and paths in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
2026-04-26 Mark Server Phase 1 complete — S1-1..S1-7 verified 2026-04-26
    /health confirmed live on robin-gpu: {"status":"ok"}
2026-04-26 Add Phase 2 database schema, migrations, and asyncpg pool
    - app/db/schema.sql: reference DDL for all 6 tables
    - app/db/migrations/0001: devices, weather_records (hypertable+compression),
    ingest_log, ota_campaigns, download_completions, admin_users
    - app/db/migrations/0002: bcrypt admin seed via Python migration
    - app/db/pool.py: asyncpg pool (min_size=2, max_size=20); init/close in lifespan
    - app/db/queries.py: skeleton (populated per phase)
    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
2026-04-26 Mark Server Phase 2 complete — S2-1..S2-6 verified 2026-04-26
    All 6 tables created, weather_records hypertable confirmed, asyncpg pool
    live (Application startup complete in gunicorn logs). DB_DSN uses Unix
    socket peer auth (not TCP localhost which requires scram-sha-256).
2026-05-05 Implement Server Phase 3 — mTLS ingestion path (S3-1..S3-7)
    - app/auth/mtls.py: X-SSL-Client-Verify dependency (403 on missing/failed)
    - app/ota/fixedpt.py: S9.7 int16 fixed-point ↔ float (scale 128)
    - app/ota/parser.py: parse_upload() — struct "<HHB" header + 18-byte records; Y2K epoch → TIMESTAMPTZ
    - app/db/queries.py: upsert_device, insert_ingest_log (ON CONFLICT idempotency), insert_weather_records
    - app/routers/weather.py: POST /api/v1/weather/upload — parse, upsert device, idempotency guard, bulk insert in single transaction
    - html/tests/test_parser.py: 9 unit tests covering round-trip ±1 LSB, max batch, epoch zero, error cases
    - pyproject.toml: pytest pythonpath + testpaths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
2026-05-06 Implement Server Phase 5 — OTA device endpoints (S5-1..S5-8)
    - app/ota/crc32.py: table-based CRC-32/MPEG-2 (poly 0x04C11DB7, init 0xFFFFFFFF,
    MSB-first); check value b"123456789"=0x0376E6E7 matches shared/crc32.c
    - app/ota/campaign.py: Campaign dataclass, get_active_campaign_for_device() (highest
    in_progress version, cohort filter), compute_wait() (zlib.crc32 slot algorithm)
    - app/db/queries.py: record_chunk_download() — ON CONFLICT DO NOTHING insert into
    download_completions
    - app/routers/ota.py: GET /api/v1/weather/ (metadata token V/L/H/W) and
    GET /api/v1/weather/get_firmware (chunk+CRC-32/MPEG-2); aiofiles non-blocking read;
    400/404/416/429 error paths; prefix shares /api/v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
2026-05-06 Mark Server Phase 5 S5-1..S5-7 complete — S5-8 pending server run
2026-05-06 Implement Server Phase 7 — Admin OTA campaign management (S7-1..S7-5)
    - POST /admin/firmware/upload: atomic write, auto-version, retention sweep
    - POST /admin/campaign/{id}/start: SHA-256 integrity check, cohort normalisation
    - POST /admin/campaign/{id}/pause|resume|cancel: state machine, success_rate
    - GET /admin/campaign/{id}: completed_device_count, eligible_device_count, slot info
    - 11 new DB helpers in queries.py (campaign CRUD + success rate computation)
    - server_test/lib/admin.py AdminClient + 22 T3-series integration tests
    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
2026-05-06 Implement Server Phase 8 — Admin UI (HTMX + Jinja2) (S8-1..S8-3)
    - app/auth/csrf.py: HMAC-signed stateless CSRF tokens (stdlib only)
    - app/templating.py: shared Jinja2Templates singleton
    - app/routers/ui.py: HTML routes — login/logout (cookie JWT), device
    dashboard with paginated table, campaigns page with firmware upload
    form, campaign list with start/pause/resume/cancel actions, campaign
    detail page with 15s HTMX polling progress
    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
2026-05-06 Update progress files: add server phases summary, fix deploy header
    - IMPLEMENTATION_STATUS.md: add Server Phases table (S1–S10) with
    current status and deploy/host reference
    - Server_Implementation_Plan.md: update header to reflect scp deploy
    (server has no git repo); record SSH key location
2026-05-07 Implement Server Phase 8 verification — Admin UI E2E tests (S8-4)
    T4-series tests (14 tests) in server_test/tests/test_admin_ui.py cover
    the full browser-simulated flow: login/CSRF, auth redirects, dashboard,
    device table, firmware upload, campaign start/detail/progress, logout.
    Two bugs found and fixed during test development:
    - POST /admin/logout route collision: ui.router shadowed by admin.router
    (included first in main.py); renamed UI route to /logout-ui and updated
    base.html form action accordingly.
    - delete_cookie in logout handler was missing httponly=True, samesite=strict
    to match the original set_cookie attributes; fixed in ui.py.
    14/14 T4 tests + 7/7 T6 auth tests pass on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
2026-05-07 Complete Phase T4 mTLS & Nginx test coverage
    Add test_mtls.py with 6 active T4 tests (T4-1 no-cert 403, T4-2
    wrong-CA 403, T4-4 admin path not-403, T4-5 rate-limit 503, T4-7
    TLS 1.2 accept/1.1 reject, T4-8 spoofed header isolation). Add
    base_url/ca_bundle/device_cert fixtures to conftest.py and
    cryptography to requirements.txt. Mark all T4 items done in
    Server_Test_Plan.md; update IMPLEMENTATION_STATUS.md S4 entry.
2026-05-08 Add integration tests for sensor data and user management
    - Implemented Phase 11 Sensor Data Browse UI integration tests (test_sensor_data.py) to verify functionality of the sensor data table, including filters and pagination.
    - Created User Management black-box tests (test_user_management.py) covering user creation, updates, password changes, and deletions, ensuring proper role-based access control and error handling.
2026-05-08 Production cleanup: fix blocking IO, startup validation, nginx config
    - main.py: validate JWT_SECRET (non-empty, ≥32 chars, not the example
    default) at startup alongside FIRMWARE_DIR check
    - admin.py: offload campaign_start SHA-256 integrity check to
    asyncio.to_thread() — avoids blocking the event loop on 480 KB reads;
    add ^\d{6}$ validation on target_cohort_ids in StartCampaignRequest
    - nginx/iot_server.conf: resolve {html_dir} placeholder to
    /home/akp/html (production path); drop stale replacement comment
    - deploy.sh: add nginx -t + reload after config copy; add set -euo pipefail
    to remote block so deploy fails fast on any error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
2026-05-11 docs: compact project markdown to current state
    Heavy rewrite of all project docs: drop phase-by-phase history and
    resolved-question rationale, collapse completed phases to summary tables,
    reduce ~57% of lines (3997 → 1725). AGENTS.md / GEMINI.md now point at
    CLAUDE.md as single source of truth.
2026-05-11 feat: add platformio support and improve UART error handling
2026-05-12 feat: Implement initial device communication framework
    - Added DeviceController class to manage device connections on the UI thread.
    - Introduced DeviceIO class for handling IO operations on a separate thread.
    - Created FrameParser class for parsing binary frames according to the Robin Weather Station protocol.
    - Implemented LogBuffer for in-memory logging of session events.
    - Developed MainWindow UI for scanning and displaying available USB devices.
    - Established shared protocol definitions in the shared directory, including command structures and error codes.
    - Added scaffolding for unit tests in the tests directory.
2026-05-14 feat(host): Phase 0 — shell rewrite, 5-tab UI, icon, banner
    Replace smoke-test MainWindow with the real application shell:
    - mainwindow.ui: 5-tab QTabWidget (Status, Current Measurement,
    General Settings, Sensor Settings, About) + Help menu with
    Debug Log… (Ctrl+L) and About actions + hidden banner QLabel
    - mainwindow.h/cpp: remove scan scaffold, add showBanner/hideBanner
    with BannerKind (Info/Warning/Error) + styled QLabel
    - main.cpp: QApplication::setWindowIcon from Qt resource
    - resources/icons/robin_wsc.png: copied from screenshots/Icon.png
    - resources/robin_wsc.qrc: register icon
    - IMPLEMENTATION_STATUS.md: add Host Application section with H0-H2
    (backend, done) and Ph0-Ph9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
    [main.cpp]
2026-05-14 chore: add H1 FrameParser row to verification suites table
2026-05-14 feat(host): Ph1 — connection lifecycle, device picker dialog
    - DevicePickerDialog: modal QListWidget listing all matching devices by
    port name + serial number; OK/double-click accepts, Cancel dismisses
    - MainWindow gains DeviceController*, initialise(), scanAndConnect():
    0 devices → warning banner; 1 device → auto-connect; 2+ → picker dialog
    - onConnected/onDisconnected update status bar and banner
    - onProtocolMismatch shows non-modal warning banner
    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
2026-05-14 feat(host): Ph2–Ph9 — full UI implementation, tests, packaging
    Implements all remaining host application phases against the
    host_implementation_plan.md spec:
    - Ph2: DeviceController typed API (statusReceived, weatherReceived,
    metaReceived, rtcReceived, *WriteAck signals; 1500 ms per-request
    timeout; meta cache with invalidation)
    - Ph3: Status tab — 11 LED indicators, RTC display, Update RTC,
    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
2026-06-08 feat: add MS5611 sensor support and custom delay function
2026-06-11 fix: update RTC wakeup timer configuration and correct BMP390 data parsing
    [rtc.c]
2026-06-12 fix: increase FreeRTOS heap size and update MCP23017 I2C transmission error handling
    [uitask.c, weather-station.ioc]
2026-07-01 Refactor code structure for improved readability and maintainability
    [Core.schdoc, I2C-Sensor-PCB-Backup.pcbdoc, I2C-Sensor-PCB.pcbdoc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]

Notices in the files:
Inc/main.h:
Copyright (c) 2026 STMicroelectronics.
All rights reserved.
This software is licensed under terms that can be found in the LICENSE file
